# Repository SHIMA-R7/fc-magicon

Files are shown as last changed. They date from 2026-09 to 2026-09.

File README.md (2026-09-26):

# FC-MAGICON

Waveshare Core2350B(RP2350B)1枚で作るファミコン用カセット。

- PRG・CHR を RP2350B がリアルタイムにエミュレート(マジコン。NROM/CNROM/UNROM/MMC1/MMC3 などをファームで実装)
- NSF 再生(バンク切り替え・WRAM 対応。拡張音源は PWM で46番に混ぜる)
- PC→FC 画面転送(PPU の読み出しに直接応答する FC-PICO 方式)

## 現状(2026-09-26)

- **基板 rev0.2 の設計が完了(2層、DRC エラー0・未接続0)。未発注・未実装。**
- ファームウェア: 動作確認用の `bus_test`(CPU バスでテスト ROM を返して音を鳴らす)と `chr_test`(PPU に CHR を返して画面に格子模様を出す)、
  マジコン本体の `magicon`(.nes を動かす。NROM/MMC1/UxROM/CNROM/MMC3/AxROM、PRG + CHR 384KB まで)を作成、ビルド済み。未実機。[`firmware/`](firmware/README.md)
- rev0.1 からの変更: USB の予備ランド(J6)、拡張音源の音量用の半固定抵抗 VR1(KOA KVSF637AC104)を追加、
  電源・音声の配線を太くした(+5V 0.8mm、VBUS 0.6mm、GND 0.5mm、+3V3 0.4mm、音声 0.4mm)、J5 の 12〜14番を GND に。
- ガーバー: [`kicad/FC-MAGICON_gerber_r0.2.zip`](kicad/FC-MAGICON_gerber_r0.2.zip)(発注の指定は下の「基板の発注」)
- 仕様書: [`docs/hardware_spec.pdf`](docs/hardware_spec.pdf)(rev0.2)

| 正面(部品面、本体の手前) | 背面 |
|---|---|
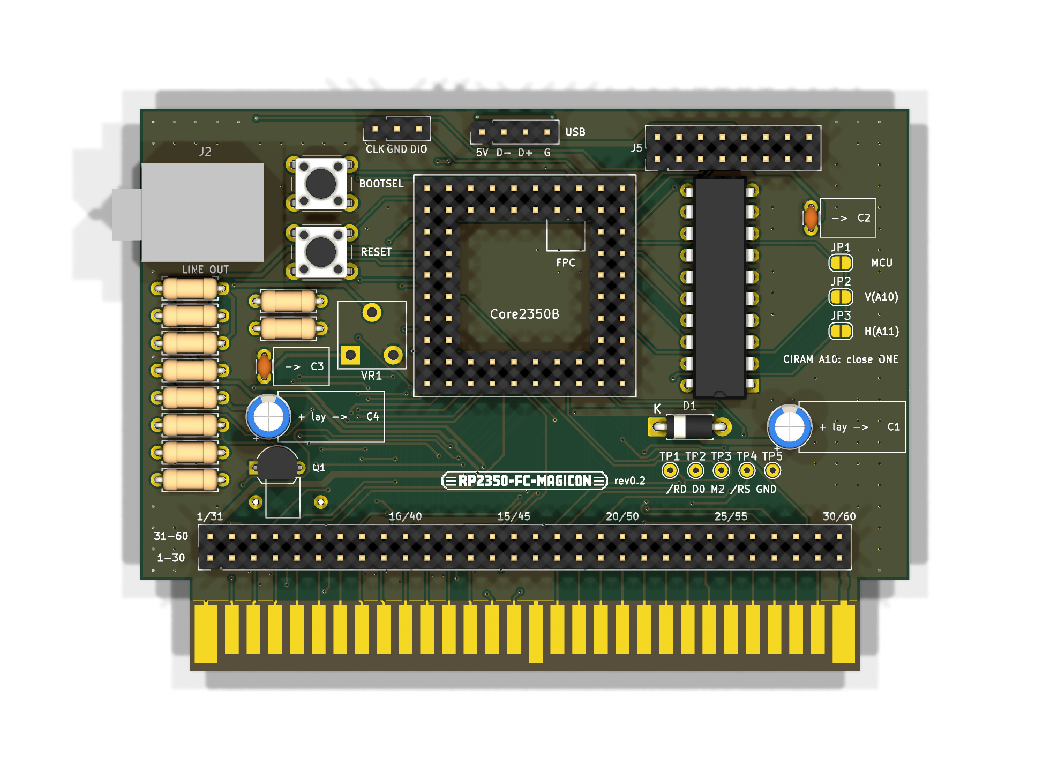
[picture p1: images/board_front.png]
front
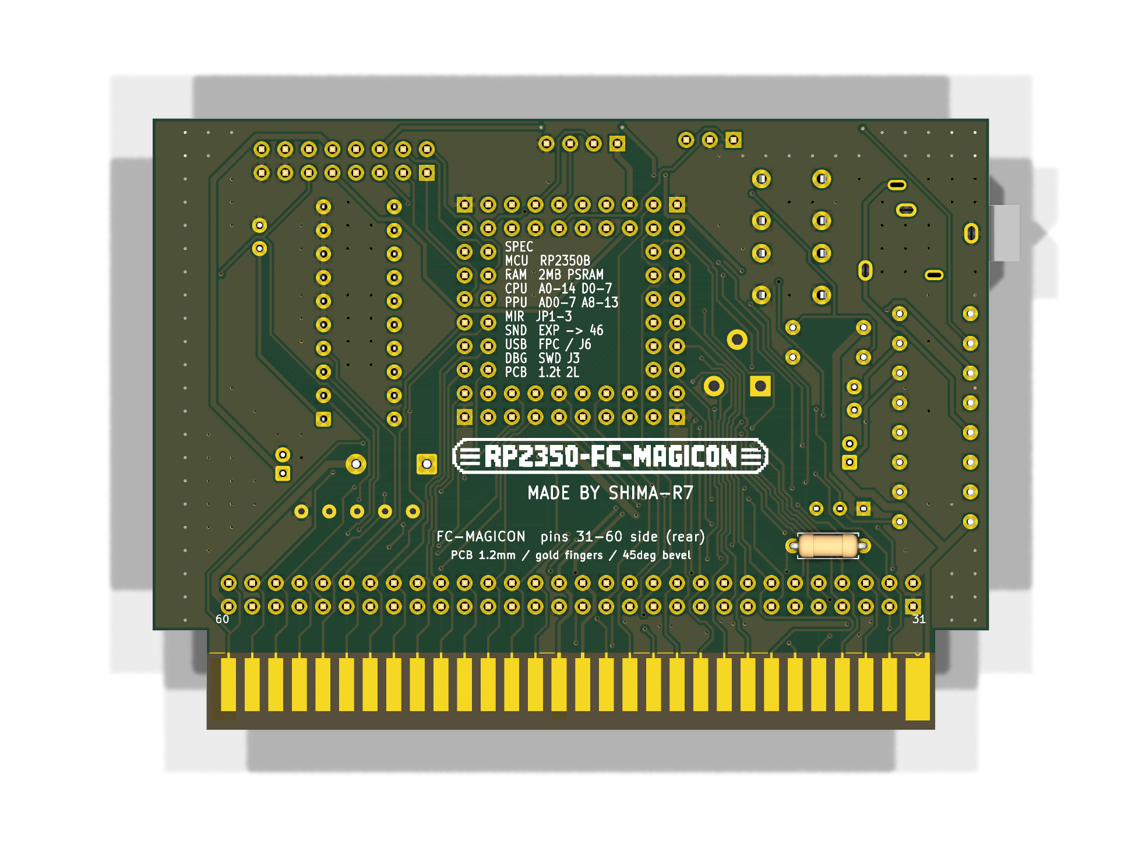
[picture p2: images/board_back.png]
back
|  |  |

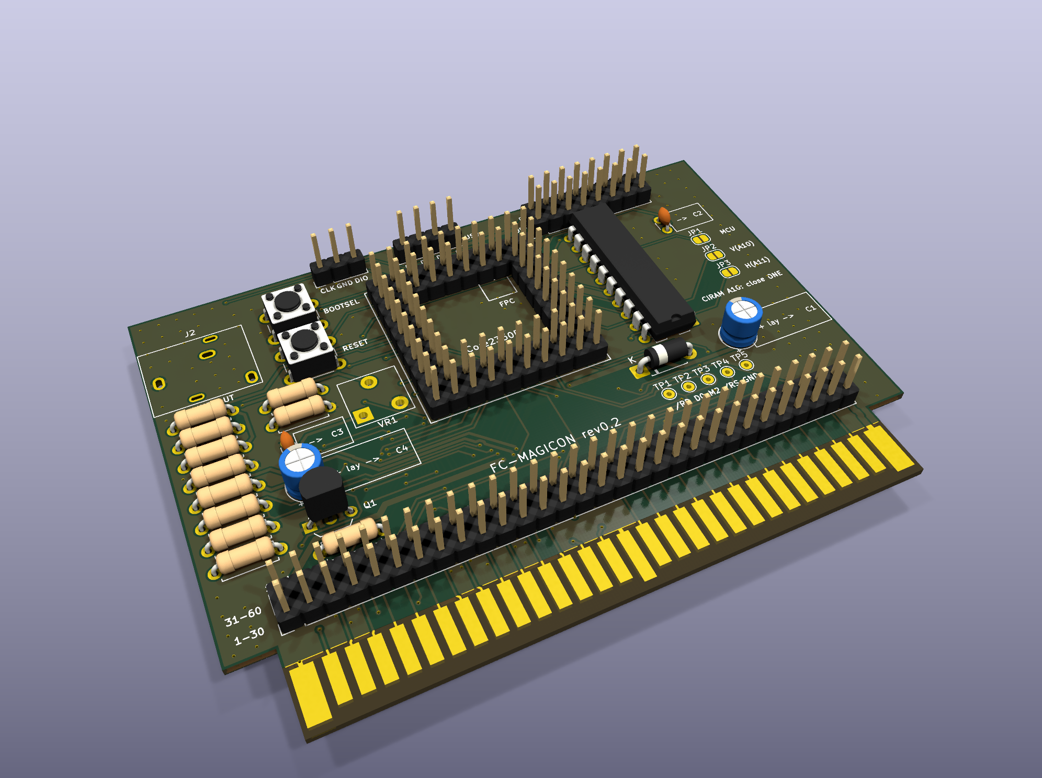
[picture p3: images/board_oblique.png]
oblique


## ファイル

| パス | 内容 |
|---|---|
| `kicad/gen_schematic.py` | 回路図の生成スクリプト(`python gen_schematic.py` → `FC-MAGICON.kicad_sch`) |
| `kicad/gen_footprints.py` | カセット端子と半固定抵抗(KOA KVSF637A)のフットプリントを生成 |
| `kicad/build_pcb.py` | 基板の部品配置(`place`)、配線の取り込みと GND ベタ(`import`)、一部の配線のやり直し(`reroute`) |
| `kicad/route.py` | Freerouting で自動配線(線幅のクラスを付ける) |
| `kicad/add_part.py` / `sync_nets.py` / `hand_route.py` | 配線済みの基板に部品を足す / パッドのネットを回路図に合わせる / 1本だけ手で引く |
| `kicad/export_gerbers.ps1` | DRC がエラー 0 のときだけガーバーを出して zip にする |
| `kicad/bom.py`, `print_bom.ps1` | 部品表(`bom.csv`)の作成と印刷 |
| `kicad/print_core2350b_pinmap.ps1`, `print_fit_check.ps1` | Core2350B のピン照合シート、実寸の現物合わせシートの印刷 |
| `kicad/check_nets.py`, `drc_summary.py` | 回路図の簡易チェック、DRC レポートの集計 |
| `3d/` | 基板の STEP(`FC-MAGICON_r0.2_parts.step` 部品あり / `_board.step` 基板だけ / `FC-MAGICON.step` 部品あり版を Autodesk で読み込んで書き出し直したもの)。`make_models.py` → `export_step.py`(KiCad の Python)で作り直す。原点は基板の左上、Y は上向き(基板は Y 0〜-65.8) |
| `kicad/print_part_guide.ps1` | 部品案内図(表・裏、原寸)の印刷 |
| `case/label/` | カセット表面のシール(`make_label.py` → `label.png`、`print_label.ps1` で A4 に印刷)。99 x 60.6mm、ケースの穴(J3/J5/J6/VR1/SW/Core2350B2)は原寸。L 判の光沢紙にきれいに刷る時は `make_label.py --px 48 --out label_print.png` → `powershell.exe -File print_label_photo.ps1`(光沢紙・写真品質) |
| `case/*.py` | ケースの元データ(下記)の寸法を調べたスクリプトと、基板の部品の占有範囲(`parts.json`) |
| `docs/` | ハードウェア仕様書(`build_spec.py` と `kicad/gen_spec_tables.py` で作る) |

KiCad 10、Freerouting 2.4.1 を使用。KiCad の Python(pcbnew)で実行するスクリプトと、ふつうの Python で実行するスクリプトがある(各ファイルの先頭に記載)。

## ライセンス

MIT(`LICENSE`)。外形の参考にしたデータ(下記「カセット外形の参考データ」)はこのリポジトリに含めていない。

## ピン割り当て

| GPIO | 信号 | カセット端子 | 備考 |
|---|---|---|---|
| 0-7 | CPU D0-D7 | 43,42,41,40,39,38,37,36 | |
| 8-22 | CPU A0-A14 | 13,12,11,10,9,8,7,6,5,4,3,2,33,34,35 | A0から連続 |
| 23 | /ROMSEL | 44 | |
| 24 | CPU R/W | 14 | |
| 25 | M2 | 32 | |
| 26-33 | PPU AD0-AD7 | 26,27,28,29,60,59,58,57 | /RD直前はアドレス下位、その後データ |
| 34-38 | PPU A8-A12 | 51,52,53,54,55 | 26-38で13ビット連続 |
| 39 | (基板上LED) | — | バスに使わない |
| 40 | PPU /RD | 17 | U2(74LVC245)経由 |
| 41 | PPU /WR | 47 | U2経由 |
| 42 | PPU A13 | 56 | U2経由 |
| 43 | CIRAM A10 出力 | 18 | JP1を閉じたとき |
| 44 | 拡張音源 PWM | 46へ混ぜる | |
| 45 | /IRQ 駆動 | 15 | Q1(NPN)でオープンコレクタ |
| 46 | 本体5V検出 | 30,31 を分圧 | Highになるまでバスに出力しない |

- PIO の32本窓: CPU 用ブロックは GPIO0-31、PPU 用ブロックは GPIO16-47。
- GPIO0-38 は 5V トレラント。GPIO40-47 は ADC 兼用で **5V 非トレラント**。
- PPU A0-A7(19-25, 50番)はつながない。
- CIRAM /CE(48)は /A13(49)に直結(R1 0Ω)。
- ミラーリング: JP1(MCU)/ JP2(A10=垂直)/ JP3(A11=水平)のどれか1つだけ閉じる。

## テスト用のランド(2.54mmピッチ、ピンヘッダー・ソケットどちらも可)

基板は規格(56.8mm)より 9mm 高い(90 × 65.8mm)。

**J4: カセット60ピン全部(2x30)** — 差し込み部のすぐ上(2026-09-26、2層に収めるため上辺から移動)
各列がカセット端子の真上にあり、端子から J4 まではほぼ真上への短い配線。上の列 = 31〜60番、下の列 = 1〜30番。
部品面(本体の手前)から見て左端が 1/31番、右端が 30/60番(シルクに列番号あり)。
RP2350 では使わない PPU A0-A7(19〜25番、50番)も出している。

**J5: 基板内部の信号(2x8)** — 上辺
部品面から見て左端が 1/2番。奇数番 = 下の列、偶数番 = 上の列。

| ピン | 信号 | ピン | 信号 |
|---|---|---|---|
| 1 | PPU /RD(3.3V、U2の後) | 2 | PPU /WR(3.3V) |
| 3 | PPU A13(3.3V) | 4 | CIRAM A10(GPIO43の出力) |
| 5 | 拡張音源 PWM(GPIO44) | 6 | PWM の RC フィルタの後 |
| 7 | /IRQ 駆動(GPIO45) | 8 | 本体5V検出(GPIO46) |
| 9 | +3.3V | 10 | VBUS(モジュールの電源) |
| 11 | CIRAM A10(18番へ行く線) | 12 | ライン出力(47kの前) |
| 13 | Q1 ベース | 14 | ライン出力(100Ωの後) |
| 15 | GND | 16 | GND |

TP1〜TP5(/RD、D0、M2、/ROMSEL、GND)はオシロのプローブ用。

## 基板発注前に確認すること

1. ~~**カセット端子の電源・音声・制御ピン。**~~ → 2026-09-26 ユーザーが麻雀カセット・本体で確認、問題なし。 信号線51本はダンパー(`../FC`)で実機確認済み。
   1,16(GND)・30,31(+5V)・15(/IRQ)・18(CIRAM A10)・45,46(音声)・47(/WR)・48(CIRAM /CE)・49(/A13)は
   nesdev の資料によるので、麻雀カセットと本体で導通を確認する。
2. ~~**45/46 の向き。**~~ → 2026-09-26 確認済み。 本体(HVC-CPU-07)で、どちらが 2A03 の音声回路につながっているか確認する。
3. ~~**本体の /IRQ プルアップの有無。**~~ → 2026-09-26 確認済み。 無ければ R6(10k)を実装する。
4. ~~Core2350B のヘッダー配置~~ → 2026-09-26 に照合シート(`kicad/print_core2350b_pinmap.ps1`)で、実物のシルクと全ピン一致を確認した。
   25.4mm角、外周2列、2.54mmピッチ。左・下・右・上がそれぞれ P1・P3・P4・P2。
5. ~~カセットの基板厚とエッジの寸法~~ → 参考データ(下記)から、厚み 1.2mm・差し込み部 78.4 × 10.7mm。
   正確に作るのはスロットに刺さる部分だけでよい。残りの外形は自由にし、ケースは3Dプリント(Bambu P1S)で作る。
6. **試作での実測。** PPU の /RD が下がってからデータを返すまでの時間。仮配線はせず、この基板(TP1〜TP5)で測る方針に変更。

## 基板の発注(JLCPCB)

`kicad/FC-MAGICON_gerber_r0.1.zip` をアップロードする(`kicad/export_gerbers.ps1` で作り直せる。DRC にエラーがあると止まる)。

| 項目 | 指定 |
|---|---|
| 層数 | 2 |
| 厚み | **1.2mm**(ファミコンのスロットに合わせる。1.6mm は入らない) |
| 金メッキ端子 | Gold Fingers: Yes |
| 面取り | 差し込み側 45°(finger chamfer) |
| 表面処理 | 金メッキ端子と組み合わせられるもの(発注画面で ENIG 指定が必要か確認する) |
| 数量 | 5枚(最小) |

- 外形は 90 × 65.8mm。差し込み部(78.4 × 10.7mm)の両脇は切り欠き。
- 端子部のレジストは、端子の上端から 0.6mm 上で止めてある(付け根側の配線はレジストで覆う)。

## カセット外形の参考データ(`ref/`)

| 出典 | ライセンス | 中身 |
|---|---|---|
| [Gumball2415/NES-Famicom-Cartridge-Dimensions](https://github.com/Gumball2415/NES-Famicom-Cartridge-Dimensions) | TAPR OHL 1.0 | HVC-TGROM-01 / HVC-CNROM-256K-01 の外形(KiCad)と FreeCAD 3Dモデル(.FCStd、STEP書き出し可) |
| [Keitark/fc-rom-vomitter](https://github.com/Keitark/fc-rom-vomitter) | ハード: CC BY-SA 4.0 | 60ピンのエッジのフットプリントと、実際に製造したファミコン用基板 |

- 標準のファミコン基板: 幅 90.0mm × 高さ 56.8mm(差し込み部 78.4 × 10.7mm を含む)、**厚み 1.2mm**、ピッチ 2.54mm。
- 市販カセットは 1〜30番がラベル面(本体の手前)。この基板は部品面(F.Cu)を手前に向けたので、F.Cu = 1〜30番、B.Cu = 31〜60番。
- ピン配置は fc-rom-vomitter の表とも一致した(30/31=+5V、1/16=GND、45=本体からの音声、46=本体へ戻す音声、48/49=/A13)。
- ファイルをそのまま流用する場合は、元のライセンスに従うこと。寸法(事実)を参照して自作するならその限りではない。

## ケース(3Dプリント)の元データ

[printables 860420「Nintendo Famicom Cartridge Shell」](https://www.printables.com/model/860420-nintendo-famicom-cartridge-shell)(CC BY 4.0)。
これは [masible/famicom-everdrive-n8-shell-with-usb](https://github.com/masible/famicom-everdrive-n8-shell-with-usb)(hadessuk、CC BY)を
標準の基板向けにしたリミックスで、さらに元は Blackchamber の [Thingiverse 117607](https://www.thingiverse.com/thing:117607/)(CC BY)。
改変版を公開するときは、この3つの作者の表記を残す。

## 注意

- USB だけで給電しているときに本体のバスへ出力すると、電源の入っていない本体に電流が逆流する。
  ファームは `FC_5V_SENSE` が High になるまで、全ピンを入力にしておく。
- RP2350 のエラッタ E9 に注意。バスのピンでは内部プルダウンを使わない。
- Q1 の 2SC1815 は、平らな面から見て E-C-B。

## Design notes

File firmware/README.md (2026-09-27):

# FC-MAGICON ファームウェア

pico-sdk 2.3.1、RP2350B(Waveshare Core2350B2)。ボード定義は `boards/fc_magicon.h`
(SDK の `waveshare_core2350b.h` から、UART・I2C・SPI の既定ピンを外したもの。GPIO0/1 などはバスに使っているため)。

## ビルド

```
pwsh -File build.ps1
```

- 道具は `C:\Users\Yugo\pico` に置いてある(2026-09-26 に GitHub の公式リリースから取得):
  xPack arm-none-eabi-gcc 15.2.1、CMake 4.4.3、Ninja 1.13.2、pico-sdk 2.3.1 + TinyUSB、picotool / pioasm 2.3.1。
- パスに日本語が入るとビルドできないので、`C:\Users\Yugo\pico\work\fc-magicon` にコピーしてからビルドする。
- できた `.uf2` は `out/` に入る。

## 書き込み

1. Core2350B を USB(FPC アダプター)で PC につなぐ。
2. 基板の **BOOTSEL** を押したまま **RESET** を押して離す → PC に「RP2350」ドライブが出る。
3. `out/bus_test.uf2` をそのドライブにコピーする。

## bus_test(基板が届いて最初に試す)

CPU バスの読み出し・書き込みが正しく動くかを確かめる。PPU 側(CHR)はまだ返さない(画面は出ない)。

| 動作 | 内容 |
|---|---|
| 起動直後 | バスのピンをすべて入力(プル無し)にする。本体の 5V(GPIO46)が来るまで、LED が速く点滅し、USB シリアルに `waiting for Famicom 5V` を出す |
| 本体の電源が入ったら | 250MHz で動かし、$8000-$FFFF にテスト ROM(16KB、`gen_test_rom.py`)を返す |
| テスト ROM | 矩形波 1ch で約 440Hz を鳴らし続け、ループのたびに $8000 へ書き込む |
| RP2350B | その書き込みを数え、65536 回ごとに LED を反転(約 0.5 秒ごと)。USB シリアルに毎秒の読み出し・書き込みの回数を出す |

### 立ち上げの手順

1. **モジュールを載せる前に**、テスターで +5V(J4 の 30/60 列など)と GND の間がショートしていないか確かめる。
2. モジュールを載せ、**本体に挿さずに** USB だけつなぐ。LED が速く点滅し、シリアルに `waiting for Famicom 5V` が出れば、
   RP2350B は動いていて、バスには何も出力していない。
3. 本体の電源を切った状態で挿し、電源を入れる。
   - **ピーという音が出て、LED が約 0.5 秒ごとに点滅**すれば、CPU バスの読み出しと書き込みが動いている。
   - シリアルの `writes/s` はおよそ 12 万(1 ループ 15 サイクル、CPU 1.79MHz)。
   - 音が出ない時は、本体のリセットボタンを押す(RP2350B の起動が本体の CPU に間に合わなかった可能性)。
4. うまくいかない時は、TP3(M2)・TP4(/ROMSEL)をオシロで見て、/ROMSEL が動いているか確かめる。

## chr_test(bus_test が動いたら次に試す)

PPU 側の応答、特に「/RD が下がる直前に AD0〜AD7 から下位アドレスを読む」方式が実機で成り立つかを確かめる。

| 動作 | 内容 |
|---|---|
| CPU 側 | テスト ROM(`gen_chr_rom.py`)がパレットとネームテーブル(0〜255 を繰り返し)を書き、背景を表示し、音を鳴らす |
| PPU 側 | パターンテーブル($0000-$1FFF)の読み出しに、RP2350B が作った CHR を返す。A13 = 1(ネームテーブル)の時は出さない |
| タイル | タイル t は下位2ビットの色で塗り、上辺と左端は色1(白)の線 |
| CIRAM A10 | GPIO43 を Low に固定(JP1 を閉じた時は1画面ミラー)。JP2/JP3 でもよい |

**判定**

- 画面に **4色の縦縞と、8ドットごとの白い格子** が並べば、下位アドレスの読み取りは正しい。
- 模様が崩れる・縞の順番が乱れる時は、読み取るタイミングがずれている。TP1(/RD)と TP2(PPU D0)をオシロで見て、
  /RD が下がってからデータが出るまでの時間と、PPU がデータを取り込むまでの余裕を測る。
- USB シリアルの `ppu chr/s` は、表示中におよそ 500 万前後になる見込み(1 ラインあたりの読み出し × 240 ライン × 60 フレーム)。

## magicon(マジコン本体。bus_test・chr_test が動いたら)

フラッシュに書いた `.nes` をファミコンで動かす。

```
pwsh -File load_rom.ps1 game.nes
```

- Core2350B を USB でつないだまま実行する。magicon が動いていれば picotool が自動で書き込みモードにし、書いた後に再起動する
  (ほかのファームウェアの時は BOOTSEL を押したまま RESET を押して離してから)。書いたらファミコンの電源を入れ直すかリセット。
- ROM はフラッシュの 8MB 目に置く(`tools/nes_pack.py` が「"FCMG" + 長さ + 合計」を前に付ける)。ファームウェアを書き直しても消えない。
- ROM が無い・壊れている・対応していない時は、chr_test と同じ試験画面を出す。USB シリアルに理由を出す。

| 項目 | 内容 |
|---|---|
| マッパー | 0 NROM、1 MMC1、2 UxROM、3 CNROM、4 MMC3、7 AxROM、87 Jaleco J87(ツインビー)、184 Sunsoft-1(アトランチスの謎) |
| 大きさ | PRG + CHR の合計 384KB まで(RP2350 の SRAM に写す)。SMB3(256K + 128K)まで入る。512KB の MMC3 はまだ |
| CHR-RAM | 8KB。CPU の `$2006`/`$2007` への書き込みを横から読んで作る(PPU の /WR ではアドレスが読めないため) |
| WRAM | `$6000-$7FFF` 8KB。**電源を切ると消える**(バッテリーのセーブはまだ) |
| ミラーリング | PIO2 が PPU A10 / A11 を CIRAM A10(GPIO43)へ写す。**JP1 を閉じた時だけ効く**(JP2 / JP3 は固定) |
| MMC3 の IRQ | PPU の読み出しで A12 の立ち上がりを数え、GPIO45 → Q1 で /IRQ を出す |
| USB シリアル | ROM の情報と、1 秒ごとの CPU サイクル(約 179 万)・PPU 読み出し・書き込みの回数 |

CPU バスは bus_test と違い **M2 で起きて全サイクルを拾う**(`magicon/cpu_m2.pio`)。M2 が上がって 80ns 後にアドレスを読み、
書き込みサイクルは M2 が下がった所でデータをもう一度読む。bus_test(/ROMSEL で起きる)が動いて magicon が動かない時は、
この 80ns と、書き込みデータを読む時点を疑う。

### ゲーム選択メニュー

```
pwsh -File load_rom.ps1 -Library D:\roms            # フォルダーの .nes / .nsf を全部(動かないものは飛ばす)
pwsh -File load_rom.ps1 -Library a.nes b.nsf -Remote # ファイルを並べても。-Remote で「REMOTE DESKTOP」も入れる
```

- 何本かをまとめてフラッシュの ROM 置き場(8MB 目から 8MB 分、127 本まで)に書き、起動時にメニューから選ぶ。
  形式は `tools/nes_pack.py --library`: `"FCLB"` + 目次(題名 48 + 位置 + 長さ + 合計、64 バイト × 数)+ 中身。
  題名はファイル名(大文字)か NSF の曲集の題名、同じフォルダーの `titles.txt`(`ファイル名=題名`)で変えられる。題名順に並ぶ。
- メニュー(`magicon/gen_menu_driver.py` → `menu_driver.h`)は NROM として動く。ファームが起動時に題名を入れて組み立てる
  (`cart_load_menu`)。フォントとロゴは NSF プレイヤーの CHR。上下 = 選ぶ(押し続けると続けて動く)、左右 = 20 項目ずつ、A / START = 始める。
- 選ぶと、本体側は本体 RAM($0300)に写した小さなプログラムに移って `$5FF0` に番号を書き、1.5 秒待ってから `JMP ($FFFC)`。
  ファームはその番号をウォッチドッグのメモ(scratch[0])に残して再起動し、その ROM で起動し直す(今までの起動の流れをそのまま使う)。
- **本体の電源を入れ直すとメニューに戻る**: 5V が 50ms 続けて消えたら再起動する(USB から電源をもらっている時も)。
  本体のリセットボタンは、今のゲームの最初に戻るだけ。
- 1 本だけの書き方(`load_rom.ps1 game.nes`、`"FCMG"`)もそのまま使える。ライブラリが 1 本だけの時はメニューを出さない。
- 2026-09-27、PC の試験台(`sim/sim.exe ライブラリ.bin --press ...`)で確かめた: 手元の 12 本 + 画面転送の 13 項目 / 37 項目で、
  表示、押し続けの連続移動、左右のページ送り、選んで 1.5 秒後にマリオのタイトル・NSF プレイヤー・画面転送の待ち画面になること。
  **実機では未検証**(本体側が $0300 のプログラムで待っている間に RP2350 が再起動して間に合うか)。

### NSF プレイヤー

`.nsf` を書くと NSF プレイヤーとして起動する(`pwsh -File load_rom.ps1 music.nsf`)。

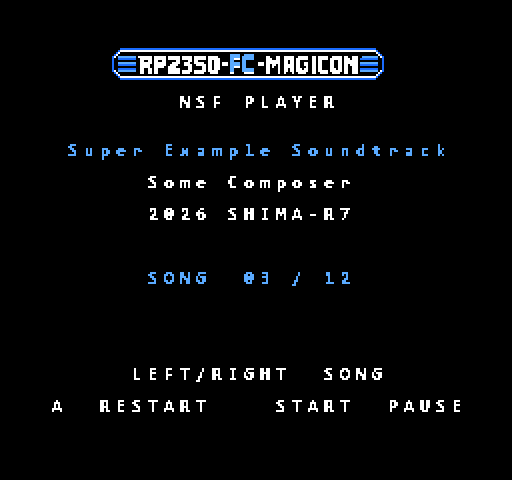
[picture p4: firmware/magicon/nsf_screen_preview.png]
NSF の画面(曲名などは例)


| 項目 | 内容 |
|---|---|
| 操作 | ←→ = 前 / 次の曲、A = 最初から、START = 一時停止 |
| 再生 | VBlank の NMI(約 60.1Hz)ごとに PLAY を呼ぶ。再生間隔が標準と違う NSF はテンポが変わる |
| バンク切り替え | `$5FF8-$5FFF`(4KB × 8)。384KB まで |
| 拡張音源 | **まだ鳴らない**(VRC6・FDS・N163 など。本体の 2A03 の音だけ出る) |
| 未対応 | load が `$8000` より下のバンク無し NSF、FDS 用の `$6000-$DFFF` を RAM にする NSF |

しくみ(ハードウェアの NSF プレイヤーでよく使われる形):

- 曲のデータは `$8000-$FFFF`、ドライバー(6502、`magicon/gen_nsf_driver.py` が作る)は `$5000-$5FFF` に置く。
  どちらも RP2350 の SRAM。`$5000-$5FFF` は本体側に何も無いので、カセットが自由に使える。
- ベクター(`$FFFA-$FFFF`)の読み出しだけ、曲のデータではなくドライバーの番地を返す。
- ドライバーは曲を始める時に APU を黙らせ、RAM と `$6000-$7FFF` を 0 にし、バンクを初期値に戻してから INIT を呼ぶ(NSF の決まり)。
  ドライバーの変数はゼロページではなく `$5F80-` に置く(NSF がゼロページを自由に使うため)。
- `magicon/test_nsf_driver.py` が、6502 エミュレーター(py65)でドライバーを動かして確かめる
  (INIT に渡る曲番号、毎フレームの PLAY、←→・A・START、RAM の初期化、バンク切り替え)。

### 画面転送(リモートデスクトップ)モード

`pwsh -File load_rom.ps1 -Remote` で、PC の画面をファミコンに映すモードで起動する。PC 側は:

```
python tools/remote_pc.py             # 灰色 4 階調(文字が読みやすい)。--color でカラー、--port COMx でポートを指定
python tools/remote_pc.py --dry-run 30   # カセット無しで、画面の取り込み + 変換の速さだけ測る
```

| ファミコン側 | PC 側 |
|---|---|
| 1コン 十字キー / A / B | マウス移動(押し続けると速くなる)/ 左クリック / 右クリック |
| 1コン SELECT / START | 画面全体を縮小 ⇔ カーソルのまわりを等倍 / 等倍の時にカーソルを追うか止めるか |
| ファミリーベーシックのキーボード | 同じ刻印のキー(JIS 配列の位置)。STOP / DEL = BackSpace、カナ = 半角/全角、CLR HOME = Home。SHIFT / GRPH(Alt)/ CTR はトグル(RETURN で SHIFT は戻る) |

キーボードのふるまいは、前に作った拡張端子 ⇔ USB 変換器([SHIMA-R7/Famicom-Expand-USB-Adapter](https://github.com/SHIMA-R7/Famicom-Expand-USB-Adapter)、実機で確かめたもの)に合わせた:
キーの並び(9 行 x 8)は nesdev と一致、列を選んでから読むまで 500us 待つ(300us は不安定だった)、1 キーずつのチャタリング対策(2 回続けて同じなら確定)、
トグル式の SHIFT / GRPH / CTR。`tools/test_keyboard_bridge.py` が、キーを実際には送らずにこのふるまいを確かめる。

- 使うのは Python に元からあるものと Pillow・numpy だけ(COM ポート・画面の取り込み・マウスとキーは Windows の API を ctypes で呼ぶ)。
- 入力が 0.5 秒届かない時(ケーブルが抜けた等)と止めた時は、押しっぱなしのキーとボタンを離す。
- PC 側の速さ(2026-09-27、この PC): 等倍 約 60fps、画面全体 灰色 約 30fps / カラー 約 23fps。
- USB の速さ(2026-09-27、Core2350B2 単体に `usb_test.uf2`): `tools/usb_bench.py` で 614KB/秒 = 最大 40.6 枚/秒(150 枚すべて届く)。
  `remote_pc.py` をそのまま流して 灰色 29.8 / カラー 20.0 枚/秒(PC 側で画面を作る速さで決まる)。
  はじめは画面を作る → 送るを順番にやっていて 15 枚/秒しか出なかったので、送受信を別スレッド(`IoThread`)にした。
- `usb_test/`: ファミコン無しで USB の速さを測るファームウェア。画面転送モードと同じ読み方で受け取って捨て、FCIN を 60 回/秒返す
  (何も押していない。予備の 2 バイトに受け取った枚数)。

- PPU が背景のパターンを読みに来るたびに、その位置の 8 ドットを RP2350 が返す(ネームテーブルは「行 % 8 * 32 + 列」の並びにし、
  読みに来たタイル番号と行の中の y から位置を割り出す。8 行ごとの組は、タイル行が 7 → 0 になる回数で数える)。
  256 x 240 ドットを 1 ドット単位で自由に描ける。色は 16 x 16 ドットごとに 4 色(うち 1 色は全体で共通)。
- 6502 のプログラム(`magicon/gen_remote_driver.py`)が VBlank ごとにパレット・属性・カーソル(スプライト)を PPU へ写し、
  1コンとファミリーベーシックのキーボード(HVC-007、9 行 x 8 キー)を読んで `$5F00-` に書く。
- USB: PC → `"FCFR"` + 絵 15360 + パレット 32 + 属性 64 + カーソル 3、カセット → PC: `"FCIN"` + 16 バイト(パッド・キーボード)。
- `tools/nesframe.py`: PC の画像を 1 枚にする(灰色 4 階調 / カラー。色の近さは CIELAB で測る)。
- `sim/test_remote.py`: PC の試験台で、届いた絵がファミコンの画面にドット単位でそのまま出るか(灰色・カラーとも違い 0)、
  カーソル、パッドとキーボードの読み取りを確かめる。

#### PC の音(画面転送モード)

PC で鳴っている音をカセットで鳴らす: GPIO44 の PWM → RC(R9)→ VR1 → R8 → カセット端子 46 番(本体の音声に混ぜる)、3.5mm ジャック(J2)にも出る。

- PC(`tools/pcaudio.py`): WASAPI のループバックで既定の再生デバイスの音を録り(ctypes、pip 不要)、32kHz モノラルにして
  `"FCAU"` + 形式 1 + サンプル数 2 + 中身 のパケットで画面の合間に送る。形式は 16 ビット(64KB/秒)/ 8 ビット(32KB/秒)/ IMA ADPCM(16KB/秒)。
  `remote_pc.py` の既定は USB 直結 16 ビット、Wi-Fi 8 ビット(画面の枚数を優先)。`--audio`、`--volume`、`--no-audio`。
- カセット(`magicon/audio.c`): 8192 サンプル(256ms)のリングを DMA(終わり無し + 読み出しリング、DMA タイマーで 32kHz)が
  PWM(10 ビット、244kHz)へ流し続ける。届いた音は 100ms 先に置き、150ms 以上溜まったら捨てる。鳴らし終えた所は無音で埋める。
- 2026-09-27、Core2350B2 単体 + C6(Wi-Fi)で、GPIO44 → 1kΩ → 10µF → イヤホンで聞いた(`tools/audio_bench.py` のドレミ)。
  ADPCM は「サー」という雑音が分かる、16 ビットがいちばん綺麗、8 ビットは少し震えるが ADPCM より良い。溜まり具合は 98〜115ms で安定。
  `pcaudio.py --test`: ADPCM の往復 SN 比 32dB、ループバックで鳴らした 1kHz を 1001Hz として録れる。
- まだ: ファミコンの音声(46 番)に混ぜての確認、VR1・R8 での音量合わせ。

#### Wi-Fi で送る(ESP32-C6 のブリッジ)

```
PC ──Wi-Fi(TCP 5000番)── ESP32-C6(wifi_bridge/)──USB── J6 ── RP2350(USB ホスト)
python tools/remote_pc.py --tcp          # fc-magicon.local(C6 が mDNS で名乗る)へつなぐ。既定 25 fps
```

- `wifi_bridge/wifi_bridge.ino`: TCP と C6 の USB(Serial/JTAG)の間でバイトを素通しする。TCP がつながるまで USB に IP を出す。
  Wi-Fi の SSID とパスワードは `wifi_secrets.h`(`wifi_secrets.example.h` を写して書く。GitHub には上げない)。
  ビルドと書き込みは `pwsh -File wifi_bridge/build_bridge.ps1`(Arduino-ESP32 3.3.12、開発環境は `C:\Users\Yugo\esp`)。
- 手持ちの C6 N4 ボードは、QIO / 80MHz だとフラッシュの読み出しが化けて起動しない。ブートローダーは DIO / 40MHz、
  アプリはコンストラクターでフラッシュ(SPI1)を 40MHz に落とす。電源が弱めで、一度ブラウンアウトを繰り返した(USB の挿し直しで直った)。
- `tools/wifi_bench.py`: PC をカセットの代わりに C6 の USB につなぎ、Wi-Fi → USB の速さと中身を確かめる。
  2026-09-27 の結果: 最大 462KB/秒 = 30.6 枚/秒。25 枚/秒で送ると 1 枚の遅れは 中央 37ms・最大 81ms、中身の食い違い 0、
  逆向き(FCIN)も全部届く。`remote_pc.py --tcp` をそのまま流して 灰色 24.5 / カラー 19.9 枚/秒(カラーは PC の変換で決まる)。
- `host_test/`: RP2350 を USB ホストにして C6 から受け取る試験(ファミコン無し)。`tools/host_bench.py` で測る。
  2026-09-27 の結果(Core2350B2 単体 + C6、ジャンパー線): **420KB/秒 = 27.8 枚/秒、500 枚すべて届く**。20 枚/秒で送るとそのまま追従。
  - TinyUSB は **0.21.0** が要る(`C:\Users\Yugo\pico\tinyusb-0.21.0`、build.ps1 が host_test だけこれでビルドする)。
    pico-sdk 付属の 0.18 は、RP2350 ホストのバルク転送が「割り込み用の窓口」で 1ms に 64 バイト = 64KB/秒止まりで、
    返事のパケットに受け取ったデータが混ざって化けた。0.21 は EPX を順番に回す作りになっている。
  - 0.21 と pico-sdk 2.3.1 の組み合わせでは、CDC の受信 FIFO の mutex が初期化されず `tuh_cdc_read` が止まったので、
    `tusb_config.h` で `CFG_TUSB_OS = OPT_OS_NONE`(と `tusb_time_millis_api`)にした。
  - `gpio_xor_mask64` / `gpio_put`(RP2350 では GPIO コプロセッサー命令)で LED を触ると NOCP の HardFault で止まったので、
    LED は SIO のレジスターを直接たたく(magicon では同じ関数で止まっていないので、原因はまだ分かっていない)。
  - 調べるのに debugprobe(Pico、`debugprobe_on_pico.uf2` v2.3.1)+ xPack OpenOCD 0.12.0-7(`C:\Users\Yugo\pico\openocd`)で SWD を使った。
    SWD からのリセット(`reset`・ウォッチドッグ)は起動がおかしくなるので、書いた後は電源を入れ直す。
- **`magicon_wifi.uf2`**: magicon の画面転送モードを USB ホストで動かす版(同じ `magicon/main.c` を `MAGICON_USB_HOST=1`、
  TinyUSB 0.21 でビルド。設定は `magicon/usb_host/tusb_config.h`)。J6 の C6 から画面を受け取り、入力(FCIN)を返す。
  - pico-sdk の USB シリアルはアプリが TinyUSB のホストを使うと丸ごと無効になるので、1 つのファームウェアに PC 直結と
    Wi-Fi の両方は入れていない。Wi-Fi で使う時は `magicon_wifi.uf2`、PC 直結・ROM の書き込みは `magicon.uf2`。
  - `magicon_wifi` の時は USB シリアルも picotool の自動書き込みモードも無い。書き換えは BOOTSEL + RESET で。
  - 2026-09-27 に Core2350B2 単体 + C6 で、Wi-Fi から送った 1 枚が裏画面(`rom` の中)にそのまま入ることを確かめた
    (GPIO46 を 3V3 につないで 5V の代わりにした。ファミコンが無いので 2 枚目以降と FCIN は未確認)。
  つなぎ方は J6 の 2(D-)→ C6 の GPIO12、3(D+)→ GPIO13、4 → GND。C6 は別の USB 電源で動かす
  (J6 の VBUS から取ると、Wi-Fi の電流が本体の 5V に乗る)。J6 と FPC の USB に同時に機器をつながない。

## PC で試す(sim)

magicon のロジック(`magicon/cart.c`)を PC でビルドし、ファミコンのエミュレーター [agnes](https://github.com/kgabis/agnes)(MIT、`sim/agnes/`)の
カセットとして動かす。CPU の全サイクルと PPU の読み出しを、実機の PIO と同じ形の値にして `cart.c` に渡すので、
**実機のファームウェアと同じコードのロジック**(マッパー、CHR-RAM の横読み、MMC3 の IRQ、NSF プレイヤー)を試せる。
試せないのは PIO のタイミング(ナノ秒単位)だけ。

```
pwsh -File sim/build_sim.ps1                       # Zig(C:\Users\Yugo\pico\zig)でビルド → sim/sim.exe
python sim/run_compare.py game1.nes game2.nes ...    # magicon と agnes 自身のマッパーで動かし、画面を毎フレーム比べる
sim/sim.exe music.nsf --frames 600 --wav --press "200:R:3" --out DIR   # 画面(BMP)と音(WAV)を書く
```

- agnes は音が無いので、`sim/apu.c` で本体の音源(パルス 2・三角・ノイズ。DMC は無し)を作って WAV にする。
- agnes はスプライトの絵を 1 ドットごとに読むので、magicon のモードでは実機と同じ 257〜320 ドット目の読み出しを別に流す
  (MMC3 の A12 の数え方を実機に近づけるため)。`sim/patch_agnes.py` が agnes にこの差し込み口を足す。
- 2026-09-27 の結果(手元で吸い出した 12 本。ROM はリポジトリに入れない):
  マッパー 0/1/2/4 の 8 本は、agnes 自身のマッパーと **1200 フレームすべて画面が一致**(SMB3 の MMC3 の IRQ、DQ2/DQ3 の CHR-RAM を含む)。
  agnes に無いマッパー 3/87/184(グラディウス、テトリス、ツインビー、アトランチスの謎)は magicon だけで動かして、画面を目で確かめた。
- 試験用の NSF(`sim/make_test_nsf.py`、3 曲でバンク切り替えあり)で、NSF の `$5FF8` のバンク切り替えが効いていない抜けが見つかった(直した)。

## 次に作るもの

- NSF の拡張音源(RP2350 で合成して GPIO44 の PWM → 46番へ。VRC6 → FDS → N163 → 5B → MMC5 → VRC7 の順)
- バッテリーバックアップ(WRAM をフラッシュへ保存)
- 512KB を超える ROM(PSRAM)
- 画面転送(FC-PICO 方式)
- USB から ROM を送る(picotool を使わない)

## ファイル

| パス | 内容 |
|---|---|
| `bus_test/` | CPU バスの応答テスト(`cpu_bus.pio`、`gen_test_rom.py` → `test_rom.h`) |
| `chr_test/` | PPU の CHR 応答テスト(`ppu_chr.pio`、`gen_chr_rom.py` → `chr_rom.h`) |
| `magicon/` | マジコン本体(`cart.c` = マッパー・NSF とバスの応答、`cpu_m2.pio`、`mirror.pio`) |
| `magicon/gen_nsf_driver.py` | NSF ドライバー(6502)・画面・フォントとロゴの CHR を作る → `nsf_driver.h` |
| `magicon/test_nsf_driver.py` | NSF ドライバーを 6502 エミュレーターで確かめる(`pip install py65`) |
| `load_rom.ps1`、`tools/nes_pack.py` | .nes をフラッシュの ROM 置き場に書く |
| `tools/asm6502.py` | テスト ROM 用の小さな 6502 アセンブラ(Python の関数で書く、分岐先を計算する) |
| `boards/fc_magicon.h` | ボード定義 |
| `out/*.uf2` | ビルド済みのファームウェア |
| `wifi_bridge/` | 画面転送の Wi-Fi ブリッジ(ESP32-C6、Arduino)。`tools/wifi_bench.py` で速さを測る |

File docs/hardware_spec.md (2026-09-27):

# FC-MAGICON ハードウェア仕様書 rev0.2

作成 2026-09-26。基板 rev0.2(ガーバー `FC-MAGICON_gerber_r0.2.zip`)の時点の仕様。未発注・未実装。

rev0.1 からの変更: USB の予備ランド J6 を追加、拡張音源の音量用に半固定抵抗 VR1(KOA KVSF637AC104)を追加、電源・音声の配線を太くした、J5 の 12〜14番を GND に変更。

## 1. 概要

ファミコン(HVC-001、本体基板 HVC-CPU-07 で確認)のカセットスロットに挿す、自作のカセット基板。
マイコンモジュール Waveshare Core2350B2(RP2350B)1個で、次の3つを行う。

- **マジコン**:PRG(CPU 側)と CHR(PPU 側)を RP2350B がリアルタイムに返す。マッパーはファームで実装する(NROM / CNROM / UNROM / MMC1 / MMC3 など)。
- **NSF 再生**:本体の 2A03 に NSF のプログラムを実行させる。バンク切り替え・WRAM 対応。拡張音源は PWM で本体の音声に混ぜる。
- **画面転送**:PPU の読み出しに直接応答する方式(FC-PICO と同じ考え方)で、PC から送った画像を出す。

PC とは Core2350B の USB(付属の FPC-USB アダプター)でつなぐ。

## 2. 構成

| 経路 | 内容 |
|---|---|
| CPU バス(26本) | カセット端子 → Core2350B の GPIO0〜25 に直結(D0〜D7、A0〜A14、/ROMSEL、R/W、M2) |
| PPU バス | AD0〜AD7・A8〜A12 → GPIO26〜38 に直結。/RD・/WR・A13 → U2(74LVC245)→ GPIO40〜42 |
| ミラーリング | GPIO43 → JP1 → CIRAM A10(18番)。JP2/JP3 で PPU A10/A11 に固定もできる |
| /IRQ | GPIO45 → R4 → Q1 → /IRQ(15番) |
| 電源 | 本体 +5V(30・31番)→ D1 → Core2350B の VBUS → モジュール内 LDO → 3.3V → U2 |
| 本体 5V 検出 | +5V → R2/R3 分圧 → GPIO46 |
| 音声 | 45番 → R7(0Ω)→ 46番。GPIO44 の PWM → R9/C3 → VR1(音量)→ R8 → 46番。46番 → C4 → R10/R11 → J2(3.5mm ライン出力) |
| PC | Core2350B の USB(付属の FPC-USB アダプター)。同じ D+/D- を J6(予備ランド)にも出している |
| テスト | J4(カセット60ピン全部、端子の真上)、J5(内部信号)、J3(SWD)、TP1〜TP5 |

## 3. 主要部品

| 記号 | 部品 | 役割 |
|---|---|---|
| U1(P1〜P4) | Waveshare Core2350B2 | RP2350B(QFN-80、GPIO 48本)、16MB フラッシュ、2MB PSRAM、LDO(ME6217C33)、12MHz 水晶。25.4mm 角、外周2列 64ピン |
| U2 | SN74LVC245AN(DIP-20) | PPU の /RD・/WR・A13 を 5V → 3.3V。5V 非トレラントの GPIO40〜42 へ渡す |
| Q1 | 2SC1815(TO-92) | /IRQ をオープンコレクタで引き下げる |
| D1 | 1N4001〜1N4007(ショットキー 1A 推奨) | 本体 5V → モジュールの VBUS。USB 給電時の本体への逆流を防ぐ |
| J1 | 基板エッジ(金メッキ端子 60本) | ファミコンのカセットスロット |
| J2 | PJ-324M | 3.5mm ライン出力(モノラルを L/R 両方へ) |
| VR1 | KOA KVSF637AC104(100kΩ、上面調整) | 拡張音源の音量。足は ①③ が 5.0mm 間隔、② がその中央の 5.0mm 上(データシートの推奨取付穴、φ1.2) |

## 4. 電源

| 項目 | 値 |
|---|---|
| 供給元 | 本体の +5V(カセット端子 30・31番)。GND は 1・16番 |
| モジュールへの経路 | +5V → D1 → VBUS_MOD(モジュール P2-15 VBUS)→ モジュール内 LDO → +3V3 |
| VBUS_MOD の電圧 | 1N400x で約 4.3V、ショットキーなら約 4.6V(LDO の入力として十分) |
| +3V3 の使い道 | モジュールの 3V3 出力(P2-16)を U2 の電源と DIR に使う。C2 100nF をパスコンに |
| 平滑 | C1 10µF(VBUS_MOD) |
| USB 給電 | Core2350B の USB からも VBUS に入る。D1 があるので本体側の +5V へは流れない |
| 消費電流(見込み) | モジュール数十 mA 〜 100mA 程度(RP2350B のクロック次第)。本体の 7805 の範囲内 |

**逆流に注意**:USB だけで給電している時(本体の電源が切れている時)に RP2350B がバスへ出力すると、
電源の入っていない本体の IC に 3.3V が流れ込む。これを避けるため、本体の 5V を分圧して GPIO46 で監視する(7章)。

## 5. バスの接続と電圧

### 5.1 CPU バス(26本、すべて RP2350B に直結)

| 信号 | GPIO | 向き |
|---|---|---|
| CPU D0〜D7 | 0〜7 | 双方向(読み出し時だけ RP2350B が出力) |
| CPU A0〜A14 | 8〜22(A0 から連続) | 入力 |
| /ROMSEL | 23 | 入力(= !(A15 & M2)) |
| R/W | 24 | 入力 |
| M2 | 25 | 入力 |

### 5.2 PPU バス

| 信号 | GPIO | 向き・経路 |
|---|---|---|
| PPU AD0〜AD7(カセット端子の PPU D0〜D7) | 26〜33 | 双方向。/RD が下がる直前はアドレス下位 8 ビット、その後データ |
| PPU A8〜A12 | 34〜38 | 入力。GPIO26〜38 で 13 ビットのアドレスが連続する |
| PPU /RD | 40 | U2 経由の入力 |
| PPU /WR | 41 | U2 経由の入力 |
| PPU A13 | 42 | U2 経由の入力(カセット端子 56番、非反転) |
| PPU /A13 | — | CIRAM /CE(48番)へ R1(0Ω)で直結。RP2350B にはつながない |
| PPU A0〜A7(ラッチ後) | — | RP2350B では使わない。J4 には出してある |

### 5.3 電圧の扱い

| GPIO | 5V を受けられるか | この基板での使い方 |
|---|---|---|
| 0〜38 | 可(IOVDD に電源が入っている時) | 5V のバス信号を直接受ける |
| 39 | 可 | モジュール上の LED(470Ω)が付いているので使わない |
| 40〜47(ADC 兼用) | **不可** | 40〜42 は U2(3.3V 電源の 74LVC245)の後。43〜46 は出力専用か分圧後の入力。47 はモジュール上の PSRAM の CS |

- RP2350B の出力は 3.3V。2A03・PPU(NMOS)の入力は H を 2.0〜2.4V 程度から認識するので受けられる。
- U2:DIR = +3V3(A→B)、/OE = GND(常に有効)。A 側(5V)に /RD・/WR・A13、B 側(3.3V)から GPIO40〜42。空き入力 A4〜A8 は GND。74LVC は電源が無い時も入力に 5V を受けられる。
- PIO は1ブロックで連続 32本しか扱えないので、CPU 用は GPIO0〜31、PPU 用は GPIO16〜47 の窓を使う。

## 6. PPU アドレスの読み取り方

ファミコンの PPU は、アドレス下位 8 ビットとデータを同じ 8本(AD0〜AD7)で時分割する。
本体側の 74LS373 がアドレスをラッチし、カセットには PPU A0〜A7 として出てくるが、この基板ではそれを使わない。

- PIO で「/RD が High の間、AD0〜AD7 を読み続ける」ループを回し、/RD が下がった時点で最後に読んだ値を下位アドレスとする。
- 上位は A8〜A12(と A13)を直接読む。
- PPU の読み出しは約 372ns ごと(PPU クロック 5.37MHz の 2 クロック)。/RD が下がってからデータを出すまでの余裕が足りるかは**未検証**(TP1・TP2 で測る)。
- 足りない場合でも、画面転送(FC-PICO 方式)・自作ゲーム・NSF には影響しない。市販の CHR-ROM ゲームの動作に影響する。

## 7. 制御・周辺回路

### 7.1 本体 5V の検出

+5V → R2 15kΩ → FC_5V_SENSE(GPIO46)→ R3 22kΩ → GND。5V のとき 2.97V、4.75V のとき 2.82V。
ファームは GPIO46 が High になるまで、全てのバスのピンを入力にしておく。

### 7.2 /IRQ

GPIO45(IRQ_DRV)→ R4 4.7kΩ → Q1 ベース(R5 100kΩ で GND に引き下げ)。Q1 コレクタ → /IRQ(15番)、エミッタ → GND。
GPIO45 = High で /IRQ が Low(割り込み要求)。ベース電流は約 0.55mA。起動中は R5 で Q1 がオフ。
R6(10kΩ、+5V へのプルアップ)は未実装。本体側にプルアップがあることを確認済み。

### 7.3 ミラーリング(CIRAM A10、18番)

JP1〜JP3 のどれか1つだけをはんだで閉じる。

| ジャンパー | 18番につながるもの | 用途 |
|---|---|---|
| JP1 | GPIO43(CIRAM_A10_MCU) | ファームで切り替える(MMC1/MMC3 などのマッパー) |
| JP2 | PPU A10(53番) | 垂直ミラー固定 |
| JP3 | PPU A11(54番) | 水平ミラー固定 |

GPIO43 は 3.3V 出力。本体の VRAM が 3.3V を H と認識するかは実機で確認する。駄目なら JP2/JP3 を使う。

### 7.4 音声

| 部分 | 回路 | 値 |
|---|---|---|
| 素通し | 45番(本体からの音声)→ R7 0Ω → 46番(本体へ戻す) | 市販カセットと同じ |
| 拡張音源 | GPIO44 PWM → R9 1kΩ → EXP_AUDIO_RC(C3 10nF で GND)→ VR1 100kΩ(①=RC、③=GND、②=中点)→ R8 47kΩ → 46番 | RC の遮断周波数 約 15.9kHz。VR1 で音量 0〜最大。どこに回しても本体の音声ラインには 47kΩ 以上が付く |
| ライン出力 | 46番 → C4 10µF(+ 側が 46番)→ LOUT(R10 47kΩ で GND)→ R11 100Ω → J2 | 低域の遮断 約 0.34Hz。J2 は L/R に同じ信号 |

### 7.5 操作

| 部品 | 動作 |
|---|---|
| SW1 BOOTSEL | 押しながらリセットすると RP2350B が USB 書き込みモードになる |
| SW2 RESET | RP2350B の RUN を GND に落とす。**本体のリセットではない**(本体はリセットボタンで) |

## 8. デバッグ・テスト用

| 記号 | 内容 |
|---|---|
| J3 | SWD(1=SWCLK、2=GND、3=SWDIO)。debugprobe の Pico をつなぐ |
| J4 | カセット60ピン全部(2x30、2.54mm)。差し込み部のすぐ上で、各列が真下の端子と同じ信号。本体に入る高さなのでランドとして使う想定 |
| J5 | 内部信号(2x8、2.54mm)。上辺。12〜14番は GND(元の LOUT・Q1_B・LINE は2層に収めるために外した。J2・R10・R11・Q1 の足で測れる) |
| J6 | USB の予備ランド(1x4、2.54mm、1=5V(VBUS)、2=D-、3=D+、4=GND)。モジュールの FPC と同じ USB 信号。**FPC 側と同時に機器をつながない**。VBUS は本体給電時 D1 の後の約 4.3V |
| TP1〜TP5 | /RD、PPU D0、M2、/ROMSEL、GND。オシロのプローブ用(穴 0.7mm) |

## 9. 機械仕様

| 項目 | 値 |
|---|---|
| 外形 | 90.0 × 65.8mm(本体 90.0 × 55.1mm + 差し込み部 78.4 × 10.7mm)。規格の基板(56.8mm)より 9mm 高い |
| 厚み | 1.2mm |
| 端子 | 60本、2.54mm ピッチ。部品面(表)= 1〜30番、裏 = 31〜60番。部品面から見て左端が 1/31番 |
| 端子の寸法 | 信号 1.6 × 5.7mm。1・30・31番は 2.6mm 幅、1・16・30・31番は差し込み側へ 1mm 長い(先に接触) |
| 向き | 部品面を本体の**手前**に向けて挿す(市販カセットのラベル面と同じ側に 1〜30番) |
| レジスト | 端子部は抜いてある(端子の上端の 0.6mm 上から先端まで) |
| 部品 | 部品面。ただし R1 だけ裏面(Q1 を下へ倒して寝かせるため、2026-09-26 に移した)。スルーホール部品のみ(表面実装はソルダージャンパーと端子だけ) |
| シルク | 表面: ロゴ(幅 19.5mm)と「rev0.2」。裏面: ロゴ(34mm)・「MADE BY SHIMA-R7」・スペック表(モジュールのソケットの内側) |
| モジュールの高さ | ピンソケットで載せるので、基板から約 13mm |
| コンデンサー | C1〜C4 は足を曲げて右へ寝かせる前提。倒した本体の範囲は部品禁止(シルクに枠と「lay →」) |
| J2 | 3.5mm ジャックの差し込み口が左辺から約 3.6mm 外へ出る |
| ケース | printables 860420 のシェル(CC BY 4.0)を改造して、Bambu Lab P1S で 3D プリントする(2026-09-27 時点でユーザーが編集中) |

## 10. 基板の製造仕様

| 項目 | 値 |
|---|---|
| 層数 | 2(F.Cu / B.Cu)。GND ベタを両面に、GND スティッチングビアあり |
| 配線幅 | 信号 0.25mm(IC の足の間で最小 0.15mm)。+5V 0.8mm(端子31番から J4 への枝だけ 0.5mm)、VBUS_MOD 0.6mm、GND 0.5mm、+3V3 0.4mm、音声 0.4mm |
| クリアランス | 0.2mm |
| ビア | 径 0.6mm / 穴 0.3mm |
| 端子部 | 端子の隙間・両脇・先端は配線・ビア・ベタ禁止。配線はパッドの上端から入る |
| DRC | エラー 0、未接続 0(2026-09-26)。フットプリントをライブラリから書き換えた旨の通知 9件のみ |
| 発注 | JLCPCB(2026-09-27 の時点で発注済み・未着)。厚み 1.2mm、黒、HASL(有鉛)、Gold Fingers、差し込み側 45° 面取り、5枚 |

## 11. ファームウェアが守ること

1. **起動時は全バスピンを入力**にし、GPIO46(本体 5V 検出)が High になってから出力を許す。
2. CPU D0〜D7 を出力するのは、読み出しサイクル(/ROMSEL = Low かつ R/W = High、または $6000〜$7FFF の WRAM 読み出し)の間だけ。
3. PPU AD0〜AD7 を出力するのは、/RD = Low かつ A13 = Low(パターンテーブル)の間だけ。A13 = High(ネームテーブル)の時は本体の VRAM が出力する。
4. RP2350 のエラッタ E9:バスのピンで内部プルダウンを使わない。
5. GPIO39(LED)・GPIO47(PSRAM CS)をバスに使わない。
6. /IRQ は GPIO45 = High で要求、Low で解除。
7. 電源投入直後は本体の CPU が RP2350B の起動を待たずに動く。間に合わなければ本体のリセットボタンを押す。

## 12. 確認状況

| 項目 | 状態 |
|---|---|
| カセット端子の信号線 51本 | 自作ダンパー(FC フォルダ)で実機確認済み |
| 電源・音声・/IRQ・CIRAM 関係のピン | 資料2つ(nesdev、fc-rom-vomitter)と一致。2026-09-26 に麻雀カセット・本体で導通確認済み |
| 45/46番の向き、/IRQ のプルアップ | 2026-09-26 実機で確認済み |
| 差し込む向き(表裏) | 厚紙の実物合わせとテスターで確認済み |
| Core2350B のピン配置 | 照合シートで実物のシルクと全ピン一致を確認 |
| /RD → データの応答時間 | **未検証**(基板で TP1・TP2 を測る) |
| CIRAM A10 を 3.3V で駆動 | **未検証**(駄目なら JP2/JP3) |
| 拡張音源の音量 | VR1 で調整 |
| VR1 の足の配置 | データシート(KOA SF6、637A の推奨取付穴)どおり。実物が届いたら穴に合うか確認 |

## 13. 部品表

| 部品 | 数 | 記号 | フットプリント | メモ |
|---|---:|---|---|---|
| 10µF 電解 | 1 | C1 | CP_Radial_D5.0mm_P2.00mm | 16V以上、φ5 ピッチ2mm |
| 100nF セラミック | 1 | C2 | C_Disc_D3.0mm_W1.6mm_P2.50mm | U2 のパスコン |
| 10nF セラミック | 1 | C3 | C_Disc_D3.0mm_W1.6mm_P2.50mm | PWM の RC フィルタ |
| 10µF 電解 | 1 | C4 | CP_Radial_D5.0mm_P2.00mm | φ5 ピッチ2mm。+側=SOUND_OUT(四角パッド)。ライン出力の直流カット。1µFフィルムでも可 |
| 1N4001〜1N4007(ショットキー 1A があればそちら) | 1 | D1 | D_DO-41_SOD81_P7.62mm_Horizontal | 本体5V→モジュール。USB給電時の逆流防止。省略不可 |
| PJ-324M | 1 | J2 | PJ-324M | 3.5mm ステレオジャック(SHVC-SOUND-ESP32 と同じ) |
| ピンヘッダー 1x3 | 1 | J3 | PinHeader_1x03_P2.54mm_Vertical | SWD(debugprobe の Pico 用) |
| ピンヘッダー or ピンソケット 2x30 | 1 | J4 | PinHeader_2x30_P2.54mm_Vertical | カセット60ピンのブレイクアウト。必要な時だけでもよい |
| ピンヘッダー 2x8 | 1 | J5 | PinHeader_2x08_P2.54mm_Vertical | デバッグ用(内部信号) |
| ピンヘッダー 1x4(任意) | 1 | J6 | PinHeader_1x04_P2.54mm_Vertical | USB の予備ランド(5V/D-/D+/GND)。FPC 側と同時に機器をつながない |
| 2SC1815 | 1 | Q1 | TO-92_Inline_Wide | TO-92 NPN。足は平らな面から E-C-B。他の小信号NPNでも可(足順に注意)。下(J4 側)へ倒して付ける |
| 0Ω(ジャンパー線でも可) | 1 | R1 | R_Axial_DIN0207_L6.3mm_D2.5mm_P7.62mm_Horizontal | CIRAM /CE ← /A13。裏面に付ける(表は Q1 を倒す場所)。表の足先は短く切る |
| 15kΩ 1/4W | 1 | R2 | R_Axial_DIN0207_L6.3mm_D2.5mm_P7.62mm_Horizontal |  |
| 22kΩ 1/4W | 1 | R3 | R_Axial_DIN0207_L6.3mm_D2.5mm_P7.62mm_Horizontal |  |
| 4.7kΩ 1/4W | 1 | R4 | R_Axial_DIN0207_L6.3mm_D2.5mm_P7.62mm_Horizontal |  |
| 100kΩ 1/4W | 1 | R5 | R_Axial_DIN0207_L6.3mm_D2.5mm_P7.62mm_Horizontal |  |
| 10kΩ(未実装) | 1 | R6 | R_Axial_DIN0207_L6.3mm_D2.5mm_P7.62mm_Horizontal | 本体に /IRQ のプルアップが無い時だけ付ける |
| 0Ω(ジャンパー線でも可) | 1 | R7 | R_Axial_DIN0207_L6.3mm_D2.5mm_P7.62mm_Horizontal | 音声 45→46番の素通し |
| 47kΩ | 1 | R8 | R_Axial_DIN0207_L6.3mm_D2.5mm_P7.62mm_Horizontal | 拡張音源を46番に混ぜる抵抗(VR1 の中点から) |
| 1kΩ 1/4W | 1 | R9 | R_Axial_DIN0207_L6.3mm_D2.5mm_P7.62mm_Horizontal |  |
| 47kΩ 1/4W | 1 | R10 | R_Axial_DIN0207_L6.3mm_D2.5mm_P7.62mm_Horizontal |  |
| 100Ω 1/4W | 1 | R11 | R_Axial_DIN0207_L6.3mm_D2.5mm_P7.62mm_Horizontal |  |
| タクトスイッチ 6mm | 1 | SW1 | SW_PUSH_6mm | BOOTSEL |
| タクトスイッチ 6mm | 1 | SW2 | SW_PUSH_6mm | RESET(RP2350のRUN) |
| 74LVC245 DIP-20 | 1 | U2 | DIP-20_W7.62mm | SN74LVC245AN。5V入力を3.3Vへ。74HC/HCT245 では代用不可(5V入力に耐えない) |
| 半固定抵抗 100kΩ KOA KVSF637AC104 | 1 | VR1 | KOA_SF6_637A | 拡張音源の音量。上面調整、足 ①③ 5.0mm・② は 5.0mm 上 |
| Waveshare Core2350B2 | 1 | U1 |  | RP2350B、2MB PSRAM。付属のFPC-USBアダプターで PC とつなぐ |
| ピンソケット 2x8(2.54mm) | 4 | P1-P4 |  | Core2350B を載せる。モジュール側には 2x8 ピンヘッダー4個 |
| ピンヘッダー 2x8(2.54mm) | 4 | (モジュール側) |  | Core2350B の裏に付ける |
| ICソケット DIP-20 | 1 | (U2) |  | 任意 |
| PCB 90x65.8mm 2層 1.2mm | 1 |  |  | 金メッキ端子(Gold fingers)、差し込み側 45°面取り |

## 付録. ピン・接続の一覧(ネットリストから自動生成)

### カセット端子 J1(60ピン)

| 番 | 面 | 信号 | つながる先 |
|---:|---|---|---|
| 1 | 表(手前) | GND | GND(全部品共通) |
| 2 | 表(手前) | CPU_A11 | P3-5(GPIO19) |
| 3 | 表(手前) | CPU_A10 | P3-6(GPIO18) |
| 4 | 表(手前) | CPU_A9 | P3-3(GPIO17) |
| 5 | 表(手前) | CPU_A8 | P3-4(GPIO16) |
| 6 | 表(手前) | CPU_A7 | P3-2(GPIO15) |
| 7 | 表(手前) | CPU_A6 | P1-15(GPIO14) |
| 8 | 表(手前) | CPU_A5 | P1-16(GPIO13) |
| 9 | 表(手前) | CPU_A4 | P1-13(GPIO12) |
| 10 | 表(手前) | CPU_A3 | P1-14(GPIO11) |
| 11 | 表(手前) | CPU_A2 | P1-11(GPIO10) |
| 12 | 表(手前) | CPU_A1 | P1-12(GPIO9) |
| 13 | 表(手前) | CPU_A0 | P1-9(GPIO8) |
| 14 | 表(手前) | CPU_R/W | P3-12(GPIO24) |
| 15 | 表(手前) | /IRQ | Q1.2, R6.2 |
| 16 | 表(手前) | GND | GND(全部品共通) |
| 17 | 表(手前) | PPU_/RD | TP1.1, U2.2 |
| 18 | 表(手前) | CIRAM_A10 | J5.11, JP1.2, JP2.2, JP3.2 |
| 19 | 表(手前) | PPU_A6 | — |
| 20 | 表(手前) | PPU_A5 | — |
| 21 | 表(手前) | PPU_A4 | — |
| 22 | 表(手前) | PPU_A3 | — |
| 23 | 表(手前) | PPU_A2 | — |
| 24 | 表(手前) | PPU_A1 | — |
| 25 | 表(手前) | PPU_A0 | — |
| 26 | 表(手前) | PPU_D0 | P3-14(GPIO26), TP2.1 |
| 27 | 表(手前) | PPU_D1 | P3-13(GPIO27) |
| 28 | 表(手前) | PPU_D2 | P3-16(GPIO28) |
| 29 | 表(手前) | PPU_D3 | P3-15(GPIO29) |
| 30 | 表(手前) | +5V | D1.2, R2.1, R6.1 |
| 31 | 裏(奥) | +5V | D1.2, R2.1, R6.1 |
| 32 | 裏(奥) | M2 | P3-11(GPIO25), TP3.1 |
| 33 | 裏(奥) | CPU_A12 | P3-8(GPIO20) |
| 34 | 裏(奥) | CPU_A13 | P3-7(GPIO21) |
| 35 | 裏(奥) | CPU_A14 | P3-10(GPIO22) |
| 36 | 裏(奥) | CPU_D7 | P1-10(GPIO7) |
| 37 | 裏(奥) | CPU_D6 | P1-7(GPIO6) |
| 38 | 裏(奥) | CPU_D5 | P1-8(GPIO5) |
| 39 | 裏(奥) | CPU_D4 | P1-5(GPIO4) |
| 40 | 裏(奥) | CPU_D3 | P1-6(GPIO3) |
| 41 | 裏(奥) | CPU_D2 | P1-3(GPIO2) |
| 42 | 裏(奥) | CPU_D1 | P1-4(GPIO1) |
| 43 | 裏(奥) | CPU_D0 | P1-2(GPIO0) |
| 44 | 裏(奥) | /ROMSEL | P3-9(GPIO23), TP4.1 |
| 45 | 裏(奥) | SOUND_IN | R7.1 |
| 46 | 裏(奥) | SOUND_OUT | C4.1, R7.2, R8.2 |
| 47 | 裏(奥) | PPU_/WR | U2.3 |
| 48 | 裏(奥) | CIRAM_/CE | R1.2 |
| 49 | 裏(奥) | PPU_/A13 | R1.1 |
| 50 | 裏(奥) | PPU_A7 | — |
| 51 | 裏(奥) | PPU_A8 | P4-5(GPIO34) |
| 52 | 裏(奥) | PPU_A9 | P4-8(GPIO35) |
| 53 | 裏(奥) | PPU_A10 | JP2.1, P4-7(GPIO36) |
| 54 | 裏(奥) | PPU_A11 | JP3.1, P4-10(GPIO37) |
| 55 | 裏(奥) | PPU_A12 | P4-9(GPIO38) |
| 56 | 裏(奥) | PPU_A13 | U2.4 |
| 57 | 裏(奥) | PPU_D7 | P4-6(GPIO33) |
| 58 | 裏(奥) | PPU_D6 | P4-3(GPIO32) |
| 59 | 裏(奥) | PPU_D5 | P4-4(GPIO31) |
| 60 | 裏(奥) | PPU_D4 | P4-2(GPIO30) |

### Core2350B のピン(ヘッダー P1〜P4)

| ヘッダー-ピン | モジュールのピン | 信号 | つながる先 |
|---|---|---|---|
| P1-2 | GPIO0 | CPU_D0 | J1.43 |
| P1-4 | GPIO1 | CPU_D1 | J1.42 |
| P1-3 | GPIO2 | CPU_D2 | J1.41 |
| P1-6 | GPIO3 | CPU_D3 | J1.40 |
| P1-5 | GPIO4 | CPU_D4 | J1.39 |
| P1-8 | GPIO5 | CPU_D5 | J1.38 |
| P1-7 | GPIO6 | CPU_D6 | J1.37 |
| P1-10 | GPIO7 | CPU_D7 | J1.36 |
| P1-9 | GPIO8 | CPU_A0 | J1.13 |
| P1-12 | GPIO9 | CPU_A1 | J1.12 |
| P1-11 | GPIO10 | CPU_A2 | J1.11 |
| P1-14 | GPIO11 | CPU_A3 | J1.10 |
| P1-13 | GPIO12 | CPU_A4 | J1.9 |
| P1-16 | GPIO13 | CPU_A5 | J1.8 |
| P1-15 | GPIO14 | CPU_A6 | J1.7 |
| P3-2 | GPIO15 | CPU_A7 | J1.6 |
| P3-4 | GPIO16 | CPU_A8 | J1.5 |
| P3-3 | GPIO17 | CPU_A9 | J1.4 |
| P3-6 | GPIO18 | CPU_A10 | J1.3 |
| P3-5 | GPIO19 | CPU_A11 | J1.2 |
| P3-8 | GPIO20 | CPU_A12 | J1.33 |
| P3-7 | GPIO21 | CPU_A13 | J1.34 |
| P3-10 | GPIO22 | CPU_A14 | J1.35 |
| P3-9 | GPIO23 | /ROMSEL | J1.44, TP4.1 |
| P3-12 | GPIO24 | CPU_R/W | J1.14 |
| P3-11 | GPIO25 | M2 | J1.32, TP3.1 |
| P3-14 | GPIO26 | PPU_D0 | J1.26, TP2.1 |
| P3-13 | GPIO27 | PPU_D1 | J1.27 |
| P3-16 | GPIO28 | PPU_D2 | J1.28 |
| P3-15 | GPIO29 | PPU_D3 | J1.29 |
| P4-2 | GPIO30 | PPU_D4 | J1.60 |
| P4-4 | GPIO31 | PPU_D5 | J1.59 |
| P4-3 | GPIO32 | PPU_D6 | J1.58 |
| P4-6 | GPIO33 | PPU_D7 | J1.57 |
| P4-5 | GPIO34 | PPU_A8 | J1.51 |
| P4-8 | GPIO35 | PPU_A9 | J1.52 |
| P4-7 | GPIO36 | PPU_A10 | J1.53, JP2.1 |
| P4-10 | GPIO37 | PPU_A11 | J1.54, JP3.1 |
| P4-9 | GPIO38 | PPU_A12 | J1.55 |
| P4-12 | GPIO39 | (未接続) | — |
| P4-11 | GPIO40 | PPU_/RD_3V3 | U2.18 |
| P4-14 | GPIO41 | PPU_/WR_3V3 | U2.17 |
| P4-13 | GPIO42 | PPU_A13_3V3 | U2.16 |
| P4-16 | GPIO43 | CIRAM_A10_MCU | JP1.1 |
| P4-15 | GPIO44 | EXP_AUDIO_PWM | R9.1 |
| P2-2 | GPIO45 | IRQ_DRV | R4.1 |
| P2-4 | GPIO46 | FC_5V_SENSE | R2.2, R3.1 |
| P2-3 | GPIO47_PSRAM_CS | (未接続) | — |
| P1-1 | GND | GND | GND(全部品共通) |
| P2-1 | GND | GND | GND(全部品共通) |
| P2-5 | BOOTSEL | BOOTSEL | SW1.1 |
| P2-6 | SWD | SWD | J3.3 |
| P2-7 | USBD_N | USBD_N | J6.2 |
| P2-8 | GND | GND | GND(全部品共通) |
| P2-9 | USBD_P | USBD_P | J6.3 |
| P2-10 | SWCLK | SWCLK | J3.1 |
| P2-11 | RUN | RUN | SW2.1 |
| P2-12 | ADC_VREF | (未接続) | — |
| P2-13 | 3V3_EN | (未接続) | — |
| P2-14 | GND | GND | GND(全部品共通) |
| P2-15 | VBUS | VBUS_MOD | C1.1, D1.1, J6.1 |
| P2-16 | 3V3 | +3V3 | C2.1, U2.1, U2.20 |
| P3-1 | GND | GND | GND(全部品共通) |
| P4-1 | GND | GND | GND(全部品共通) |

### J4 ブレイクアウト(2x30)

列 k(左から 1〜30)の下の列 = カセット k 番、上の列 = カセット k+30 番。

| 列 | 下の列(ヘッダー番号) | カセット番・信号 | 上の列(ヘッダー番号) | カセット番・信号 |
|---:|---:|---|---:|---|
| 1 | 1 | 1: GND | 2 | 31: +5V |
| 2 | 3 | 2: CPU_A11 | 4 | 32: M2 |
| 3 | 5 | 3: CPU_A10 | 6 | 33: CPU_A12 |
| 4 | 7 | 4: CPU_A9 | 8 | 34: CPU_A13 |
| 5 | 9 | 5: CPU_A8 | 10 | 35: CPU_A14 |
| 6 | 11 | 6: CPU_A7 | 12 | 36: CPU_D7 |
| 7 | 13 | 7: CPU_A6 | 14 | 37: CPU_D6 |
| 8 | 15 | 8: CPU_A5 | 16 | 38: CPU_D5 |
| 9 | 17 | 9: CPU_A4 | 18 | 39: CPU_D4 |
| 10 | 19 | 10: CPU_A3 | 20 | 40: CPU_D3 |
| 11 | 21 | 11: CPU_A2 | 22 | 41: CPU_D2 |
| 12 | 23 | 12: CPU_A1 | 24 | 42: CPU_D1 |
| 13 | 25 | 13: CPU_A0 | 26 | 43: CPU_D0 |
| 14 | 27 | 14: CPU_R/W | 28 | 44: /ROMSEL |
| 15 | 29 | 15: /IRQ | 30 | 45: SOUND_IN |
| 16 | 31 | 16: GND | 32 | 46: SOUND_OUT |
| 17 | 33 | 17: PPU_/RD | 34 | 47: PPU_/WR |
| 18 | 35 | 18: CIRAM_A10 | 36 | 48: CIRAM_/CE |
| 19 | 37 | 19: PPU_A6 | 38 | 49: PPU_/A13 |
| 20 | 39 | 20: PPU_A5 | 40 | 50: PPU_A7 |
| 21 | 41 | 21: PPU_A4 | 42 | 51: PPU_A8 |
| 22 | 43 | 22: PPU_A3 | 44 | 52: PPU_A9 |
| 23 | 45 | 23: PPU_A2 | 46 | 53: PPU_A10 |
| 24 | 47 | 24: PPU_A1 | 48 | 54: PPU_A11 |
| 25 | 49 | 25: PPU_A0 | 50 | 55: PPU_A12 |
| 26 | 51 | 26: PPU_D0 | 52 | 56: PPU_A13 |
| 27 | 53 | 27: PPU_D1 | 54 | 57: PPU_D7 |
| 28 | 55 | 28: PPU_D2 | 56 | 58: PPU_D6 |
| 29 | 57 | 29: PPU_D3 | 58 | 59: PPU_D5 |
| 30 | 59 | 30: +5V | 60 | 60: PPU_D4 |

### J5 デバッグ(2x8)

| ピン | 信号 | つながる先 |
|---:|---|---|
| 1 | PPU_/RD_3V3 | P4-11(GPIO40), U2.18 |
| 2 | PPU_/WR_3V3 | P4-14(GPIO41), U2.17 |
| 3 | PPU_A13_3V3 | P4-13(GPIO42), U2.16 |
| 4 | CIRAM_A10_MCU | JP1.1, P4-16(GPIO43) |
| 5 | EXP_AUDIO_PWM | P4-15(GPIO44), R9.1 |
| 6 | EXP_AUDIO_RC | C3.1, R9.2, VR1.1 |
| 7 | IRQ_DRV | P2-2(GPIO45), R4.1 |
| 8 | FC_5V_SENSE | P2-4(GPIO46), R2.2, R3.1 |
| 9 | +3V3 | C2.1, P2-16(3V3), U2.1, U2.20 |
| 10 | VBUS_MOD | C1.1, D1.1, J6.1, P2-15(VBUS) |
| 11 | CIRAM_A10 | J1.18, JP1.2, JP2.2, JP3.2 |
| 12 | GND | GND(全部品共通) |
| 13 | GND | GND(全部品共通) |
| 14 | GND | GND(全部品共通) |
| 15 | GND | GND(全部品共通) |
| 16 | GND | GND(全部品共通) |

### 周辺部品の接続

| 部品-ピン | 信号 |
|---|---|
| U2-1 (DIR) | +3V3 |
| U2-2 (A1) | PPU_/RD |
| U2-3 (A2) | PPU_/WR |
| U2-4 (A3) | PPU_A13 |
| U2-5 (A4) | GND |
| U2-6 (A5) | GND |
| U2-7 (A6) | GND |
| U2-8 (A7) | GND |
| U2-9 (A8) | GND |
| U2-10 (GND) | GND |
| U2-11 (B8) | (未接続) |
| U2-12 (B7) | (未接続) |
| U2-13 (B6) | (未接続) |
| U2-14 (B5) | (未接続) |
| U2-15 (B4) | (未接続) |
| U2-16 (B3) | PPU_A13_3V3 |
| U2-17 (B2) | PPU_/WR_3V3 |
| U2-18 (B1) | PPU_/RD_3V3 |
| U2-19 (/OE) | GND |
| U2-20 (VCC) | +3V3 |
| Q1-1 (E) | GND |
| Q1-2 (C) | /IRQ |
| Q1-3 (B) | Q1_B |
| D1-1 | VBUS_MOD |
| D1-2 | +5V |
| C1-1 | VBUS_MOD |
| C1-2 | GND |
| C2-1 | +3V3 |
| C2-2 | GND |
| C3-1 | EXP_AUDIO_RC |
| C3-2 | GND |
| C4-1 | SOUND_OUT |
| C4-2 | LOUT |
| R1-1 | PPU_/A13 |
| R1-2 | CIRAM_/CE |
| R2-1 | +5V |
| R2-2 | FC_5V_SENSE |
| R3-1 | FC_5V_SENSE |
| R3-2 | GND |
| R4-1 | IRQ_DRV |
| R4-2 | Q1_B |
| R5-1 | Q1_B |
| R5-2 | GND |
| R6-1 | +5V |
| R6-2 | /IRQ |
| R7-1 | SOUND_IN |
| R7-2 | SOUND_OUT |
| R8-1 | EXP_AUDIO_VR |
| R8-2 | SOUND_OUT |
| R9-1 | EXP_AUDIO_PWM |
| R9-2 | EXP_AUDIO_RC |
| R10-1 | LOUT |
| R10-2 | GND |
| R11-1 | LINE |
| R11-2 | LOUT |
| JP1-1 | CIRAM_A10_MCU |
| JP1-2 | CIRAM_A10 |
| JP2-1 | PPU_A10 |
| JP2-2 | CIRAM_A10 |
| JP3-1 | PPU_A11 |
| JP3-2 | CIRAM_A10 |
| SW1-1 | BOOTSEL |
| SW1-2 | GND |
| SW2-1 | RUN |
| SW2-2 | GND |
| J2-1 (SLEEVE) | GND |
| J2-2 (RING) | LINE |
| J2-3 (RING_SW) | (未接続) |
| J2-4 (TIP) | LINE |
| J2-5 (TIP_SW) | (未接続) |
| J3-1 | SWCLK |
| J3-2 | GND |
| J3-3 | SWD |
| TP1-1 (TP) | PPU_/RD |
| TP2-1 (TP) | PPU_D0 |
| TP3-1 (TP) | M2 |
| TP4-1 (TP) | /ROMSEL |
| TP5-1 (TP) | GND |

## ファイル

| ファイル | 内容 |
|---|---|
| kicad/gen_schematic.py | 回路図を生成(FC-MAGICON.kicad_sch) |
| kicad/gen_footprints.py | カセット端子のフットプリントを生成 |
| kicad/build_pcb.py | 部品配置(place)、配線の取り込みとベタ(import)、一部の配線やり直し(reroute) |
| kicad/route.py | Freerouting で自動配線 |
| kicad/add_part.py / sync_nets.py / hand_route.py | 配線済みの基板に部品を足す / パッドのネットを回路図に合わせる / 1本だけ手で引く |
| kicad/export_gerbers.ps1 | DRC を確認してガーバーと zip(FC-MAGICON_gerber_r0.2.zip)を出力 |
| images/board_front.png ほか | 基板の3D画像(正面・背面・斜め、kicad-cli pcb render) |
| kicad/bom.py / print_bom.ps1 | 部品表の作成と印刷 |
| kicad/print_fit_check.ps1 | 実寸の現物合わせシートを印刷 |
| kicad/gen_spec_tables.py / docs/build_spec.py | この仕様書を作る |

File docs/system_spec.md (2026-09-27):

# FC-MAGICON 仕様書(ハードウェア・ソフトウェア総合)

FC-MAGICON のハードウェア・ファームウェア・PC のソフトウェア・通信とデータの形式・試験の記録を 1 冊にまとめたもの。2026-09-27 時点。**基板 rev0.2 は発注済み・未着で、ファミコンの実機では未検証**。ファームウェアと PC のソフトは、PC の試験台(sim)と Core2350B2 単体(ピンヘッダーを付けたモジュール)で確かめた範囲まで。

[[TOC]]

## 1. 概要

ファミコン(HVC-001、本体基板 HVC-CPU-07)のカセットスロットに挿す自作カセット。Waveshare Core2350B2(RP2350B)1 個が、CPU のバスと PPU のバスの両方に直接応答する。FPGA は使わない。

| 機能 | 内容 |
|---|---|
| マジコン | フラッシュに書いた .nes を SRAM に写し、PRG(CPU 側)と CHR(PPU 側)を返す。マッパー 8 種類(4.6) |
| ゲーム選択メニュー | 何本もまとめて書き、起動時にファミコンの画面で選ぶ(4.10) |
| NSF プレイヤー | .nsf を本体の 2A03 で鳴らす。曲の切り替え・一時停止(4.7) |
| 画面転送(リモートデスクトップ) | PC の画面を 256 x 240 ドットでファミコンに映す。1コン = マウス、ファミリーベーシックのキーボード = PC のキーボード(4.8) |
| PC の音 | 画面転送中、PC で鳴っている音をファミコンの音声に混ぜて鳴らす(4.9) |
| Wi-Fi | ESP32-C6 を J6 につなぎ、画面転送を Wi-Fi で行う(5 章) |

### 1.1 全体の構成

| 所 | 部品・ソフト | 役目 |
|---|---|---|
| PC(Windows 11) | `remote_pc.py`・`pcaudio.py`・`nesframe.py`・`load_rom.ps1` など(6 章) | 画面の取り込みと変換、音の横取り、入力をマウス・キーへ、ROM の書き込み |
| 通り道 1 | USB(Core2350B2 の FPC-USB アダプター) | PC 直結。614KB/秒 |
| 通り道 2 | Wi-Fi → ESP32-C6(TCP ⇔ USB の素通し)→ J6 → RP2350(USB ホスト) | 無線。420KB/秒 |
| カセット | RP2350B(コア 0 = USB・画面転送・音、コア 1 = バスの応答)、PIO 3 つ | バスに応答、ROM・画面・音を出す |
| ファミコン | 2A03(CPU・音源)、2C02(PPU)、本体 RAM・VRAM | 6502 のプログラム(ゲーム、または FC-MAGICON が用意するドライバー)を動かす |

### 1.2 版と状態(2026-09-27)

| もの | 版 | 状態 |
|---|---|---|
| 基板 | rev0.2(`kicad/FC-MAGICON_gerber_r0.2.zip`) | JLCPCB に発注済み・未着。2 層、黒、1.2mm |
| マイコン | Waveshare Core2350B2(RP2350B A4、QFN-80) | 手元にあり。ピンヘッダーを付けて単体で試験中 |
| ファームウェア | pico-sdk 2.3.1 | ビルド済み。PC の試験台と単体で確認した範囲まで(12 章) |
| Wi-Fi ブリッジ | ESP32-C6 N4、Arduino-ESP32 3.3.12 | 動作確認済み(PC 相手・RP2350 相手) |
| ケース | printables 860420 のシェル(CC BY 4.0)を改造 | ユーザーが編集中。3D プリンターは Bambu Lab P1S |
| シール | `case/label/`(99 x 60.6mm) | L 判の光沢紙に印刷済み |

## 2. 動作モード

起動した時にフラッシュの ROM 置き場の中身で決まる。

| モード | 入り方 | カセットがすること | 本体の 6502 が動かすもの | USB(magicon) |
|---|---|---|---|---|
| ゲーム | `load_rom.ps1 game.nes`、またはメニューで選ぶ | PRG・CHR・WRAM を返し、マッパーを真似る | ゲーム | 1 秒ごとの様子を USB シリアルに |
| NSF プレイヤー | `load_rom.ps1 music.nsf`、またはメニューで選ぶ | 曲のデータとドライバーを返し、ベクターを横取り | NSF ドライバー($5000-)と曲 | 同上 |
| 画面転送 | `load_rom.ps1 -Remote`、またはメニューの REMOTE DESKTOP | PPU の読み出しに PC の絵を返す。音を鳴らす | 画面転送ドライバー($C000-) | 画面・音を受け、入力を返す |
| ゲーム選択メニュー | `load_rom.ps1 -Library フォルダー` | メニュー(NROM)をその場で組み立てて返す | メニュー($C000-) | 同上 |
| 試験画面 | ROM が無い・壊れている・対応していない時 | chr_test と同じ 4 色の縦縞 + 格子と音 | 試験 ROM | 理由を USB シリアルに |

別のファームウェア(`bus_test`・`chr_test`)は、基板が届いて最初に確かめる時だけ使う(4.1)。

## 3. ハードウェア

基板の詳しい所は `docs/hardware_spec_body.md` をそのまま取り込んでいる(3.1〜3.10)。3.11 は、モジュール単体の試験で使ったピン。

### 3.1 構成

| 経路 | 内容 |
|---|---|
| CPU バス(26本) | カセット端子 → Core2350B の GPIO0〜25 に直結(D0〜D7、A0〜A14、/ROMSEL、R/W、M2) |
| PPU バス | AD0〜AD7・A8〜A12 → GPIO26〜38 に直結。/RD・/WR・A13 → U2(74LVC245)→ GPIO40〜42 |
| ミラーリング | GPIO43 → JP1 → CIRAM A10(18番)。JP2/JP3 で PPU A10/A11 に固定もできる |
| /IRQ | GPIO45 → R4 → Q1 → /IRQ(15番) |
| 電源 | 本体 +5V(30・31番)→ D1 → Core2350B の VBUS → モジュール内 LDO → 3.3V → U2 |
| 本体 5V 検出 | +5V → R2/R3 分圧 → GPIO46 |
| 音声 | 45番 → R7(0Ω)→ 46番。GPIO44 の PWM → R9/C3 → VR1(音量)→ R8 → 46番。46番 → C4 → R10/R11 → J2(3.5mm ライン出力) |
| PC | Core2350B の USB(付属の FPC-USB アダプター)。同じ D+/D- を J6(予備ランド)にも出している |
| テスト | J4(カセット60ピン全部、端子の真上)、J5(内部信号)、J3(SWD)、TP1〜TP5 |

### 3.2 主要部品

| 記号 | 部品 | 役割 |
|---|---|---|
| U1(P1〜P4) | Waveshare Core2350B2 | RP2350B(QFN-80、GPIO 48本)、16MB フラッシュ、2MB PSRAM、LDO(ME6217C33)、12MHz 水晶。25.4mm 角、外周2列 64ピン |
| U2 | SN74LVC245AN(DIP-20) | PPU の /RD・/WR・A13 を 5V → 3.3V。5V 非トレラントの GPIO40〜42 へ渡す |
| Q1 | 2SC1815(TO-92) | /IRQ をオープンコレクタで引き下げる |
| D1 | 1N4001〜1N4007(ショットキー 1A 推奨) | 本体 5V → モジュールの VBUS。USB 給電時の本体への逆流を防ぐ |
| J1 | 基板エッジ(金メッキ端子 60本) | ファミコンのカセットスロット |
| J2 | PJ-324M | 3.5mm ライン出力(モノラルを L/R 両方へ) |
| VR1 | KOA KVSF637AC104(100kΩ、上面調整) | 拡張音源の音量。足は ①③ が 5.0mm 間隔、② がその中央の 5.0mm 上(データシートの推奨取付穴、φ1.2) |

### 3.3 電源

| 項目 | 値 |
|---|---|
| 供給元 | 本体の +5V(カセット端子 30・31番)。GND は 1・16番 |
| モジュールへの経路 | +5V → D1 → VBUS_MOD(モジュール P2-15 VBUS)→ モジュール内 LDO → +3V3 |
| VBUS_MOD の電圧 | 1N400x で約 4.3V、ショットキーなら約 4.6V(LDO の入力として十分) |
| +3V3 の使い道 | モジュールの 3V3 出力(P2-16)を U2 の電源と DIR に使う。C2 100nF をパスコンに |
| 平滑 | C1 10µF(VBUS_MOD) |
| USB 給電 | Core2350B の USB からも VBUS に入る。D1 があるので本体側の +5V へは流れない |
| 消費電流(見込み) | モジュール数十 mA 〜 100mA 程度(RP2350B のクロック次第)。本体の 7805 の範囲内 |

**逆流に注意**:USB だけで給電している時(本体の電源が切れている時)に RP2350B がバスへ出力すると、
電源の入っていない本体の IC に 3.3V が流れ込む。これを避けるため、本体の 5V を分圧して GPIO46 で監視する(3.6)。

### 3.4 バスの接続と電圧

**CPU バス(26本、すべて RP2350B に直結)**

| 信号 | GPIO | 向き |
|---|---|---|
| CPU D0〜D7 | 0〜7 | 双方向(読み出し時だけ RP2350B が出力) |
| CPU A0〜A14 | 8〜22(A0 から連続) | 入力 |
| /ROMSEL | 23 | 入力(= !(A15 & M2)) |
| R/W | 24 | 入力 |
| M2 | 25 | 入力 |

**PPU バス**

| 信号 | GPIO | 向き・経路 |
|---|---|---|
| PPU AD0〜AD7(カセット端子の PPU D0〜D7) | 26〜33 | 双方向。/RD が下がる直前はアドレス下位 8 ビット、その後データ |
| PPU A8〜A12 | 34〜38 | 入力。GPIO26〜38 で 13 ビットのアドレスが連続する |
| PPU /RD | 40 | U2 経由の入力 |
| PPU /WR | 41 | U2 経由の入力 |
| PPU A13 | 42 | U2 経由の入力(カセット端子 56番、非反転) |
| PPU /A13 | — | CIRAM /CE(48番)へ R1(0Ω)で直結。RP2350B にはつながない |
| PPU A0〜A7(ラッチ後) | — | RP2350B では使わない。J4 には出してある |

**電圧の扱い**

| GPIO | 5V を受けられるか | この基板での使い方 |
|---|---|---|
| 0〜38 | 可(IOVDD に電源が入っている時) | 5V のバス信号を直接受ける |
| 39 | 可 | モジュール上の LED(470Ω)が付いているので使わない |
| 40〜47(ADC 兼用) | **不可** | 40〜42 は U2(3.3V 電源の 74LVC245)の後。43〜46 は出力専用か分圧後の入力。47 はモジュール上の PSRAM の CS |

- RP2350B の出力は 3.3V。2A03・PPU(NMOS)の入力は H を 2.0〜2.4V 程度から認識するので受けられる。
- U2:DIR = +3V3(A→B)、/OE = GND(常に有効)。A 側(5V)に /RD・/WR・A13、B 側(3.3V)から GPIO40〜42。空き入力 A4〜A8 は GND。74LVC は電源が無い時も入力に 5V を受けられる。
- PIO は1ブロックで連続 32本しか扱えないので、CPU 用は GPIO0〜31、PPU 用は GPIO16〜47 の窓を使う。

### 3.5 PPU アドレスの読み取り方

ファミコンの PPU は、アドレス下位 8 ビットとデータを同じ 8本(AD0〜AD7)で時分割する。
本体側の 74LS373 がアドレスをラッチし、カセットには PPU A0〜A7 として出てくるが、この基板ではそれを使わない。

- PIO で「/RD が High の間、AD0〜AD7 を読み続ける」ループを回し、/RD が下がった時点で最後に読んだ値を下位アドレスとする。
- 上位は A8〜A12(と A13)を直接読む。
- PPU の読み出しは約 372ns ごと(PPU クロック 5.37MHz の 2 クロック)。/RD が下がってからデータを出すまでの余裕が足りるかは**未検証**(TP1・TP2 で測る)。
- 足りない場合でも、画面転送(FC-PICO 方式)・自作ゲーム・NSF には影響しない。市販の CHR-ROM ゲームの動作に影響する。

### 3.6 制御・周辺回路

**本体 5V の検出**

+5V → R2 15kΩ → FC_5V_SENSE(GPIO46)→ R3 22kΩ → GND。5V のとき 2.97V、4.75V のとき 2.82V。
ファームは GPIO46 が High になるまで、全てのバスのピンを入力にしておく。

**/IRQ**

GPIO45(IRQ_DRV)→ R4 4.7kΩ → Q1 ベース(R5 100kΩ で GND に引き下げ)。Q1 コレクタ → /IRQ(15番)、エミッタ → GND。
GPIO45 = High で /IRQ が Low(割り込み要求)。ベース電流は約 0.55mA。起動中は R5 で Q1 がオフ。
R6(10kΩ、+5V へのプルアップ)は未実装。本体側にプルアップがあることを確認済み。

**ミラーリング(CIRAM A10、18番)**

JP1〜JP3 のどれか1つだけをはんだで閉じる。

| ジャンパー | 18番につながるもの | 用途 |
|---|---|---|
| JP1 | GPIO43(CIRAM_A10_MCU) | ファームで切り替える(MMC1/MMC3 などのマッパー) |
| JP2 | PPU A10(53番) | 垂直ミラー固定 |
| JP3 | PPU A11(54番) | 水平ミラー固定 |

GPIO43 は 3.3V 出力。本体の VRAM が 3.3V を H と認識するかは実機で確認する。駄目なら JP2/JP3 を使う。

**音声**

| 部分 | 回路 | 値 |
|---|---|---|
| 素通し | 45番(本体からの音声)→ R7 0Ω → 46番(本体へ戻す) | 市販カセットと同じ |
| 拡張音源 | GPIO44 PWM → R9 1kΩ → EXP_AUDIO_RC(C3 10nF で GND)→ VR1 100kΩ(①=RC、③=GND、②=中点)→ R8 47kΩ → 46番 | RC の遮断周波数 約 15.9kHz。VR1 で音量 0〜最大。どこに回しても本体の音声ラインには 47kΩ 以上が付く |
| ライン出力 | 46番 → C4 10µF(+ 側が 46番)→ LOUT(R10 47kΩ で GND)→ R11 100Ω → J2 | 低域の遮断 約 0.34Hz。J2 は L/R に同じ信号 |

**操作**

| 部品 | 動作 |
|---|---|
| SW1 BOOTSEL | 押しながらリセットすると RP2350B が USB 書き込みモードになる |
| SW2 RESET | RP2350B の RUN を GND に落とす。**本体のリセットではない**(本体はリセットボタンで) |

### 3.7 デバッグ・テスト用

| 記号 | 内容 |
|---|---|
| J3 | SWD(1=SWCLK、2=GND、3=SWDIO)。debugprobe の Pico をつなぐ |
| J4 | カセット60ピン全部(2x30、2.54mm)。差し込み部のすぐ上で、各列が真下の端子と同じ信号。本体に入る高さなのでランドとして使う想定 |
| J5 | 内部信号(2x8、2.54mm)。上辺。12〜14番は GND(元の LOUT・Q1_B・LINE は2層に収めるために外した。J2・R10・R11・Q1 の足で測れる) |
| J6 | USB の予備ランド(1x4、2.54mm、1=5V(VBUS)、2=D-、3=D+、4=GND)。モジュールの FPC と同じ USB 信号。**FPC 側と同時に機器をつながない**。VBUS は本体給電時 D1 の後の約 4.3V |
| TP1〜TP5 | /RD、PPU D0、M2、/ROMSEL、GND。オシロのプローブ用(穴 0.7mm) |

### 3.8 機械仕様

| 項目 | 値 |
|---|---|
| 外形 | 90.0 × 65.8mm(本体 90.0 × 55.1mm + 差し込み部 78.4 × 10.7mm)。規格の基板(56.8mm)より 9mm 高い |
| 厚み | 1.2mm |
| 端子 | 60本、2.54mm ピッチ。部品面(表)= 1〜30番、裏 = 31〜60番。部品面から見て左端が 1/31番 |
| 端子の寸法 | 信号 1.6 × 5.7mm。1・30・31番は 2.6mm 幅、1・16・30・31番は差し込み側へ 1mm 長い(先に接触) |
| 向き | 部品面を本体の**手前**に向けて挿す(市販カセットのラベル面と同じ側に 1〜30番) |
| レジスト | 端子部は抜いてある(端子の上端の 0.6mm 上から先端まで) |
| 部品 | 部品面。ただし R1 だけ裏面(Q1 を下へ倒して寝かせるため、2026-09-26 に移した)。スルーホール部品のみ(表面実装はソルダージャンパーと端子だけ) |
| シルク | 表面: ロゴ(幅 19.5mm)と「rev0.2」。裏面: ロゴ(34mm)・「MADE BY SHIMA-R7」・スペック表(モジュールのソケットの内側) |
| モジュールの高さ | ピンソケットで載せるので、基板から約 13mm |
| コンデンサー | C1〜C4 は足を曲げて右へ寝かせる前提。倒した本体の範囲は部品禁止(シルクに枠と「lay →」) |
| J2 | 3.5mm ジャックの差し込み口が左辺から約 3.6mm 外へ出る |
| ケース | printables 860420 のシェル(CC BY 4.0)を改造して、Bambu Lab P1S で 3D プリントする(2026-09-27 時点でユーザーが編集中) |

### 3.9 基板の製造仕様

| 項目 | 値 |
|---|---|
| 層数 | 2(F.Cu / B.Cu)。GND ベタを両面に、GND スティッチングビアあり |
| 配線幅 | 信号 0.25mm(IC の足の間で最小 0.15mm)。+5V 0.8mm(端子31番から J4 への枝だけ 0.5mm)、VBUS_MOD 0.6mm、GND 0.5mm、+3V3 0.4mm、音声 0.4mm |
| クリアランス | 0.2mm |
| ビア | 径 0.6mm / 穴 0.3mm |
| 端子部 | 端子の隙間・両脇・先端は配線・ビア・ベタ禁止。配線はパッドの上端から入る |
| DRC | エラー 0、未接続 0(2026-09-26)。フットプリントをライブラリから書き換えた旨の通知 9件のみ |
| 発注 | JLCPCB(2026-09-27 の時点で発注済み・未着)。厚み 1.2mm、黒、HASL(有鉛)、Gold Fingers、差し込み側 45° 面取り、5枚 |

### 3.10 ファームウェアが守ること

1. **起動時は全バスピンを入力**にし、GPIO46(本体 5V 検出)が High になってから出力を許す。
2. CPU D0〜D7 を出力するのは、読み出しサイクル(/ROMSEL = Low かつ R/W = High、または $6000〜$7FFF の WRAM 読み出し)の間だけ。
3. PPU AD0〜AD7 を出力するのは、/RD = Low かつ A13 = Low(パターンテーブル)の間だけ。A13 = High(ネームテーブル)の時は本体の VRAM が出力する。
4. RP2350 のエラッタ E9:バスのピンで内部プルダウンを使わない。
5. GPIO39(LED)・GPIO47(PSRAM CS)をバスに使わない。
6. /IRQ は GPIO45 = High で要求、Low で解除。
7. 電源投入直後は本体の CPU が RP2350B の起動を待たずに動く。間に合わなければ本体のリセットボタンを押す。

### 3.11 モジュール単体の試験で使ったピン(2026-09-27)

基板が届く前に、Core2350B2 にピンヘッダーを付けて試した時のつなぎ方。ピンの番号は `kicad/gen_schematic.py` の並び(P1〜P4 は 1 番が GND)。

| モジュールのピン | 信号 | つないだ先 | 目的 |
|---|---|---|---|
| P2-7 / P2-9 | USB D- / D+ | ESP32-C6 の GPIO12 / GPIO13 | RP2350 を USB ホストにして C6 と直結 |
| P2-15 / P2-14 | VBUS / GND | C6 ボードの 5V / GND | 2 枚とも C6 の UART の USB-C から給電 |
| P2-8 | GND | C6 の GND | データ線の横の GND |
| P2-10 / P2-6 | SWCLK / SWDIO | debugprobe(Pico)の GP2 / GP3 | SWD で書き込み・停止・メモリーの読み出し |
| P1-2 | GPIO0(UART0 TX) | debugprobe の GP5 | host_test のログ(**届かず、未解決**) |
| P2-4 → P2-16 | GPIO46(本体 5V 検出)→ 3V3 | 線でつなぐ | ファミコンが無くても「5V あり」にして画面転送のループを動かす |
| P4-15 | GPIO44(音の PWM) | 1kΩ → 10µF → イヤホン(根元は P4-1 GND) | PC の音を耳で確かめる |

## 4. ファームウェア(RP2350)

### 4.1 ファームウェアの一覧

`pwsh -File firmware/build.ps1` で全部作る(`firmware/out/`)。大きさは今のビルド。

| ファイル | 大きさ | 用途 | 中身 |
|---|---:|---|---|
| `bus_test.uf2` | 93KB | 最初の動作確認 1 | CPU バスの読み書き。テスト ROM が 440Hz を鳴らし、$8000 への書き込みを数えて LED を点滅 |
| `chr_test.uf2` | 94KB | 最初の動作確認 2 | PPU の読み出しに CHR を返す。4 色の縦縞と 8 ドットの格子が出れば下位アドレスの読み取りが正しい |
| `host_test.uf2` | 72KB | 試験 | USB ホストで ESP32-C6 から受ける速さを測る(ファミコン無し)。UART0(GPIO0)にログ |
| `magicon.uf2` | 201KB | ふだん使う | ゲーム・NSF・画面転送・メニュー。USB はデバイス(PC 直結、USB シリアル、picotool の自動書き込み) |
| `magicon_wifi.uf2` | 211KB | Wi-Fi の画面転送 | magicon と同じ。USB をホストにして J6 の ESP32-C6 とやりとりする。USB シリアル無し |
| `usb_test.uf2` | 44KB | 試験 | USB 直結の速さを測る(ファミコン無し)。受けた画面を捨て、FCIN を 60 回/秒返す |

### 4.2 作りの全体

| 項目 | 内容 |
|---|---|
| クロック | 250MHz(コア電圧 1.20V に上げてから) |
| コア 1 | バスの応答だけ。割り込み無しの 1 本のループを SRAM で動かす(`__not_in_flash_func`)。モードごとに `bus_loop` / `nsf_bus_loop` / `remote_bus_loop` |
| コア 0 | 起動、ROM の読み込み、USB(シリアル・画面転送・音)、本体の電源の見張り、メニューで選ばれた番号の見張り |
| PIO0 SM0 | `cpu_m2.pio`(GPIO 0〜31 の窓)。CPU の全サイクル |
| PIO1 SM0 | `ppu_chr.pio`(GPIO 16〜47 の窓)。PPU の /RD |
| PIO2 SM0 | `mirror.pio`(GPIO43)。PPU A10 / A11 を CIRAM A10 へ写す |
| DMA | 音(PWM へ 32kHz で流す)に 1 チャンネルと DMA タイマー 1 つ |
| SRAM の主な使い道 | ROM 384KB(PRG の後ろに CHR)、CHR-RAM 8KB、WRAM 8KB、NSF ドライバー 4KB、音のリング 16KB |
| 読み出しの作り | 8KB(PRG)/ 1KB(CHR)ごとのポインターの表を引くだけ。マッパーの計算は書き込みの時だけする |

### 4.3 起動の流れ

1. バスのピン(GPIO 0〜46、LED の 39 を除く)を全部入力・プル無しにする(RP2350 のエラッタ E9 のため、バスにプルダウンを使わない)。
2. コア電圧を 1.20V にして 250MHz にする。USB を始める(magicon はデバイス + USB シリアル、magicon_wifi はホスト)。
3. フラッシュの ROM 置き場を読む(`FCMG` = 1 本、`FCLB` = ライブラリ)。ライブラリなら、ウォッチドッグのメモ(scratch[0])にメニューで選んだ番号が残っていればその ROM、無ければメニューを組み立てる。1 本だけのライブラリはそのまま読む。
4. ROM を SRAM に写す(本体がリセットを解く前にバスへ出られるよう、5V を待つ前に済ませる)。駄目なら試験画面にする。
5. 本体の 5V(GPIO46)が来るまで待つ(LED を点滅、USB シリアルに `waiting for Famicom 5V`)。
6. PIO を設定し、コア 1 でバスの応答を始める(`cart_start`)。
7. コア 0 はモードごとのループへ。画面転送なら音を始めてから画面転送のループ。

### 4.4 CPU バスの応答

| 項目 | 内容 |
|---|---|
| 起こし方 | M2 で起きて全サイクルを拾う(`cpu_m2.pio`)。M2 が上がって 80ns 後にアドレス・R/W・/ROMSEL を読む |
| 読み出し | $8000-$FFFF(/ROMSEL = Low)は PRG、$6000-$7FFF は WRAM(マッパー 87 / 184 以外)。それ以外は出さない |
| 書き込み | PIO は M2 が下がる所でデータをもう一度読んで 2 回目を送る。コア 1 がマッパー・WRAM・PPU レジスターの横読みへ振り分ける |
| 出す時 | D0〜D7 を出すのは読み出しサイクルの間だけ(3.10 の決まり) |
| 数えるもの | CPU サイクル(約 179 万/秒)・PPU 読み出し・書き込みの回数(USB シリアルに 1 秒ごと) |

### 4.5 PPU バスの応答

| 項目 | 内容 |
|---|---|
| アドレス | /RD が High の間 AD0〜AD7 を読み続け、/RD が下がった時に最後に読んだ値を下位 8 ビットとする。上位は A8〜A12 |
| 出す時 | /RD = Low かつ A13 = Low(パターンテーブル)の時だけ。ネームテーブルは本体の VRAM が出す |
| CHR-RAM | PPU の書き込みではアドレスが読めないので、CPU の $2006 / $2007 への書き込みを横から読んで同じ所へ書く。$2000 の +1 / +32、$2002 の読み出し・$2005 で切り替わる「2 回目か」も真似る |
| MMC3 の IRQ | PPU A12 の立ち上がりを数え(A12 が Low の読み出しが 8 回続いた後)、GPIO45 → Q1 で /IRQ を出す |
| ミラーリング | PIO2 が PPU A10 / A11 を CIRAM A10(GPIO43)へ写す。水平・垂直・1 画面。JP1 を閉じた時だけ効く |
| **未検証** | /RD が下がってからデータを出すまでに間に合うか(chr_test と TP1・TP2 で測る)。駄目でも画面転送・NSF・CHR-RAM のゲームには響かない |

### 4.6 マッパー

PRG + CHR の合計 384KB まで(SMB3 の 256K + 128K が入る)。`tools/nes_pack.py` の表から作った。

| 番号 | マッパー | 特徴 |
|---|---|---|
| 0 | NROM | バンク切り替え無し |
| 1 | MMC1 | CHR-RAM も可。ミラーリング切り替え(JP1) |
| 2 | UxROM | CHR-RAM |
| 3 | CNROM | CHR 8KB 切り替え |
| 4 | MMC3 | スキャンライン割り込み(/IRQ)。ミラーリング切り替え(JP1) |
| 7 | AxROM | 1 画面ミラー(JP1) |
| 87 | Jaleco J87 | $6000-$7FFF の書き込みで CHR 切り替え |
| 184 | Sunsoft-1 | $6000-$7FFF の書き込みで CHR 4KB × 2 |

- WRAM($6000-$7FFF)8KB は電源を切ると消える(バッテリーのセーブはまだ)。
- 対応していない ROM は `nes_pack.py` がその場で止める(ライブラリなら飛ばす)。

### 4.7 NSF プレイヤー

| 項目 | 内容 |
|---|---|
| 置き場 | 曲のデータ = $8000-$FFFF(4KB × 8、$5FF8-$5FFF でバンク切り替え、384KB まで)。ドライバー = $5000-$5FFF(SRAM、本体側に何も無い所) |
| ベクター | $FFFA-$FFFF の読み出しだけ、ドライバーの番地を返す |
| 曲を始める時 | APU を黙らせ、本体 RAM と $6000-$7FFF を 0 にし、バンクを初期値に戻して INIT を呼ぶ(NSF の決まり) |
| 再生 | VBlank の NMI(約 60.1Hz)ごとに PLAY。再生間隔が標準と違う NSF はテンポが変わる |
| 操作 | ←→ = 前 / 次の曲、A = 最初から、START = 一時停止 |
| 画面 | ロゴ・曲名・作者・著作・曲番号。フォントは Consolas Bold 9pt から作った(`gen_nsf_driver.py`) |
| 変数 | $5F80-(NSF がゼロページを自由に使うため) |
| 未対応 | 拡張音源(VRC6・FDS・N163 など)、load が $8000 より下のバンク無し NSF、FDS 用の $6000-$DFFF を RAM にする NSF |

ドライバーの番地(`nsf_driver.h` から):

| 名前 | 値 | 意味 |
|---|---|---|
| `NSFD_BASE` | 0x5000 | ドライバーの先頭($5000-$5FFF はカセットの SRAM) |
| `NSFD_NT` | 0x0800 | 画面の土台(ドライバーの先頭から) |
| `NSFD_PARAM` | 0x0F00 | ファームが書く値: 曲数・最初の曲・バンクの初期値(先頭から) |
| `NSFD_RESET` | 0x5000 | リセットベクターが指す番地 |
| `NSFD_NMI` | 0x519A | NMI(PLAY を呼び、パッドを読む) |
| `NSFD_IRQ` | 0x5288 | IRQ(何もしない) |
| `NSFD_INIT_OPERAND` | 0x028A | INIT への JMP の番地の置き場(ファームが書く) |
| `NSFD_PLAY_OPERAND` | 0x028D | PLAY への JMP の番地の置き場 |

### 4.8 画面転送(リモートデスクトップ)モード

| 項目 | 内容 |
|---|---|
| 絵 | 256 x 240 ドット、2 ビット(4 色)。16 x 16 ドットごとに 4 組のパレットから選ぶ(背景の 1 色は共通) |
| しくみ | ネームテーブルに「(行 % 8) * 32 + 列」のタイルを並べておき、PPU が読みに来たタイル番号と行の中の y から画面の位置を割り出して、その 8 ドットを返す。8 行ごとの組は、タイル行が 7 → 0 になる回数で数える |
| 2 枚持ち | 絵と付随(パレット 32・属性 64・OAM 256)を表と裏で 2 組。1 枚届いたら、画面の最後(行 29 → 0)で入れ替える。表示待ちがある間は次を読まない(PC 側がそこで待つ) |
| 置き場 | 絵は ROM の SRAM(`rom[]`)の先頭を使う |
| カーソル | スプライト 4 タイル(16 x 16、パターンテーブル $1000)。PC が位置と表示の有無を送る |
| 6502 の仕事 | VBlank ごとに OAM DMA、パレット 32 と属性 64 を PPU へ、v を $2000 に戻す。1コンとキーボード(9 行 x 2 列、1 列ごとに 500µs 待つ)を読んで $5F00- に書く |
| レジスター | $2000 = $88(NMI 有効、背景 $0000、スプライト $1000)、$2001 = $1E |

6502 側の番地(`remote_driver.h` から):

| 名前 | 値 | 意味 |
|---|---|---|
| `RD_PAL` | 0x5D00 | パレット 32 バイト(VBlank ごとに 6502 が PPU へ写す) |
| `RD_ATTR` | 0x5D20 | 属性テーブル 64 バイト |
| `RD_OAM` | 0x5E00 | スプライト(カーソル)256 バイト。OAM DMA の元 |
| `RD_IO` | 0x5F00 | 6502 が書く入力: +0 パッド、+1〜+9 キーボード、+15 フレームの数 |

### 4.9 PC の音

| 項目 | 内容 |
|---|---|
| 出口 | GPIO44 の PWM → R9 1kΩ・C3(RC 約 15.9kHz)→ VR1 → R8 47kΩ → カセット端子 46 番(本体の音声に混ぜる)。J2(3.5mm)にも出る |
| PWM | 10 ビット(0〜1023、無音 = 512)、250MHz / 1024 = 約 244kHz |
| 流し方 | 8192 サンプル(256ms)のリング(16KB 境界)を、DMA が「終わり無し」+ 読み出しリングで比較値へ流し続ける。間隔は DMA タイマー(250MHz × 4 / 31250 = 32kHz) |
| 溜め方 | 届いた音は、鳴らしている所の 100ms 先に置く。150ms 以上溜まったら捨てる。鳴らし終えた所は無音で埋める(途切れても古い音を繰り返さない) |
| 形式 | 32kHz モノラル。16 ビット PCM / 8 ビット PCM / IMA ADPCM(4 ビット、パケットごとに最初の値と段を載せる)(7.4) |
| 使う時 | 画面転送モードの時だけ |

### 4.10 ゲーム選択メニュー

| 項目 | 内容 |
|---|---|
| 形 | NROM(PRG 32KB + CHR 8KB)。ファームが起動時にその場で組み立てる(`cart_load_menu`)。プログラムは `gen_menu_driver.py`、フォントとロゴは NSF プレイヤーの CHR |
| 画面 | ロゴ、「SELECT A GAME」、20 行の一覧(題名 28 文字)、操作の説明 |
| 操作 | ↑↓ = 選ぶ(24 フレーム押し続けると 4 フレームごとに動く)、←→ = 20 項目ずつ、A / START = 始める。1コンと拡張端子のコントローラーの両方を読む |
| 始め方 | 1) 本体 RAM $0300 に写した 57 バイトのプログラムへ移る 2) NMI・表示・音を止め、選んだ番号を $5FF0 に書く 3) VBlank を 90 回(1.5 秒)待つ 4) 本体 RAM を 0 にして JMP ($FFFC) |
| カセット側 | $5FF0 への書き込みをコア 1 が見て、コア 0 が「0xFC01 + 番号」を scratch[0] に書いてウォッチドッグで再起動。次の起動でその ROM を読む(4.3) |
| 戻り方 | 本体の電源を入れ直すと、メニューから(4.11)。本体のリセットボタンは今のゲームの最初に戻るだけ |

メニューの番地(`menu_driver.h` から):

| 名前 | 値 | 意味 |
|---|---|---|
| `MENUD_COUNT` | 0x0000 | 項目の数(PRG の先頭から) |
| `MENUD_PTR_LO` | 0x0100 | 題名の番地の下位の表 |
| `MENUD_PTR_HI` | 0x0180 | 同じく上位 |
| `MENUD_TITLES` | 0x0200 | 題名(28 文字ずつ) |
| `MENUD_NT` | 0x1800 | 画面の土台 1024 バイト |
| `MENUD_CODE` | 0x4000 | メニューのプログラム($C000) |
| `MENUD_SELECT` | 0x5FF0 | 選んだ番号を 6502 が書く番地(ファームが見て再起動) |
| `MENUD_MAX_ITEMS` | 0x007F | 項目の上限 |

### 4.11 本体の電源の見張り

- ゲーム・NSF・メニュー・画面転送のどのループでも、コア 0 が GPIO46(本体 5V)を見ている。
- 50ms 続けて Low なら scratch[0] を 0 にしてウォッチドッグで再起動する。USB から電源をもらっている時も、本体の電源を入れ直せばメニューに戻る。
- 再起動した後は 4.3 のとおり、5V が来るまでバスに出さない。

### 4.12 USB

| 項目 | magicon(デバイス) | magicon_wifi(ホスト) |
|---|---|---|
| TinyUSB | pico-sdk 付属 0.18 | 0.21.0(`C:\Users\Yugo\pico\tinyusb-0.21.0`) |
| 相手 | PC(USB シリアル = CDC) | J6 の ESP32-C6(USB Serial/JTAG = CDC ACM) |
| USB シリアル(printf) | あり | 無し |
| picotool の自動書き込み | あり(`load_rom.ps1` がそのまま使える) | 無し(BOOTSEL + RESET) |
| 画面転送の読み書き | `stdio_get_until` / `stdio_put_string` | `tuh_cdc_read` / `tuh_cdc_write`(入り切らない入力は捨てて次のフレームで送る) |

magicon_wifi の注意:

- pico-sdk の USB シリアル(`stdio_usb`)は、アプリが TinyUSB のホストを使うと丸ごと無効になる。そのため 1 つのファームウェアにまとめていない。
- TinyUSB 0.18 の RP2350 ホストは、バルク転送が「割り込み用の窓口」で 1ms に 64 バイト = 64KB/秒止まりで、返事に受け取ったデータが混ざって化けた。0.21 は EPX を順番に回す。
- 0.21 と pico-sdk 2.3.1 の組み合わせでは CDC の受信 FIFO の mutex が初期化されず止まったので、`CFG_TUSB_OS = OPT_OS_NONE`(と `tusb_time_millis_api`)にした。
- C6 を開く時は DTR だけ立てる(C6 の USB Serial/JTAG は RTS でリセットがかかる)。受信バッファ 4096 バイト。

### 4.13 LED と表示

| 場面 | LED(GPIO39) | USB シリアル(magicon) |
|---|---|---|
| 5V を待つ間 | 100ms ごとに反転 | `waiting for Famicom 5V (GPIO46)... ROM: ok` など |
| 動いている間 | 点灯 | 1 秒ごとにモード・マッパー・大きさと、CPU サイクル・PPU 読み出し・書き込みの回数 |
| 画面転送 | 1 枚受け取るごとに反転 | — |

LED は SIO のレジスターを直接書く(host_test で `gpio_xor_mask64` が NOCP の HardFault を起こしたため。magicon では起きていないが同じ書き方にそろえた。**原因は未解明**)。

## 5. Wi-Fi ブリッジ(ESP32-C6)

| 項目 | 内容 |
|---|---|
| ボード | ESP32-C6 N4(フラッシュ 4MB)。USB-C が 2 つ: チップの USB(GPIO12 = D-、GPIO13 = D+)と UART(CH343 経由) |
| ファームウェア | `firmware/wifi_bridge/wifi_bridge.ino`(Arduino-ESP32 3.3.12)。`build_bridge.ps1` でビルドと書き込み |
| 動き | TCP 5000 番と USB(Serial/JTAG)の間でバイトを素通しする。中身は見ない。USB へ書けない間は TCP から読まない(PC 側が待つ) |
| つながる前 | USB に 2 秒ごとに `fc-magicon wifi_bridge ip=...` を出す(カセットは `FCFR` を探して読むので邪魔にならない)。USB から来た物は捨てる |
| 名前 | mDNS で `fc-magicon.local`(サービス `_fcbridge._tcp`)。`remote_pc.py --tcp` は既定でこの名前につなぐ |
| Wi-Fi | 2.4GHz。SSID とパスワードは `wifi_secrets.h`(`wifi_secrets.example.h` を写して書く。GitHub には上げない)。省電力は切る |
| 様子 | UART0(UART の USB-C)に 1 秒ごと: Wi-Fi の状態・IP・TCP の有無・USB の有無・行き来したバイト数 |
| フラッシュの癖 | QIO / 80MHz だと読み出しが化けて起動しない。ブートローダーは DIO / 40MHz(FQBN の `FlashMode=dio,FlashFreq=40`)、アプリはコンストラクターで SPI1 を 40MHz に落とす |
| 電源の癖 | 弱めで、一度ブラウンアウトでリセットを繰り返した(USB の挿し直しで直った) |
| カセットとのつなぎ方 | J6 の 2 番(D-)→ GPIO12、3 番(D+)→ GPIO13、4 番 → GND。C6 の電源は別に取る(J6 の VBUS から取ると Wi-Fi の電流が本体の 5V に乗る)。J6 と FPC の USB に同時に機器をつながない |

## 6. PC のソフトウェア

使うのは Python 3(Pillow・numpy)と Windows の API(ctypes)。pip で足すものは無い(`test_nsf_driver.py` の py65 と、書類の pypdf だけ別)。

### 6.1 道具の一覧

| 道具 | 役目 |
|---|---|
| `firmware/tools/remote_pc.py` | 画面転送の PC 側。画面を取り込んで送り、入力をマウス・キーへ、音も送る(6.2) |
| `firmware/tools/nesframe.py` | PC の画像を画面転送の 1 枚にする(6.3) |
| `firmware/tools/pcaudio.py` | PC の音の横取りと、送る形式への変換(6.4) |
| `firmware/load_rom.ps1` | ROM・NSF・画面転送モード・ライブラリをフラッシュに書く(picotool) |
| `firmware/tools/nes_pack.py` | ROM を調べて書く形にする。ライブラリを作る |
| `firmware/tools/asm6502.py` | 6502 の小さなアセンブラ(Python の関数で書く)。試験 ROM・ドライバー・メニューに使う |
| `firmware/tools/usb_bench.py` / `wifi_bench.py` / `host_bench.py` / `audio_bench.py` | 速さ・音の試験(8 章) |
| `firmware/tools/test_keyboard_bridge.py` | キーボードの割り当て・トグル・チャタリング対策の試験 |
| `firmware/sim/` | PC の試験台(8 章) |
| `firmware/build.ps1`、`wifi_bridge/build_bridge.ps1` | ファームウェアのビルド |
| `docs/build_*.py` | 仕様書・手順書を作る |
| `kicad/*.py` | 回路図・基板・ガーバー・部品表・印刷物を作る |
| `3d/export_step.py`、`case/label/make_label.py` | STEP の書き出し、シールの画像と印刷 |

### 6.2 remote_pc.py

| 項目 | 内容 |
|---|---|
| 取り込み | GDI の StretchBlt で 256 x 240 に縮めて取り込む。表示は「画面全体を縮小」(縦横比を保ち上下は黒)と「カーソルのまわりを等倍」 |
| 変換 | `nesframe.encode`(灰色 4 階調 / カラー)。カラーは前の画面の組から探す(チラつき防止) |
| 送信 | 送受信は別スレッド(`IoThread`)。画面を作る間に前の 1 枚を送る(順番にやると 15 枚/秒しか出なかった)。音のパケットは画面より先に送る |
| つなぎ先 | USB シリアル(COM、Win32 の CreateFile)か TCP(`--tcp`) |
| マウス | 十字キーで動かす(押し続けると 1 + 0.25 ずつ速く、12 まで。等倍表示では PC の 1 ドット単位)。A = 左クリック、B = 右クリック |
| 表示の切り替え | SELECT = 縮小 ⇔ 等倍、START = 等倍の時にカーソルを追うか止めるか |
| キーボード | SendInput でスキャンコード(JIS 配列)を送る。6.6 |
| 安全 | 入力が 0.5 秒届かない時と止めた時は、押しっぱなしのキーとボタンを離す |

オプション(`remote_pc.py` の `build_parser()` から):

| オプション | 内容 |
|---|---|
| `--port COMx` | COM ポートを指定する(既定: USB シリアルを探す) |
| `--color` | カラー(既定は灰色 4 階調。文字が読みやすい) |
| `--tcp HOST` | Wi-Fi ブリッジ(ESP32-C6)経由でつなぐ。HOST を省くと fc-magicon.local |
| `--fps` | 送る速さの上限(既定: USB 30、Wi-Fi 25。Wi-Fi は 25 までなら遅れ 40ms 前後) |
| `--dry-run N` | カセット無しで N 枚取り込んで変換し、速さを表示する |
| `--no-audio` | PC の音を送らない |
| `--audio {pcm16 / pcm8 / adpcm}` | 音の形式(既定: USB 直結 pcm16 = 64KB/秒、Wi-Fi pcm8 = 32KB/秒。adpcm = 16KB/秒は雑音が多い) |
| `--volume` | 送る音の大きさ(1.0 = そのまま) |

### 6.3 画面の変換(nesframe.py)

| 項目 | 内容 |
|---|---|
| 灰色 | 全体で黒・濃い灰・薄い灰・白の 4 階調。文字がいちばん読みやすい |
| カラー | 背景の 1 色(いちばん多い色、上下の黒い帯は数えない)+ 3 色 x 4 組のパレット。16 x 16 ドットごとに 4 組のどれかを選ぶ |
| 組の決め方 | 組の区画でよく使われる色を候補に、3 つの枠を 1 つずつ入れ替えて誤差が減る時だけ採る |
| まだら対策 | 上下左右の区画と違う組には罰点(SMOOTH = 40)を足す。境目の段差 1.45 → 1.26(2026-09-27) |
| ディザ | Bayer 4 x 4 で 4 色の中間を点の混ぜ方で出す |
| 色の近さ | CIELAB の距離(RGB だと暗い緑が茶色に寄る)。表を前もって作って速くする |
| ファミコンの色 | agnes の表(PC の試験台の画面とドット単位で比べられるように) |

### 6.4 PC の音(pcaudio.py)

| 項目 | 内容 |
|---|---|
| 録り方 | WASAPI のループバックで既定の再生デバイスの音を録る(ctypes で COM を呼ぶ)。共有モード、溜め 200ms、20ms ごとに読む |
| 変換 | 各チャンネルを平均してモノラル、3 点の移動平均で高い音を少し落としてから、直線補間で 32kHz に |
| 形式 | `pcm16`(64KB/秒)/ `pcm8`(32KB/秒)/ `adpcm`(IMA、16KB/秒)。既定は USB 直結 `pcm16`、Wi-Fi `pcm8` |
| 聞き比べ(2026-09-27) | ADPCM は「サー」という雑音、16 ビットがいちばん綺麗、8 ビットは少し震えるが ADPCM より良い。「音より画面重視」で Wi-Fi は 8 ビット |
| 試験 | `python pcaudio.py --test`: ADPCM の往復 SN 比 32dB。1kHz を鳴らしてループバックで 1001Hz として録れる |

### 6.5 ROM の書き込み

| 書き方 | 中身 |
|---|---|
| `load_rom.ps1 game.nes` / `music.nsf` | 1 本(`FCMG`)。マッパー・大きさを表示して、動くものだけ書く |
| `load_rom.ps1 -Remote` | 画面転送モードの印(`FCRD`)を 1 本として書く |
| `load_rom.ps1 -Library フォルダーやファイル [-Remote]` | ライブラリ(`FCLB`)。題名順。題名はファイル名(大文字)、NSF は曲集の題名、`titles.txt`(`ファイル名=題名`)で変えられる |
| 書き込み | picotool で `-o 0x10800000`。magicon が動いていれば自動で書き込みモードにして、書いた後に戻す(`-f`) |

### 6.6 キーボードの割り当て

前に作った拡張端子 ⇔ USB 変換器(Famicom-Expand-USB-Adapter、実機で確認済み)と同じ。SHIFT・GRPH(Alt)・CTR はトグル(RETURN で SHIFT は戻る)、1 キーずつのチャタリング対策(2 回続けて同じなら確定)。記号は JIS 配列の位置で送る。

英字・数字(A〜Z、0〜9)は刻印どおり。それ以外:

| ファミコンのキー | PC で押されるキー | ファミコンのキー | PC で押されるキー |
|---|---|---|---|
| F1 | F1 | ↓ | ↓ |
| F2 | F2 | ESC | Esc |
| F3 | F3 | GRPH | Alt(トグル) |
| F4 | F4 | INS | Insert |
| F5 | F5 | カナ | 半角/全角 |
| F6 | F6 | ← | ← |
| F7 | F7 | SHIFT(左) | Shift(トグル) |
| F8 | F8 | RETURN | Enter |
| , | , | → | → |
| - | - | SHIFT(右) | Shift(トグル) |
| . | . | SPACE | Space |
| / | / | STOP | BackSpace |
| : | : | ↑ | ↑ |
| ; | ; | ¥ | ¥ |
| @ | @ | [ | [ |
| CLR HOME | Home | ] | ] |
| CTR | Ctrl(トグル) | ^ | ^ |
| DEL | BackSpace | _ | ろ(バックスラッシュ) |

## 7. データと通信の形式

数はリトルエンディアン。

### 7.1 フラッシュの使い方

| 番地(フラッシュの先頭から) | 大きさ | 中身 |
|---|---:|---|
| 0x000000 | 8MB | ファームウェア(uf2 で書く。magicon は約 200KB) |
| 0x800000 | 8MB | ROM 置き場: 1 本(`FCMG`)かライブラリ(`FCLB`、127 本まで) |

- XIP の番地では 0x10800000。`load_rom.ps1` は picotool で `-o 0x10800000` に書く。
- 1 本の大きさは PRG + CHR で 384KB まで(RP2350 の SRAM に写して返すため)。ライブラリ全体は 8MB まで。
- ライブラリの項目は 64 バイト(題名 48 + 位置 4 + 長さ 4 + 合計 4 + 予備 4)、題名はメニューで 28 文字まで。

### 7.2 ROM 置き場: 1 本(FCMG)

| 位置 | 大きさ | 中身 |
|---|---:|---|
| 0 | 4 | `"FCMG"` |
| 4 | 4 | 中身の長さ |
| 8 | 4 | 中身のバイトの合計(32 ビット) |
| 12 | 4 | 予備 |
| 16 | 長さ | .nes / .nsf をそのまま、または `"FCRD"`(画面転送モード) |

### 7.3 ROM 置き場: ライブラリ(FCLB)

| 位置 | 大きさ | 中身 |
|---|---:|---|
| 0 | 4 | `"FCLB"` |
| 4 | 4 | 項目の数(1〜127) |
| 8 | 4 | 全体の長さ |
| 12 | 4 | 予備 |
| 16 + 64 × i | 48 | 題名(ASCII、0 で終わる) |
| +48 | 4 | 中身の位置(置き場の先頭から) |
| +52 | 4 | 中身の長さ |
| +56 | 4 | 中身のバイトの合計 |
| +60 | 4 | 予備 |
| 目次の後(16 バイト境界) | — | 中身を並べる(1 本の時と同じ .nes / .nsf / `"FCRD"`、16 バイト境界) |

### 7.4 画面転送の通信

USB でも TCP でも同じ並び。カセットは `FCFR` / `FCAU` を 1 バイトずつ探すので、途中から読み始めても合う。

| パケット | 向き | 並び | 大きさ |
|---|---|---|---:|
| 画面 | PC → カセット | `"FCFR"` + 絵 15360 + パレット 32 + 属性 64 + カーソルの x・y・表示(3) | 15463 |
| 音 | PC → カセット | `"FCAU"` + 形式 1 + サンプル数 2(1〜1024)+ 中身 | 7 + 中身 |
| 入力 | カセット → PC | `"FCIN"` + 16(下の表)。6502 のフレームの数が変わるたび(約 60 回/秒) | 20 |

| 音の形式 | 値 | 中身 |
|---|---:|---|
| 16 ビット PCM | 0 | サンプル × 2 バイト(符号付き) |
| IMA ADPCM | 1 | 最初の値 2 + 段 1 + 4 ビット × サンプル数(下位の 4 ビットが先) |
| 8 ビット PCM | 2 | サンプル × 1 バイト(符号付き) |

| FCIN の位置 | 中身 |
|---|---|
| 0 | パッド(bit7 = A、6 = B、5 = SELECT、4 = START、3 = ↑、2 = ↓、1 = ←、0 = →) |
| 1〜9 | キーボード 9 行(下位 4 ビット = 列 0、上位 4 ビット = 列 1、押すと 0) |
| 10〜14 | 予備(試験用ファームでは受け取った枚数などを入れる) |
| 15 | 6502 のフレームの数 |

### 7.5 画面のデータの並び

| もの | 並び |
|---|---|
| 絵 | タイル行 r(0〜29)、行の中の y(0〜7)、列 c(0〜31)、面 p(0/1)の 1 バイト = `fb[((r × 8 + y) × 32 + c) × 2 + p]`。1 バイト = 横 8 ドットの 1 面 |
| パレット | 背景 16 + スプライト 16(ファミコンの色番号) |
| 属性 | ファミコンの属性テーブル 64 バイトそのまま(16 x 16 ドットごとの組) |
| カーソル | x(0〜255)、y(0〜239)、表示(0/1) |

## 8. 試験と検証の道具

| 道具 | 何を確かめるか |
|---|---|
| `sim/sim.exe`(PC の試験台) | `magicon/cart.c` を PC でビルドし、エミュレーター agnes(MIT)のカセットとして動かす。CPU の全サイクルと PPU の読み出しを PIO と同じ形の値にして渡すので、実機と同じロジックを試せる(試せないのは PIO のナノ秒単位のタイミングだけ)。画面は BMP、音は WAV(`sim/apu.c` で 2A03 の音を作る)。ライブラリを渡すとメニューから始める |
| `sim/run_compare.py` | magicon と agnes 自身のマッパーで動かし、画面を毎フレーム比べる |
| `sim/test_remote.py` | 画面転送: 届いた絵が画面にドット単位でそのまま出るか、カーソル、パッドとキーボードの読み取り |
| `sim/make_test_nsf.py` | バンク切り替えのある試験用 NSF(3 曲) |
| `magicon/test_nsf_driver.py` | NSF ドライバーを 6502 エミュレーター(py65)で動かす |
| `tools/test_keyboard_bridge.py` | キーボードの割り当て・トグル・チャタリング対策(キーは実際には送らない) |
| `usb_test.uf2` + `tools/usb_bench.py` | USB 直結の速さ(ファミコン無し) |
| `wifi_bridge` + `tools/wifi_bench.py` | Wi-Fi → C6 → PC の速さ・遅れ・中身 |
| `host_test.uf2` + `tools/host_bench.py` | Wi-Fi → C6 → RP2350(USB ホスト)の速さと欠け |
| `tools/audio_bench.py` | カセットの音(ドレミを実際の速さで送る。形式を選べる) |
| `tools/pcaudio.py --test` | ADPCM の往復とループバックの録音 |
| debugprobe + OpenOCD | SWD で停止・メモリー・レジスターの読み出し、書き込み(`set USE_CORE 0`)。SWD からのリセットは起動がおかしくなるので、書いた後は電源を入れ直す |

## 9. 性能(測った値)

すべて 2026-09-27、この PC。ファミコンの実機ではまだ測っていない。

| 項目 | 条件 | 結果 |
|---|---|---|
| USB 直結の速さ | Core2350B2 単体 + usb_test、決まったデータを目いっぱい | 614KB/秒 = 最大 40.6 枚/秒、150 枚すべて届く |
| 画面転送(USB 直結) | remote_pc.py、usb_test 相手 | 灰色 29.8 枚/秒、カラー 20.0 枚/秒(PC 側で画面を作る速さで決まる) |
| PC 側で画面を作る速さ | `remote_pc.py --dry-run` | 等倍 約 60 枚/秒、縮小 灰色 約 30 / カラー 約 23 枚/秒 |
| Wi-Fi → C6 → PC | wifi_bench、目いっぱい | 462KB/秒 = 30.6 枚/秒、食い違い 0 |
| 同上の遅れ | 20〜25 枚/秒で送る | 中央 37ms、最大 73〜81ms |
| 画面転送(Wi-Fi、C6 まで) | remote_pc.py --tcp、PC 上の偽のカセット | 灰色 24.5 枚/秒、カラー 19.9 枚/秒 |
| Wi-Fi → C6 → RP2350(USB ホスト) | host_test、TinyUSB 0.21 | 420KB/秒 = 27.8 枚/秒、500 枚すべて届く |
| 同上(TinyUSB 0.18) | host_test | 64KB/秒止まり、返事のデータが化ける |
| 音の溜まり具合 | magicon_wifi + audio_bench、Wi-Fi | 98〜115ms で安定 |
| マッパーの正しさ | sim、手元の 12 本(マッパー 0/1/2/4 の 8 本を agnes と比べる) | 1200 フレームすべて画面が一致 |

## 10. 開発環境

| 用途 | 道具 | 置き場・版 |
|---|---|---|
| RP2350 のビルド | pico-sdk 2.3.1、xPack arm-none-eabi-gcc 15.2.1、CMake 4.4.3、Ninja 1.13.2、picotool / pioasm 2.3.1 | `C:\Users\Yugo\pico`(日本語の無いパスへコピーしてビルド) |
| USB ホスト | TinyUSB 0.21.0 | `C:\Users\Yugo\pico\tinyusb-0.21.0`(host_test・magicon_wifi だけ) |
| SWD | xPack OpenOCD 0.12.0-7、debugprobe v2.3.1(Raspberry Pi Pico) | `C:\Users\Yugo\pico\openocd` |
| PC の試験台 | Zig 0.16.0(C コンパイラー)、agnes(MIT) | `C:\Users\Yugo\pico\zig`、`firmware/sim/agnes` |
| ESP32-C6 | arduino-cli 1.5.1、Arduino-ESP32 3.3.12(C6 の分だけ) | `C:\Users\Yugo\esp` |
| 基板 | KiCad 10(pcbnew を Python から)、Freerouting 2.4.1 | `E:\KiCad` |
| PC のソフト | Python 3.13、Pillow、numpy(書類に pypdf、NSF の試験に py65) | — |
| 書類 | Edge のヘッドレス、`md2pdf.py`(目次・ページ番号) | `Claude\md2pdf.py` |
| 印刷 | Brother DCP-J1270N | — |
| ケース | Bambu Lab P1S | — |

## 11. 制限と未実装

| 項目 | 今 | 逃げ道・予定 |
|---|---|---|
| バッテリーバックアップ | WRAM は電源を切ると消える | WRAM をフラッシュへ保存する |
| 大きい ROM | PRG + CHR 384KB まで | PSRAM(2MB)を使う |
| マッパー | 8 種類 | 必要なものから足す |
| NSF の拡張音源 | 鳴らない | RP2350 で合成して GPIO44 の PWM へ(VRC6 → FDS → N163 → 5B → MMC5 → VRC7)。音の DMA の仕組みを使い回せる |
| PC 直結と Wi-Fi | ファームウェアが別(magicon / magicon_wifi) | USB シリアルとリセット用の窓口を自前で作れば 1 つにできる |
| magicon_wifi の書き換え | BOOTSEL + RESET が要る | Wi-Fi で ROM を送る |
| メニューの題名 | ASCII、28 文字まで | かなのフォントを足す |
| Wi-Fi の音 | 8 ビット(少し震える) | ディザーでならす、または 16 ビットにして画面を少し落とす |
| host_test の UART ログ | debugprobe に届かない | 配線を確かめる |
| GPIO コプロセッサー | host_test で NOCP の HardFault(原因は未解明) | SIO を直接書いて避けている |
| SWD からのリセット | 起動がおかしくなる | 書いた後は電源を入れ直す |

## 12. 確認状況

| 項目 | 状況 |
|---|---|
| カセット端子の信号・電源・音声・/IRQ・向き | 実機・資料で確認済み(2026-09-26) |
| Core2350B2 のピン配置 | 照合シートで実物と全ピン一致 |
| PIO の応答タイミング(CPU・PPU) | **未検証**(基板が届いてから bus_test / chr_test で。TP1〜TP4) |
| CIRAM A10 を 3.3V で動かす(JP1) | **未検証**。駄目なら JP2 / JP3 |
| マッパー(0/1/2/3/4/7/87/184) | PC の試験台で確認済み(12 本。0/1/2/4 は agnes と全フレーム一致) |
| NSF プレイヤー | PC の試験台と py65 で確認済み |
| 画面転送(絵・カーソル・パッド・キーボード) | PC の試験台で確認済み(ドット単位で一致) |
| キーボードの割り当て | `test_keyboard_bridge.py` で確認済み。割り当ては変換器で実機確認済み |
| ゲーム選択メニュー | PC の試験台で確認済み(37 項目、ページ送り、ゲーム・NSF・画面転送が始まる)。**実機では未検証**(1.5 秒の間に再起動が間に合うか) |
| ROM の書き込み(load_rom.ps1) | Core2350B2 単体で確認済み(mario3 384KB、-Remote)。`-Library` は引数の受け取りまで |
| USB 直結の速さ | Core2350B2 単体で確認済み(614KB/秒) |
| Wi-Fi(C6)→ USB | PC 相手・RP2350(USB ホスト)相手で確認済み |
| magicon_wifi | Core2350B2 単体で 1 枚目が裏画面に入るまで確認。**ファミコンでは未検証** |
| PC の音 | Core2350B2 単体 + Wi-Fi でイヤホンで確認。**ファミコンの音声(46 番)に混ぜては未検証**(VR1・R8 で合わせる) |
| 本体の電源の見張り(5V が消えたら再起動) | **未検証** |

## 13. 部品表

`kicad/bom.csv` から作った。

| 部品 | 数 | 記号 | フットプリント | メモ |
|---|---:|---|---|---|
| 10µF 電解 | 1 | C1 | CP_Radial_D5.0mm_P2.00mm | 16V以上、φ5 ピッチ2mm |
| 100nF セラミック | 1 | C2 | C_Disc_D3.0mm_W1.6mm_P2.50mm | U2 のパスコン |
| 10nF セラミック | 1 | C3 | C_Disc_D3.0mm_W1.6mm_P2.50mm | PWM の RC フィルタ |
| 10µF 電解 | 1 | C4 | CP_Radial_D5.0mm_P2.00mm | φ5 ピッチ2mm。+側=SOUND_OUT(四角パッド)。ライン出力の直流カット。1µFフィルムでも可 |
| 1N4001〜1N4007(ショットキー 1A があればそちら) | 1 | D1 | D_DO-41_SOD81_P7.62mm_Horizontal | 本体5V→モジュール。USB給電時の逆流防止。省略不可 |
| PJ-324M | 1 | J2 | PJ-324M | 3.5mm ステレオジャック(SHVC-SOUND-ESP32 と同じ) |
| ピンヘッダー 1x3 | 1 | J3 | PinHeader_1x03_P2.54mm_Vertical | SWD(debugprobe の Pico 用) |
| ピンヘッダー or ピンソケット 2x30 | 1 | J4 | PinHeader_2x30_P2.54mm_Vertical | カセット60ピンのブレイクアウト。必要な時だけでもよい |
| ピンヘッダー 2x8 | 1 | J5 | PinHeader_2x08_P2.54mm_Vertical | デバッグ用(内部信号) |
| ピンヘッダー 1x4(任意) | 1 | J6 | PinHeader_1x04_P2.54mm_Vertical | USB の予備ランド(5V/D-/D+/GND)。FPC 側と同時に機器をつながない |
| 2SC1815 | 1 | Q1 | TO-92_Inline_Wide | TO-92 NPN。足は平らな面から E-C-B。他の小信号NPNでも可(足順に注意)。下(J4 側)へ倒して付ける |
| 0Ω(ジャンパー線でも可) | 1 | R1 | R_Axial_DIN0207_L6.3mm_D2.5mm_P7.62mm_Horizontal | CIRAM /CE ← /A13。裏面に付ける(表は Q1 を倒す場所)。表の足先は短く切る |
| 15kΩ 1/4W | 1 | R2 | R_Axial_DIN0207_L6.3mm_D2.5mm_P7.62mm_Horizontal |  |
| 22kΩ 1/4W | 1 | R3 | R_Axial_DIN0207_L6.3mm_D2.5mm_P7.62mm_Horizontal |  |
| 4.7kΩ 1/4W | 1 | R4 | R_Axial_DIN0207_L6.3mm_D2.5mm_P7.62mm_Horizontal |  |
| 100kΩ 1/4W | 1 | R5 | R_Axial_DIN0207_L6.3mm_D2.5mm_P7.62mm_Horizontal |  |
| 10kΩ(未実装) | 1 | R6 | R_Axial_DIN0207_L6.3mm_D2.5mm_P7.62mm_Horizontal | 本体に /IRQ のプルアップが無い時だけ付ける |
| 0Ω(ジャンパー線でも可) | 1 | R7 | R_Axial_DIN0207_L6.3mm_D2.5mm_P7.62mm_Horizontal | 音声 45→46番の素通し |
| 47kΩ | 1 | R8 | R_Axial_DIN0207_L6.3mm_D2.5mm_P7.62mm_Horizontal | 拡張音源を46番に混ぜる抵抗(VR1 の中点から) |
| 1kΩ 1/4W | 1 | R9 | R_Axial_DIN0207_L6.3mm_D2.5mm_P7.62mm_Horizontal |  |
| 47kΩ 1/4W | 1 | R10 | R_Axial_DIN0207_L6.3mm_D2.5mm_P7.62mm_Horizontal |  |
| 100Ω 1/4W | 1 | R11 | R_Axial_DIN0207_L6.3mm_D2.5mm_P7.62mm_Horizontal |  |
| タクトスイッチ 6mm | 1 | SW1 | SW_PUSH_6mm | BOOTSEL |
| タクトスイッチ 6mm | 1 | SW2 | SW_PUSH_6mm | RESET(RP2350のRUN) |
| 74LVC245 DIP-20 | 1 | U2 | DIP-20_W7.62mm | SN74LVC245AN。5V入力を3.3Vへ。74HC/HCT245 では代用不可(5V入力に耐えない) |
| 半固定抵抗 100kΩ KOA KVSF637AC104 | 1 | VR1 | KOA_SF6_637A | 拡張音源の音量。上面調整、足 ①③ 5.0mm・② は 5.0mm 上 |
| Waveshare Core2350B2 | 1 | U1 |  | RP2350B、2MB PSRAM。付属のFPC-USBアダプターで PC とつなぐ |
| ピンソケット 2x8(2.54mm) | 4 | P1-P4 |  | Core2350B を載せる。モジュール側には 2x8 ピンヘッダー4個 |
| ピンヘッダー 2x8(2.54mm) | 4 | (モジュール側) |  | Core2350B の裏に付ける |
| ICソケット DIP-20 | 1 | (U2) |  | 任意 |
| PCB 90x65.8mm 2層 1.2mm | 1 |  |  | 金メッキ端子(Gold fingers)、差し込み側 45°面取り |

## 付録 A. ピン・接続の一覧

ネットリスト(`kicad/FC-MAGICON.net`)から `kicad/gen_spec_tables.py` が作った表。

### カセット端子 J1(60ピン)

| 番 | 面 | 信号 | つながる先 |
|---:|---|---|---|
| 1 | 表(手前) | GND | GND(全部品共通) |
| 2 | 表(手前) | CPU_A11 | P3-5(GPIO19) |
| 3 | 表(手前) | CPU_A10 | P3-6(GPIO18) |
| 4 | 表(手前) | CPU_A9 | P3-3(GPIO17) |
| 5 | 表(手前) | CPU_A8 | P3-4(GPIO16) |
| 6 | 表(手前) | CPU_A7 | P3-2(GPIO15) |
| 7 | 表(手前) | CPU_A6 | P1-15(GPIO14) |
| 8 | 表(手前) | CPU_A5 | P1-16(GPIO13) |
| 9 | 表(手前) | CPU_A4 | P1-13(GPIO12) |
| 10 | 表(手前) | CPU_A3 | P1-14(GPIO11) |
| 11 | 表(手前) | CPU_A2 | P1-11(GPIO10) |
| 12 | 表(手前) | CPU_A1 | P1-12(GPIO9) |
| 13 | 表(手前) | CPU_A0 | P1-9(GPIO8) |
| 14 | 表(手前) | CPU_R/W | P3-12(GPIO24) |
| 15 | 表(手前) | /IRQ | Q1.2, R6.2 |
| 16 | 表(手前) | GND | GND(全部品共通) |
| 17 | 表(手前) | PPU_/RD | TP1.1, U2.2 |
| 18 | 表(手前) | CIRAM_A10 | J5.11, JP1.2, JP2.2, JP3.2 |
| 19 | 表(手前) | PPU_A6 | — |
| 20 | 表(手前) | PPU_A5 | — |
| 21 | 表(手前) | PPU_A4 | — |
| 22 | 表(手前) | PPU_A3 | — |
| 23 | 表(手前) | PPU_A2 | — |
| 24 | 表(手前) | PPU_A1 | — |
| 25 | 表(手前) | PPU_A0 | — |
| 26 | 表(手前) | PPU_D0 | P3-14(GPIO26), TP2.1 |
| 27 | 表(手前) | PPU_D1 | P3-13(GPIO27) |
| 28 | 表(手前) | PPU_D2 | P3-16(GPIO28) |
| 29 | 表(手前) | PPU_D3 | P3-15(GPIO29) |
| 30 | 表(手前) | +5V | D1.2, R2.1, R6.1 |
| 31 | 裏(奥) | +5V | D1.2, R2.1, R6.1 |
| 32 | 裏(奥) | M2 | P3-11(GPIO25), TP3.1 |
| 33 | 裏(奥) | CPU_A12 | P3-8(GPIO20) |
| 34 | 裏(奥) | CPU_A13 | P3-7(GPIO21) |
| 35 | 裏(奥) | CPU_A14 | P3-10(GPIO22) |
| 36 | 裏(奥) | CPU_D7 | P1-10(GPIO7) |
| 37 | 裏(奥) | CPU_D6 | P1-7(GPIO6) |
| 38 | 裏(奥) | CPU_D5 | P1-8(GPIO5) |
| 39 | 裏(奥) | CPU_D4 | P1-5(GPIO4) |
| 40 | 裏(奥) | CPU_D3 | P1-6(GPIO3) |
| 41 | 裏(奥) | CPU_D2 | P1-3(GPIO2) |
| 42 | 裏(奥) | CPU_D1 | P1-4(GPIO1) |
| 43 | 裏(奥) | CPU_D0 | P1-2(GPIO0) |
| 44 | 裏(奥) | /ROMSEL | P3-9(GPIO23), TP4.1 |
| 45 | 裏(奥) | SOUND_IN | R7.1 |
| 46 | 裏(奥) | SOUND_OUT | C4.1, R7.2, R8.2 |
| 47 | 裏(奥) | PPU_/WR | U2.3 |
| 48 | 裏(奥) | CIRAM_/CE | R1.2 |
| 49 | 裏(奥) | PPU_/A13 | R1.1 |
| 50 | 裏(奥) | PPU_A7 | — |
| 51 | 裏(奥) | PPU_A8 | P4-5(GPIO34) |
| 52 | 裏(奥) | PPU_A9 | P4-8(GPIO35) |
| 53 | 裏(奥) | PPU_A10 | JP2.1, P4-7(GPIO36) |
| 54 | 裏(奥) | PPU_A11 | JP3.1, P4-10(GPIO37) |
| 55 | 裏(奥) | PPU_A12 | P4-9(GPIO38) |
| 56 | 裏(奥) | PPU_A13 | U2.4 |
| 57 | 裏(奥) | PPU_D7 | P4-6(GPIO33) |
| 58 | 裏(奥) | PPU_D6 | P4-3(GPIO32) |
| 59 | 裏(奥) | PPU_D5 | P4-4(GPIO31) |
| 60 | 裏(奥) | PPU_D4 | P4-2(GPIO30) |

### Core2350B のピン(ヘッダー P1〜P4)

| ヘッダー-ピン | モジュールのピン | 信号 | つながる先 |
|---|---|---|---|
| P1-2 | GPIO0 | CPU_D0 | J1.43 |
| P1-4 | GPIO1 | CPU_D1 | J1.42 |
| P1-3 | GPIO2 | CPU_D2 | J1.41 |
| P1-6 | GPIO3 | CPU_D3 | J1.40 |
| P1-5 | GPIO4 | CPU_D4 | J1.39 |
| P1-8 | GPIO5 | CPU_D5 | J1.38 |
| P1-7 | GPIO6 | CPU_D6 | J1.37 |
| P1-10 | GPIO7 | CPU_D7 | J1.36 |
| P1-9 | GPIO8 | CPU_A0 | J1.13 |
| P1-12 | GPIO9 | CPU_A1 | J1.12 |
| P1-11 | GPIO10 | CPU_A2 | J1.11 |
| P1-14 | GPIO11 | CPU_A3 | J1.10 |
| P1-13 | GPIO12 | CPU_A4 | J1.9 |
| P1-16 | GPIO13 | CPU_A5 | J1.8 |
| P1-15 | GPIO14 | CPU_A6 | J1.7 |
| P3-2 | GPIO15 | CPU_A7 | J1.6 |
| P3-4 | GPIO16 | CPU_A8 | J1.5 |
| P3-3 | GPIO17 | CPU_A9 | J1.4 |
| P3-6 | GPIO18 | CPU_A10 | J1.3 |
| P3-5 | GPIO19 | CPU_A11 | J1.2 |
| P3-8 | GPIO20 | CPU_A12 | J1.33 |
| P3-7 | GPIO21 | CPU_A13 | J1.34 |
| P3-10 | GPIO22 | CPU_A14 | J1.35 |
| P3-9 | GPIO23 | /ROMSEL | J1.44, TP4.1 |
| P3-12 | GPIO24 | CPU_R/W | J1.14 |
| P3-11 | GPIO25 | M2 | J1.32, TP3.1 |
| P3-14 | GPIO26 | PPU_D0 | J1.26, TP2.1 |
| P3-13 | GPIO27 | PPU_D1 | J1.27 |
| P3-16 | GPIO28 | PPU_D2 | J1.28 |
| P3-15 | GPIO29 | PPU_D3 | J1.29 |
| P4-2 | GPIO30 | PPU_D4 | J1.60 |
| P4-4 | GPIO31 | PPU_D5 | J1.59 |
| P4-3 | GPIO32 | PPU_D6 | J1.58 |
| P4-6 | GPIO33 | PPU_D7 | J1.57 |
| P4-5 | GPIO34 | PPU_A8 | J1.51 |
| P4-8 | GPIO35 | PPU_A9 | J1.52 |
| P4-7 | GPIO36 | PPU_A10 | J1.53, JP2.1 |
| P4-10 | GPIO37 | PPU_A11 | J1.54, JP3.1 |
| P4-9 | GPIO38 | PPU_A12 | J1.55 |
| P4-12 | GPIO39 | (未接続) | — |
| P4-11 | GPIO40 | PPU_/RD_3V3 | U2.18 |
| P4-14 | GPIO41 | PPU_/WR_3V3 | U2.17 |
| P4-13 | GPIO42 | PPU_A13_3V3 | U2.16 |
| P4-16 | GPIO43 | CIRAM_A10_MCU | JP1.1 |
| P4-15 | GPIO44 | EXP_AUDIO_PWM | R9.1 |
| P2-2 | GPIO45 | IRQ_DRV | R4.1 |
| P2-4 | GPIO46 | FC_5V_SENSE | R2.2, R3.1 |
| P2-3 | GPIO47_PSRAM_CS | (未接続) | — |
| P1-1 | GND | GND | GND(全部品共通) |
| P2-1 | GND | GND | GND(全部品共通) |
| P2-5 | BOOTSEL | BOOTSEL | SW1.1 |
| P2-6 | SWD | SWD | J3.3 |
| P2-7 | USBD_N | USBD_N | J6.2 |
| P2-8 | GND | GND | GND(全部品共通) |
| P2-9 | USBD_P | USBD_P | J6.3 |
| P2-10 | SWCLK | SWCLK | J3.1 |
| P2-11 | RUN | RUN | SW2.1 |
| P2-12 | ADC_VREF | (未接続) | — |
| P2-13 | 3V3_EN | (未接続) | — |
| P2-14 | GND | GND | GND(全部品共通) |
| P2-15 | VBUS | VBUS_MOD | C1.1, D1.1, J6.1 |
| P2-16 | 3V3 | +3V3 | C2.1, U2.1, U2.20 |
| P3-1 | GND | GND | GND(全部品共通) |
| P4-1 | GND | GND | GND(全部品共通) |

### J4 ブレイクアウト(2x30)

列 k(左から 1〜30)の下の列 = カセット k 番、上の列 = カセット k+30 番。

| 列 | 下の列(ヘッダー番号) | カセット番・信号 | 上の列(ヘッダー番号) | カセット番・信号 |
|---:|---:|---|---:|---|
| 1 | 1 | 1: GND | 2 | 31: +5V |
| 2 | 3 | 2: CPU_A11 | 4 | 32: M2 |
| 3 | 5 | 3: CPU_A10 | 6 | 33: CPU_A12 |
| 4 | 7 | 4: CPU_A9 | 8 | 34: CPU_A13 |
| 5 | 9 | 5: CPU_A8 | 10 | 35: CPU_A14 |
| 6 | 11 | 6: CPU_A7 | 12 | 36: CPU_D7 |
| 7 | 13 | 7: CPU_A6 | 14 | 37: CPU_D6 |
| 8 | 15 | 8: CPU_A5 | 16 | 38: CPU_D5 |
| 9 | 17 | 9: CPU_A4 | 18 | 39: CPU_D4 |
| 10 | 19 | 10: CPU_A3 | 20 | 40: CPU_D3 |
| 11 | 21 | 11: CPU_A2 | 22 | 41: CPU_D2 |
| 12 | 23 | 12: CPU_A1 | 24 | 42: CPU_D1 |
| 13 | 25 | 13: CPU_A0 | 26 | 43: CPU_D0 |
| 14 | 27 | 14: CPU_R/W | 28 | 44: /ROMSEL |
| 15 | 29 | 15: /IRQ | 30 | 45: SOUND_IN |
| 16 | 31 | 16: GND | 32 | 46: SOUND_OUT |
| 17 | 33 | 17: PPU_/RD | 34 | 47: PPU_/WR |
| 18 | 35 | 18: CIRAM_A10 | 36 | 48: CIRAM_/CE |
| 19 | 37 | 19: PPU_A6 | 38 | 49: PPU_/A13 |
| 20 | 39 | 20: PPU_A5 | 40 | 50: PPU_A7 |
| 21 | 41 | 21: PPU_A4 | 42 | 51: PPU_A8 |
| 22 | 43 | 22: PPU_A3 | 44 | 52: PPU_A9 |
| 23 | 45 | 23: PPU_A2 | 46 | 53: PPU_A10 |
| 24 | 47 | 24: PPU_A1 | 48 | 54: PPU_A11 |
| 25 | 49 | 25: PPU_A0 | 50 | 55: PPU_A12 |
| 26 | 51 | 26: PPU_D0 | 52 | 56: PPU_A13 |
| 27 | 53 | 27: PPU_D1 | 54 | 57: PPU_D7 |
| 28 | 55 | 28: PPU_D2 | 56 | 58: PPU_D6 |
| 29 | 57 | 29: PPU_D3 | 58 | 59: PPU_D5 |
| 30 | 59 | 30: +5V | 60 | 60: PPU_D4 |

### J5 デバッグ(2x8)

| ピン | 信号 | つながる先 |
|---:|---|---|
| 1 | PPU_/RD_3V3 | P4-11(GPIO40), U2.18 |
| 2 | PPU_/WR_3V3 | P4-14(GPIO41), U2.17 |
| 3 | PPU_A13_3V3 | P4-13(GPIO42), U2.16 |
| 4 | CIRAM_A10_MCU | JP1.1, P4-16(GPIO43) |
| 5 | EXP_AUDIO_PWM | P4-15(GPIO44), R9.1 |
| 6 | EXP_AUDIO_RC | C3.1, R9.2, VR1.1 |
| 7 | IRQ_DRV | P2-2(GPIO45), R4.1 |
| 8 | FC_5V_SENSE | P2-4(GPIO46), R2.2, R3.1 |
| 9 | +3V3 | C2.1, P2-16(3V3), U2.1, U2.20 |
| 10 | VBUS_MOD | C1.1, D1.1, J6.1, P2-15(VBUS) |
| 11 | CIRAM_A10 | J1.18, JP1.2, JP2.2, JP3.2 |
| 12 | GND | GND(全部品共通) |
| 13 | GND | GND(全部品共通) |
| 14 | GND | GND(全部品共通) |
| 15 | GND | GND(全部品共通) |
| 16 | GND | GND(全部品共通) |

### 周辺部品の接続

| 部品-ピン | 信号 |
|---|---|
| U2-1 (DIR) | +3V3 |
| U2-2 (A1) | PPU_/RD |
| U2-3 (A2) | PPU_/WR |
| U2-4 (A3) | PPU_A13 |
| U2-5 (A4) | GND |
| U2-6 (A5) | GND |
| U2-7 (A6) | GND |
| U2-8 (A7) | GND |
| U2-9 (A8) | GND |
| U2-10 (GND) | GND |
| U2-11 (B8) | (未接続) |
| U2-12 (B7) | (未接続) |
| U2-13 (B6) | (未接続) |
| U2-14 (B5) | (未接続) |
| U2-15 (B4) | (未接続) |
| U2-16 (B3) | PPU_A13_3V3 |
| U2-17 (B2) | PPU_/WR_3V3 |
| U2-18 (B1) | PPU_/RD_3V3 |
| U2-19 (/OE) | GND |
| U2-20 (VCC) | +3V3 |
| Q1-1 (E) | GND |
| Q1-2 (C) | /IRQ |
| Q1-3 (B) | Q1_B |
| D1-1 | VBUS_MOD |
| D1-2 | +5V |
| C1-1 | VBUS_MOD |
| C1-2 | GND |
| C2-1 | +3V3 |
| C2-2 | GND |
| C3-1 | EXP_AUDIO_RC |
| C3-2 | GND |
| C4-1 | SOUND_OUT |
| C4-2 | LOUT |
| R1-1 | PPU_/A13 |
| R1-2 | CIRAM_/CE |
| R2-1 | +5V |
| R2-2 | FC_5V_SENSE |
| R3-1 | FC_5V_SENSE |
| R3-2 | GND |
| R4-1 | IRQ_DRV |
| R4-2 | Q1_B |
| R5-1 | Q1_B |
| R5-2 | GND |
| R6-1 | +5V |
| R6-2 | /IRQ |
| R7-1 | SOUND_IN |
| R7-2 | SOUND_OUT |
| R8-1 | EXP_AUDIO_VR |
| R8-2 | SOUND_OUT |
| R9-1 | EXP_AUDIO_PWM |
| R9-2 | EXP_AUDIO_RC |
| R10-1 | LOUT |
| R10-2 | GND |
| R11-1 | LINE |
| R11-2 | LOUT |
| JP1-1 | CIRAM_A10_MCU |
| JP1-2 | CIRAM_A10 |
| JP2-1 | PPU_A10 |
| JP2-2 | CIRAM_A10 |
| JP3-1 | PPU_A11 |
| JP3-2 | CIRAM_A10 |
| SW1-1 | BOOTSEL |
| SW1-2 | GND |
| SW2-1 | RUN |
| SW2-2 | GND |
| J2-1 (SLEEVE) | GND |
| J2-2 (RING) | LINE |
| J2-3 (RING_SW) | (未接続) |
| J2-4 (TIP) | LINE |
| J2-5 (TIP_SW) | (未接続) |
| J3-1 | SWCLK |
| J3-2 | GND |
| J3-3 | SWD |
| TP1-1 (TP) | PPU_/RD |
| TP2-1 (TP) | PPU_D0 |
| TP3-1 (TP) | M2 |
| TP4-1 (TP) | /ROMSEL |
| TP5-1 (TP) | GND |

## 付録 B. ソフトウェアの規模

| まとまり | ファイル | 行 |
|---|---:|---:|
| カセット(RP2350、C) | 11 | 1,769 |
| 6502 プログラムを作る Python | 6 | 824 |
| Wi-Fi ブリッジ(ESP32-C6) | 1 | 137 |
| PC のアプリ・道具(Python / PowerShell) | 11 | 1,785 |
| PC の試験台(C、agnes を除く) | 6 | 927 |
| 基板(KiCad を動かす Python) | 22 | 2,456 |
| 書類を作るスクリプト | 3 | 368 |

(生成したヘッダー(`*_driver.h` など)、agnes、ビルド済みのファイルは数えていない)

## 関係するファイル

| ファイル | 内容 |
|---|---|
| `README.md` | リポジトリの説明とピン割り当て |
| `docs/system_spec.pdf`(この書類)、`docs/build_system_spec.py`、`docs/system_spec_body.md` | 総合仕様書とその作り方 |
| `docs/hardware_spec.pdf`、`docs/hardware_spec_body.md` | ハードウェア仕様書(3 章の元) |
| `docs/user_manual.pdf` | 使い方の手順書 |
| `kicad/` | 回路図・基板・ガーバー(`FC-MAGICON_gerber_r0.2.zip`)・部品表・作るスクリプト |
| `firmware/magicon/` | カセットのファームウェア(`main.c`・`cart.c`・`audio.c`・PIO・ドライバーを作る Python) |
| `firmware/bus_test/`、`chr_test/`、`usb_test/`、`host_test/` | 試験用のファームウェア |
| `firmware/wifi_bridge/` | ESP32-C6 の Wi-Fi ブリッジ |
| `firmware/tools/` | PC のアプリと道具 |
| `firmware/sim/` | PC の試験台 |
| `firmware/out/` | ビルド済みのファームウェア |
| `3d/` | STEP(部品あり / なし) |
| `case/` | ケースの調査とシール(`case/label/`) |
| `images/` | 基板の 3D 画像とロゴ |

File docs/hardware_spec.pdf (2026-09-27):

# FC-MAGICON ハードウェア仕様書 rev0.2

## 1. 概要

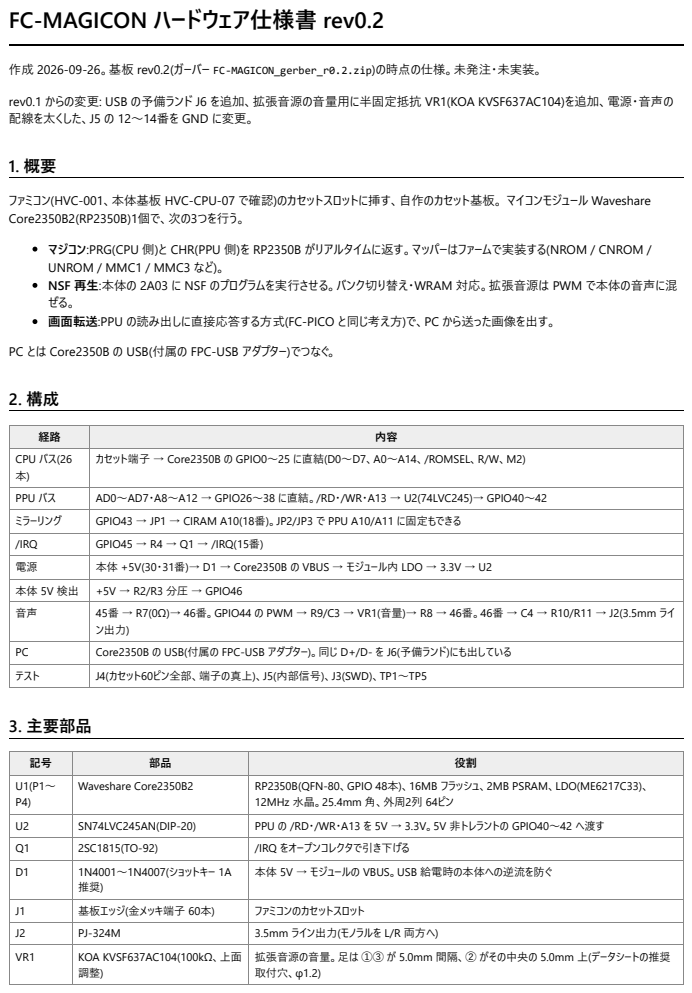
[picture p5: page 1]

作成 2026-09-26。基板 rev0.2(ガーバー FC-MAGICON_gerber_r0.2.zip)の時点の仕様。未発注・未実装。

rev0.1 からの変更: USB の予備ランド J6 を追加、拡張音源の音量用に半固定抵抗 VR1(KOA KVSF637AC104)を追加、電源・音声の
配線を太くした、J5 の 12〜14番を GND に変更。

ファミコン(HVC-001、本体基板 HVC-CPU-07 で確認)のカセットスロットに挿す、自作のカセット基板。 マイコンモジュール Waveshare
Core2350B2(RP2350B)1個で、次の3つを行う。
マジコン:PRG(CPU 側)と CHR(PPU 側)を RP2350B がリアルタイムに返す。マッパーはファームで実装する(NROM / CNROM /
UNROM / MMC1 / MMC3 など)。
NSF 再生:本体の 2A03 に NSF のプログラムを実行させる。バンク切り替え・WRAM 対応。拡張音源は PWM で本体の音声に混
画面転送:PPU の読み出しに直接応答する方式(FC-PICO と同じ考え方)で、PC から送った画像を出す。
PC とは Core2350B の USB(付属の FPC-USB アダプター)でつなぐ。

経路 | 内容
CPU バス(26 本) | カセット端子 → Core2350B の GPIO0〜25 に直結(D0〜D7、A0〜A14、/ROMSEL、R/W、M2)

PPU バス | AD0〜AD7・A8〜A12 → GPIO26〜38 に直結。/RD・/WR・A13 → U2(74LVC245)→ GPIO40〜42
ミラーリング | GPIO43 → JP1 → CIRAM A10(18番)。JP2/JP3 で PPU A10/A11 に固定もできる
/IRQ | GPIO45 → R4 → Q1 → /IRQ(15番)
電源 | 本体 +5V(30・31番)→ D1 → Core2350B の VBUS → モジュール内 LDO → 3.3V → U2
本体 5V 検出 | +5V → R2/R3 分圧 → GPIO46
音声 | 45番 → R7(0Ω)→ 46番。GPIO44 の PWM → R9/C3 → VR1(音量)→ R8 → 46番。46番 → C4 → R10/R11 → J2(3.5mm ライ ン出力)

PC | Core2350B の USB(付属の FPC-USB アダプター)。同じ D+/D- を J6(予備ランド)にも出している
テスト | J4(カセット60ピン全部、端子の真上)、J5(内部信号)、J3(SWD)、TP1〜TP5

記号 | 部品 | 役割
U1(P1〜 P4) | Waveshare Core2350B2 | RP2350B(QFN-80、GPIO 48本)、16MB フラッシュ、2MB PSRAM、LDO(ME6217C33)、 12MHz 水晶。25.4mm 角、外周2列 64ピン

U2 | SN74LVC245AN(DIP-20) | PPU の /RD・/WR・A13 を 5V → 3.3V。5V 非トレラントの GPIO40〜42 へ渡す
Q1 | 2SC1815(TO-92) | /IRQ をオープンコレクタで引き下げる
D1 | 1N4001〜1N4007(ショットキー 1A 推奨) | 本体 5V → モジュールの VBUS。USB 給電時の本体への逆流を防ぐ

J1 | 基板エッジ(金メッキ端子 60本) | ファミコンのカセットスロット
J2 | PJ-324M | 3.5mm ライン出力(モノラルを L/R 両方へ)
VR1 | KOA KVSF637AC104(100kΩ、上面 調整) | 拡張音源の音量。足は ①③ が 5.0mm 間隔、② がその中央の 5.0mm 上(データシートの推奨 取付穴、φ1.2)

## 4. 電源

項目 | 値
供給元 | 本体の +5V(カセット端子 30・31番)。GND は 1・16番
モジュールへの経路 | +5V → D1 → VBUS_MOD(モジュール P2-15 VBUS)→ モジュール内 LDO → +3V3
VBUS_MOD の電圧 | 1N400x で約 4.3V、ショットキーなら約 4.6V(LDO の入力として十分)
+3V3 の使い道 | モジュールの 3V3 出力(P2-16)を U2 の電源と DIR に使う。C2 100nF をパスコンに
平滑 | C1 10µF(VBUS_MOD)
USB 給電 | Core2350B の USB からも VBUS に入る。D1 があるので本体側の +5V へは流れない
消費電流(見込み) | モジュール数十 mA 〜 100mA 程度(RP2350B のクロック次第)。本体の 7805 の範囲内

逆流に注意:USB だけで給電している時(本体の電源が切れている時)に RP2350B がバスへ出力すると、 電源の入っていない本体の IC に 3.3V が流れ込む。これを避けるため、本体の 5V を分圧して GPIO46 で監視する(7章)。

## 5. バスの接続と電圧

### 5.1 CPU バス(26本、すべて RP2350B に直結)

信号 | GPIO | 向き
CPU D0〜D7 | 0〜7 | 双方向(読み出し時だけ RP2350B が出力)
CPU A0〜A14 | 8〜22(A0 から連続) | 入力
/ROMSEL | 23 | 入力(= !(A15 & M2))
R/W | 24 | 入力
M2 | 25 | 入力

### 5.2 PPU バス

信号 | GPIO | 向き・経路
PPU AD0〜AD7(カセット端子の PPU D0〜D7) | 26〜33 | 双方向。/RD が下がる直前はアドレス下位 8 ビット、その後データ
PPU A8〜A12 | 34〜38 | 入力。GPIO26〜38 で 13 ビットのアドレスが連続する
PPU /RD | 40 | U2 経由の入力
PPU /WR | 41 | U2 経由の入力
PPU A13 | 42 | U2 経由の入力(カセット端子 56番、非反転)
PPU /A13 | — | CIRAM /CE(48番)へ R1(0Ω)で直結。RP2350B にはつながない
PPU A0〜A7(ラッチ後) | — | RP2350B では使わない。J4 には出してある

### 5.3 電圧の扱い

GPIO | 5V を受けられるか | この基板での使い方
0〜38 | 可(IOVDD に電源が入って いる時) | 5V のバス信号を直接受ける
39 | 可 | モジュール上の LED(470Ω)が付いているので使わない
40〜47(ADC 兼 用) | 不可 | 40〜42 は U2(3.3V 電源の 74LVC245)の後。43〜46 は出力専用か分圧後の入力。47 はモジュ ール上の PSRAM の CS

RP2350B の出力は 3.3V。2A03・PPU(NMOS)の入力は H を 2.0〜2.4V 程度から認識するので受けられる。
U2:DIR = +3V3(A→B)、/OE = GND(常に有効)。A 側(5V)に /RD・/WR・A13、B 側(3.3V)から GPIO40〜42。空き入力 A4〜 A8 は GND。74LVC は電源が無い時も入力に 5V を受けられる。

## 6. PPU アドレスの読み取り方

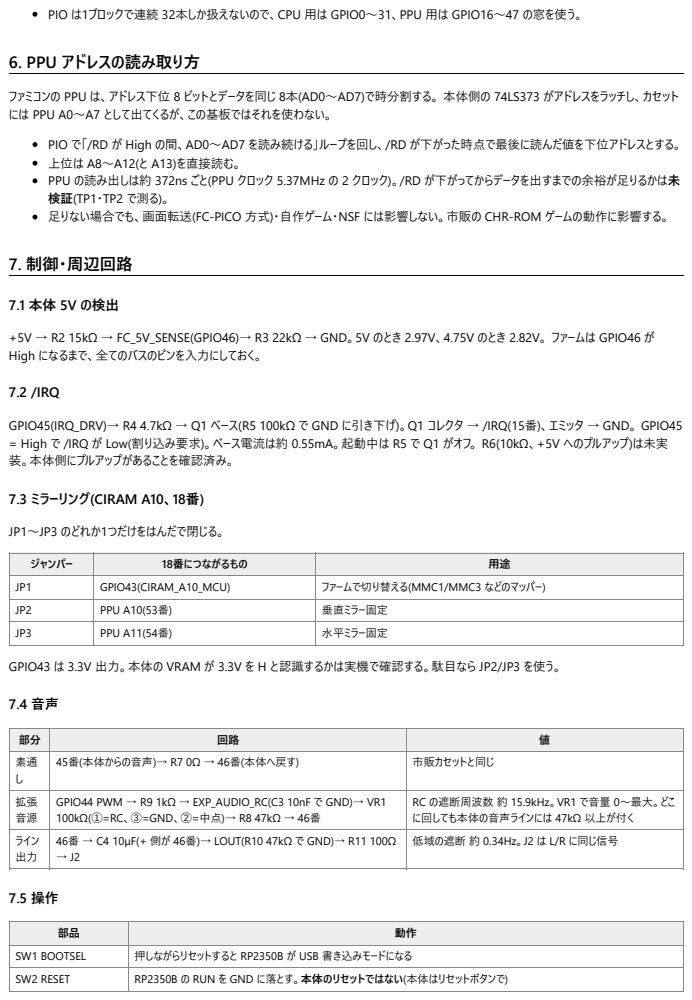
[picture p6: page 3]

PIO は1ブロックで連続 32本しか扱えないので、CPU 用は GPIO0〜31、PPU 用は GPIO16〜47 の窓を使う。

ファミコンの PPU は、アドレス下位 8 ビットとデータを同じ 8本(AD0〜AD7)で時分割する。 本体側の 74LS373 がアドレスをラッチし、カセット
には PPU A0〜A7 として出てくるが、この基板ではそれを使わない。
PIO で「/RD が High の間、AD0〜AD7 を読み続ける」ループを回し、/RD が下がった時点で最後に読んだ値を下位アドレスとする。
上位は A8〜A12(と A13)を直接読む。
PPU の読み出しは約 372ns ごと(PPU クロック 5.37MHz の 2 クロック)。/RD が下がってからデータを出すまでの余裕が足りるかは未
検証(TP1・TP2 で測る)。
足りない場合でも、画面転送(FC-PICO 方式)・自作ゲーム・NSF には影響しない。市販の CHR-ROM ゲームの動作に影響する。

+5V → R2 15kΩ → FC_5V_SENSE(GPIO46)→ R3 22kΩ → GND。5V のとき 2.97V、4.75V のとき 2.82V。 ファームは GPIO46 が
High になるまで、全てのバスのピンを入力にしておく。

GPIO45(IRQ_DRV)→ R4 4.7kΩ → Q1 ベース(R5 100kΩ で GND に引き下げ)。Q1 コレクタ → /IRQ(15番)、エミッタ → GND。 GPIO45
= High で /IRQ が Low(割り込み要求)。ベース電流は約 0.55mA。起動中は R5 で Q1 がオフ。 R6(10kΩ、+5V へのプルアップ)は未実
装。本体側にプルアップがあることを確認済み。

ジャンパー | 18番につながるもの | 用途
JP1 | GPIO43(CIRAM_A10_MCU) | ファームで切り替える(MMC1/MMC3 などのマッパー)
JP2 | PPU A10(53番) | 垂直ミラー固定
JP3 | PPU A11(54番) | 水平ミラー固定

GPIO43 は 3.3V 出力。本体の VRAM が 3.3V を H と認識するかは実機で確認する。駄目なら JP2/JP3 を使う。

部分 | 回路 | 値
素通 し | 45番(本体からの音声)→ R7 0Ω → 46番(本体へ戻す) | 市販カセットと同じ

拡張 音源 | GPIO44 PWM → R9 1kΩ → EXP_AUDIO_RC(C3 10nF で GND)→ VR1 100kΩ(①=RC、③=GND、②=中点)→ R8 47kΩ → 46番 | RC の遮断周波数 約 15.9kHz。VR1 で音量 0〜最大。どこ に回しても本体の音声ラインには 47kΩ 以上が付く

ライン 出力 | 46番 → C4 10µF(+ 側が 46番)→ LOUT(R10 47kΩ で GND)→ R11 100Ω → J2 | 低域の遮断 約 0.34Hz。J2 は L/R に同じ信号

部品 | 動作
SW1 BOOTSEL | 押しながらリセットすると RP2350B が USB 書き込みモードになる
SW2 RESET | RP2350B の RUN を GND に落とす。本体のリセットではない(本体はリセットボタンで)

## 8. デバッグ・テスト用

記号 | 内容
J3 | SWD(1=SWCLK、2=GND、3=SWDIO)。debugprobe の Pico をつなぐ
J4 | カセット60ピン全部(2x30、2.54mm)。差し込み部のすぐ上で、各列が真下の端子と同じ信号。本体に入る高さなのでランドとして使う想定
J5 | 内部信号(2x8、2.54mm)。上辺。12〜14番は GND(元の LOUT・Q1_B・LINE は2層に収めるために外した。J2・R10・R11・Q1 の足で測れ る)
J6 | USB の予備ランド(1x4、2.54mm、1=5V(VBUS)、2=D-、3=D+、4=GND)。モジュールの FPC と同じ USB 信号。FPC 側と同時に機器をつ ながない。VBUS は本体給電時 D1 の後の約 4.3V
TP1〜 TP5 | /RD、PPU D0、M2、/ROMSEL、GND。オシロのプローブ用(穴 0.7mm)

## 9. 機械仕様

項目 | 値
外形 | 90.0 × 65.8mm(本体 90.0 × 55.1mm + 差し込み部 78.4 × 10.7mm)。規格の基板(56.8mm)より 9mm 高い
厚み | 1.2mm
端子 | 60本、2.54mm ピッチ。部品面(表)= 1〜30番、裏 = 31〜60番。部品面から見て左端が 1/31番
端子の寸法 | 信号 1.6 × 5.7mm。1・30・31番は 2.6mm 幅、1・16・30・31番は差し込み側へ 1mm 長い(先に接触)
向き | 部品面を本体の手前に向けて挿す(市販カセットのラベル面と同じ側に 1〜30番)
レジスト | 端子部は抜いてある(端子の上端の 0.6mm 上から先端まで)
部品 | 部品面。ただし R1 だけ裏面(Q1 を下へ倒して寝かせるため、2026-09-26 に移した)。スルーホール部品のみ(表面実装はソルダージャンパ ーと端子だけ)
シルク | 表面: ロゴ(幅 19.5mm)と「rev0.2」。裏面: ロゴ(34mm)・「MADE BY SHIMA-R7」・スペック表(モジュールのソケットの内側)
モジュールの高 さ | ピンソケットで載せるので、基板から約 13mm
コンデンサー | C1〜C4 は足を曲げて右へ寝かせる前提。倒した本体の範囲は部品禁止(シルクに枠と「lay →」)
J2 | 3.5mm ジャックの差し込み口が左辺から約 3.6mm 外へ出る
ケース | printables 860420 のシェル(CC BY 4.0)を改造して、Bambu Lab P1S で 3D プリントする(2026-09-27 時点でユーザーが編集中)

## 10. 基板の製造仕様

項目 | 値
層数 | 2(F.Cu / B.Cu)。GND ベタを両面に、GND スティッチングビアあり
配線幅 | 信号 0.25mm(IC の足の間で最小 0.15mm)。+5V 0.8mm(端子31番から J4 への枝だけ 0.5mm)、VBUS_MOD 0.6mm、GND 0.5mm、+3V3 0.4mm、音声 0.4mm
クリアラン ス | 0.2mm
ビア | 径 0.6mm / 穴 0.3mm
端子部 | 端子の隙間・両脇・先端は配線・ビア・ベタ禁止。配線はパッドの上端から入る
DRC | エラー 0、未接続 0(2026-09-26)。フットプリントをライブラリから書き換えた旨の通知 9件のみ
発注 | JLCPCB(2026-09-27 の時点で発注済み・未着)。厚み 1.2mm、黒、HASL(有鉛)、Gold Fingers、差し込み側 45° 面取り、5枚

## 11. ファームウェアが守ること

1. 起動時は全バスピンを入力にし、GPIO46(本体 5V 検出)が High になってから出力を許す。

2. CPU D0〜D7 を出力するのは、読み出しサイクル(/ROMSEL = Low かつ R/W = High、または $6000〜$7FFF の WRAM 読み 出し)の間だけ。
3. PPU AD0〜AD7 を出力するのは、/RD = Low かつ A13 = Low(パターンテーブル)の間だけ。A13 = High(ネームテーブル)の時は本 体の VRAM が出力する。
4. RP2350 のエラッタ E9:バスのピンで内部プルダウンを使わない。
5. GPIO39(LED)・GPIO47(PSRAM CS)をバスに使わない。
6. /IRQ は GPIO45 = High で要求、Low で解除。
7. 電源投入直後は本体の CPU が RP2350B の起動を待たずに動く。間に合わなければ本体のリセットボタンを押す。

## 12. 確認状況

項目 | 状態
カセット端子の信号線 51本 | 自作ダンパー(FC フォルダ)で実機確認済み
電源・音声・/IRQ・CIRAM 関係のピン | 資料2つ(nesdev、fc-rom-vomitter)と一致。2026-09-26 に麻雀カセット・本体で導通確認済み
45/46番の向き、/IRQ のプルアップ | 2026-09-26 実機で確認済み
差し込む向き(表裏) | 厚紙の実物合わせとテスターで確認済み
Core2350B のピン配置 | 照合シートで実物のシルクと全ピン一致を確認
/RD → データの応答時間 | 未検証(基板で TP1・TP2 を測る)
CIRAM A10 を 3.3V で駆動 | 未検証(駄目なら JP2/JP3)
拡張音源の音量 | VR1 で調整
VR1 の足の配置 | データシート(KOA SF6、637A の推奨取付穴)どおり。実物が届いたら穴に合うか確認

## 13. 部品表

部品 | 数 | 記号 | フットプリント | メモ
10µF 電解 | 1 | C1 | CP_Radial_D5.0mm_P2.00mm | 16V以上、φ5 ピッチ2mm
100nF セラミック | 1 | C2 | C_Disc_D3.0mm_W1.6mm_P2.50mm | U2 のパスコン
10nF セラミック | 1 | C3 | C_Disc_D3.0mm_W1.6mm_P2.50mm | PWM の RC フィルタ
10µF 電解 | 1 | C4 | CP_Radial_D5.0mm_P2.00mm | φ5 ピッチ2mm。+側=SOUND_OUT(四 角パッド)。ライン出力の直流カット。1µFフ ィルムでも可
1N4001〜1N4007(ショ ットキー 1A があればそち ら) | 1 | D1 | D_DO-41_SOD81_P7.62mm_Horizontal | 本体5V→モジュール。USB給電時の逆流 防止。省略不可
PJ-324M | 1 | J2 | PJ-324M | 3.5mm ステレオジャック(SHVC-SOUND-ESP32 と同じ)
ピンヘッダー 1x3 | 1 | J3 | PinHeader_1x03_P2.54mm_Vertical | SWD(debugprobe の Pico 用)
ピンヘッダー or ピンソケッ ト 2x30 | 1 | J4 | PinHeader_2x30_P2.54mm_Vertical | カセット60ピンのブレイクアウト。必要な時 だけでもよい
ピンヘッダー 2x8 | 1 | J5 | PinHeader_2x08_P2.54mm_Vertical | デバッグ用(内部信号)
ピンヘッダー 1x4(任意) | 1 | J6 | PinHeader_1x04_P2.54mm_Vertical | USB の予備ランド(5V/D-/D+/GND)。 FPC 側と同時に機器をつながない
2SC1815 | 1 | Q1 | TO-92_Inline_Wide | TO-92 NPN。足は平らな面から E-C-B。 他の小信号NPNでも可(足順に注意)。 下(J4 側)へ倒して付ける
0Ω(ジャンパー線でも可) | 1 | R1 | R_Axial_DIN0207_L6.3mm_D2.5mm_P7.62mm_Horizontal | CIRAM /CE ← /A13。裏面に付ける(表 は Q1 を倒す場所)。表の足先は短く切る
15kΩ 1/4W | 1 | R2 | R_Axial_DIN0207_L6.3mm_D2.5mm_P7.62mm_Horizontal

部品 | 数 | 記号 | フットプリント | メモ
22kΩ 1/4W | 1 | R3 | R_Axial_DIN0207_L6.3mm_D2.5mm_P7.62mm_Horizontal
4.7kΩ 1/4W | 1 | R4 | R_Axial_DIN0207_L6.3mm_D2.5mm_P7.62mm_Horizontal
100kΩ 1/4W | 1 | R5 | R_Axial_DIN0207_L6.3mm_D2.5mm_P7.62mm_Horizontal
10kΩ(未実装) | 1 | R6 | R_Axial_DIN0207_L6.3mm_D2.5mm_P7.62mm_Horizontal | 本体に /IRQ のプルアップが無い時だけ付 ける
0Ω(ジャンパー線でも可) | 1 | R7 | R_Axial_DIN0207_L6.3mm_D2.5mm_P7.62mm_Horizontal | 音声 45→46番の素通し
47kΩ | 1 | R8 | R_Axial_DIN0207_L6.3mm_D2.5mm_P7.62mm_Horizontal | 拡張音源を46番に混ぜる抵抗(VR1 の中 点から)
1kΩ 1/4W | 1 | R9 | R_Axial_DIN0207_L6.3mm_D2.5mm_P7.62mm_Horizontal
47kΩ 1/4W | 1 | R10 | R_Axial_DIN0207_L6.3mm_D2.5mm_P7.62mm_Horizontal
100Ω 1/4W | 1 | R11 | R_Axial_DIN0207_L6.3mm_D2.5mm_P7.62mm_Horizontal
タクトスイッチ 6mm | 1 | SW1 | SW_PUSH_6mm | BOOTSEL
タクトスイッチ 6mm | 1 | SW2 | SW_PUSH_6mm | RESET(RP2350のRUN)
74LVC245 DIP-20 | 1 | U2 | DIP-20_W7.62mm | SN74LVC245AN。5V入力を3.3Vへ。 74HC/HCT245 では代用不可(5V入力 に耐えない)
半固定抵抗 100kΩ KOA KVSF637AC104 | 1 | VR1 | KOA_SF6_637A | 拡張音源の音量。上面調整、足 ①③ 5.0mm・② は 5.0mm 上
Waveshare Core2350B2 | 1 | U1 | | RP2350B、2MB PSRAM。付属のFPC-USBアダプターで PC とつなぐ
ピンソケット 2x8(2.54mm) | 4 | P1-P4 | | Core2350B を載せる。モジュール側には 2x8 ピンヘッダー4個
ピンヘッダー 2x8(2.54mm) | 4 | (モジュ ール側) | | Core2350B の裏に付ける
ICソケット DIP-20 | 1 | (U2) | | 任意
PCB 90x65.8mm 2層 1.2mm | 1 | | | 金メッキ端子(Gold fingers)、差し込み側 45°面取り

## 付録. ピン・接続の一覧(ネットリストから自動生成)

### カセット端子 J1(60ピン)

番 | 面 | 信号 | つながる先
1 | 表(手前) | GND | GND(全部品共通)
2 | 表(手前) | CPU_A11 | P3-5(GPIO19)
3 | 表(手前) | CPU_A10 | P3-6(GPIO18)
4 | 表(手前) | CPU_A9 | P3-3(GPIO17)
5 | 表(手前) | CPU_A8 | P3-4(GPIO16)
6 | 表(手前) | CPU_A7 | P3-2(GPIO15)
7 | 表(手前) | CPU_A6 | P1-15(GPIO14)
8 | 表(手前) | CPU_A5 | P1-16(GPIO13)
9 | 表(手前) | CPU_A4 | P1-13(GPIO12)
10 | 表(手前) | CPU_A3 | P1-14(GPIO11)
11 | 表(手前) | CPU_A2 | P1-11(GPIO10)
12 | 表(手前) | CPU_A1 | P1-12(GPIO9)

番 | 面 | 信号 | つながる先
13 | 表(手前) | CPU_A0 | P1-9(GPIO8)
14 | 表(手前) | CPU_R/W | P3-12(GPIO24)
15 | 表(手前) | /IRQ | Q1.2, R6.2
16 | 表(手前) | GND | GND(全部品共通)
17 | 表(手前) | PPU_/RD | TP1.1, U2.2
18 | 表(手前) | CIRAM_A10 | J5.11, JP1.2, JP2.2, JP3.2
19 | 表(手前) | PPU_A6 | —
20 | 表(手前) | PPU_A5 | —
21 | 表(手前) | PPU_A4 | —
22 | 表(手前) | PPU_A3 | —
23 | 表(手前) | PPU_A2 | —
24 | 表(手前) | PPU_A1 | —
25 | 表(手前) | PPU_A0 | —
26 | 表(手前) | PPU_D0 | P3-14(GPIO26), TP2.1
27 | 表(手前) | PPU_D1 | P3-13(GPIO27)
28 | 表(手前) | PPU_D2 | P3-16(GPIO28)
29 | 表(手前) | PPU_D3 | P3-15(GPIO29)
30 | 表(手前) | +5V | D1.2, R2.1, R6.1
31 | 裏(奥) | +5V | D1.2, R2.1, R6.1
32 | 裏(奥) | M2 | P3-11(GPIO25), TP3.1
33 | 裏(奥) | CPU_A12 | P3-8(GPIO20)
34 | 裏(奥) | CPU_A13 | P3-7(GPIO21)
35 | 裏(奥) | CPU_A14 | P3-10(GPIO22)
36 | 裏(奥) | CPU_D7 | P1-10(GPIO7)
37 | 裏(奥) | CPU_D6 | P1-7(GPIO6)
38 | 裏(奥) | CPU_D5 | P1-8(GPIO5)
39 | 裏(奥) | CPU_D4 | P1-5(GPIO4)
40 | 裏(奥) | CPU_D3 | P1-6(GPIO3)
41 | 裏(奥) | CPU_D2 | P1-3(GPIO2)
42 | 裏(奥) | CPU_D1 | P1-4(GPIO1)
43 | 裏(奥) | CPU_D0 | P1-2(GPIO0)
44 | 裏(奥) | /ROMSEL | P3-9(GPIO23), TP4.1
45 | 裏(奥) | SOUND_IN | R7.1
46 | 裏(奥) | SOUND_OUT | C4.1, R7.2, R8.2
47 | 裏(奥) | PPU_/WR | U2.3
48 | 裏(奥) | CIRAM_/CE | R1.2
49 | 裏(奥) | PPU_/A13 | R1.1
50 | 裏(奥) | PPU_A7 | —
51 | 裏(奥) | PPU_A8 | P4-5(GPIO34)
52 | 裏(奥) | PPU_A9 | P4-8(GPIO35)
53 | 裏(奥) | PPU_A10 | JP2.1, P4-7(GPIO36)
54 | 裏(奥) | PPU_A11 | JP3.1, P4-10(GPIO37)

番 | 面 | 信号 | つながる先
55 | 裏(奥) | PPU_A12 | P4-9(GPIO38)
56 | 裏(奥) | PPU_A13 | U2.4
57 | 裏(奥) | PPU_D7 | P4-6(GPIO33)
58 | 裏(奥) | PPU_D6 | P4-3(GPIO32)
59 | 裏(奥) | PPU_D5 | P4-4(GPIO31)
60 | 裏(奥) | PPU_D4 | P4-2(GPIO30)

### Core2350B のピン(ヘッダー P1〜P4)

ヘッダー-ピン | モジュールのピン | 信号 | つながる先
P1-2 | GPIO0 | CPU_D0 | J1.43
P1-4 | GPIO1 | CPU_D1 | J1.42
P1-3 | GPIO2 | CPU_D2 | J1.41
P1-6 | GPIO3 | CPU_D3 | J1.40
P1-5 | GPIO4 | CPU_D4 | J1.39
P1-8 | GPIO5 | CPU_D5 | J1.38
P1-7 | GPIO6 | CPU_D6 | J1.37
P1-10 | GPIO7 | CPU_D7 | J1.36
P1-9 | GPIO8 | CPU_A0 | J1.13
P1-12 | GPIO9 | CPU_A1 | J1.12
P1-11 | GPIO10 | CPU_A2 | J1.11
P1-14 | GPIO11 | CPU_A3 | J1.10
P1-13 | GPIO12 | CPU_A4 | J1.9
P1-16 | GPIO13 | CPU_A5 | J1.8
P1-15 | GPIO14 | CPU_A6 | J1.7
P3-2 | GPIO15 | CPU_A7 | J1.6
P3-4 | GPIO16 | CPU_A8 | J1.5
P3-3 | GPIO17 | CPU_A9 | J1.4
P3-6 | GPIO18 | CPU_A10 | J1.3
P3-5 | GPIO19 | CPU_A11 | J1.2
P3-8 | GPIO20 | CPU_A12 | J1.33
P3-7 | GPIO21 | CPU_A13 | J1.34
P3-10 | GPIO22 | CPU_A14 | J1.35
P3-9 | GPIO23 | /ROMSEL | J1.44, TP4.1
P3-12 | GPIO24 | CPU_R/W | J1.14
P3-11 | GPIO25 | M2 | J1.32, TP3.1
P3-14 | GPIO26 | PPU_D0 | J1.26, TP2.1
P3-13 | GPIO27 | PPU_D1 | J1.27
P3-16 | GPIO28 | PPU_D2 | J1.28
P3-15 | GPIO29 | PPU_D3 | J1.29
P4-2 | GPIO30 | PPU_D4 | J1.60
P4-4 | GPIO31 | PPU_D5 | J1.59
P4-3 | GPIO32 | PPU_D6 | J1.58

ヘッダー-ピン | モジュールのピン | 信号 | つながる先
P4-6 | GPIO33 | PPU_D7 | J1.57
P4-5 | GPIO34 | PPU_A8 | J1.51
P4-8 | GPIO35 | PPU_A9 | J1.52
P4-7 | GPIO36 | PPU_A10 | J1.53, JP2.1
P4-10 | GPIO37 | PPU_A11 | J1.54, JP3.1
P4-9 | GPIO38 | PPU_A12 | J1.55
P4-12 | GPIO39 | (未接続) | —
P4-11 | GPIO40 | PPU_/RD_3V3 | U2.18
P4-14 | GPIO41 | PPU_/WR_3V3 | U2.17
P4-13 | GPIO42 | PPU_A13_3V3 | U2.16
P4-16 | GPIO43 | CIRAM_A10_MCU | JP1.1
P4-15 | GPIO44 | EXP_AUDIO_PWM | R9.1
P2-2 | GPIO45 | IRQ_DRV | R4.1
P2-4 | GPIO46 | FC_5V_SENSE | R2.2, R3.1
P2-3 | GPIO47_PSRAM_CS | (未接続) | —
P1-1 | GND | GND | GND(全部品共通)
P2-1 | GND | GND | GND(全部品共通)
P2-5 | BOOTSEL | BOOTSEL | SW1.1
P2-6 | SWD | SWD | J3.3
P2-7 | USBD_N | USBD_N | J6.2
P2-8 | GND | GND | GND(全部品共通)
P2-9 | USBD_P | USBD_P | J6.3
P2-10 | SWCLK | SWCLK | J3.1
P2-11 | RUN | RUN | SW2.1
P2-12 | ADC_VREF | (未接続) | —
P2-13 | 3V3_EN | (未接続) | —
P2-14 | GND | GND | GND(全部品共通)
P2-15 | VBUS | VBUS_MOD | C1.1, D1.1, J6.1
P2-16 | 3V3 | +3V3 | C2.1, U2.1, U2.20
P3-1 | GND | GND | GND(全部品共通)
P4-1 | GND | GND | GND(全部品共通)

### J4 ブレイクアウト(2x30)

列 k(左から 1〜30)の下の列 = カセット k 番、上の列 = カセット k+30 番。

列 | 下の列(ヘッダー番号) | カセット番・信号 | 上の列(ヘッダー番号) | カセット番・信号
1 | 1 | 1: GND | 2 | 31: +5V
2 | 3 | 2: CPU_A11 | 4 | 32: M2
3 | 5 | 3: CPU_A10 | 6 | 33: CPU_A12
4 | 7 | 4: CPU_A9 | 8 | 34: CPU_A13
5 | 9 | 5: CPU_A8 | 10 | 35: CPU_A14
6 | 11 | 6: CPU_A7 | 12 | 36: CPU_D7

列 | 下の列(ヘッダー番号) | カセット番・信号 | 上の列(ヘッダー番号) | カセット番・信号
7 | 13 | 7: CPU_A6 | 14 | 37: CPU_D6
8 | 15 | 8: CPU_A5 | 16 | 38: CPU_D5
9 | 17 | 9: CPU_A4 | 18 | 39: CPU_D4
10 | 19 | 10: CPU_A3 | 20 | 40: CPU_D3
11 | 21 | 11: CPU_A2 | 22 | 41: CPU_D2
12 | 23 | 12: CPU_A1 | 24 | 42: CPU_D1
13 | 25 | 13: CPU_A0 | 26 | 43: CPU_D0
14 | 27 | 14: CPU_R/W | 28 | 44: /ROMSEL
15 | 29 | 15: /IRQ | 30 | 45: SOUND_IN
16 | 31 | 16: GND | 32 | 46: SOUND_OUT
17 | 33 | 17: PPU_/RD | 34 | 47: PPU_/WR
18 | 35 | 18: CIRAM_A10 | 36 | 48: CIRAM_/CE
19 | 37 | 19: PPU_A6 | 38 | 49: PPU_/A13
20 | 39 | 20: PPU_A5 | 40 | 50: PPU_A7
21 | 41 | 21: PPU_A4 | 42 | 51: PPU_A8
22 | 43 | 22: PPU_A3 | 44 | 52: PPU_A9
23 | 45 | 23: PPU_A2 | 46 | 53: PPU_A10
24 | 47 | 24: PPU_A1 | 48 | 54: PPU_A11
25 | 49 | 25: PPU_A0 | 50 | 55: PPU_A12
26 | 51 | 26: PPU_D0 | 52 | 56: PPU_A13
27 | 53 | 27: PPU_D1 | 54 | 57: PPU_D7
28 | 55 | 28: PPU_D2 | 56 | 58: PPU_D6
29 | 57 | 29: PPU_D3 | 58 | 59: PPU_D5
30 | 59 | 30: +5V | 60 | 60: PPU_D4

### J5 デバッグ(2x8)

ピン | 信号 | つながる先
1 | PPU_/RD_3V3 | P4-11(GPIO40), U2.18
2 | PPU_/WR_3V3 | P4-14(GPIO41), U2.17
3 | PPU_A13_3V3 | P4-13(GPIO42), U2.16
4 | CIRAM_A10_MCU | JP1.1, P4-16(GPIO43)
5 | EXP_AUDIO_PWM | P4-15(GPIO44), R9.1
6 | EXP_AUDIO_RC | C3.1, R9.2, VR1.1
7 | IRQ_DRV | P2-2(GPIO45), R4.1
8 | FC_5V_SENSE | P2-4(GPIO46), R2.2, R3.1
9 | +3V3 | C2.1, P2-16(3V3), U2.1, U2.20
10 | VBUS_MOD | C1.1, D1.1, J6.1, P2-15(VBUS)
11 | CIRAM_A10 | J1.18, JP1.2, JP2.2, JP3.2
12 | GND | GND(全部品共通)
13 | GND | GND(全部品共通)
14 | GND | GND(全部品共通)
15 | GND | GND(全部品共通)

ピン | 信号 | つながる先
16 | GND | GND(全部品共通)

### 周辺部品の接続

部品-ピン | 信号
U2-1 (DIR) | +3V3
U2-2 (A1) | PPU_/RD
U2-3 (A2) | PPU_/WR
U2-4 (A3) | PPU_A13
U2-5 (A4) | GND
U2-6 (A5) | GND
U2-7 (A6) | GND
U2-8 (A7) | GND
U2-9 (A8) | GND
U2-10 (GND) | GND
U2-11 (B8) | (未接続)
U2-12 (B7) | (未接続)
U2-13 (B6) | (未接続)
U2-14 (B5) | (未接続)
U2-15 (B4) | (未接続)
U2-16 (B3) | PPU_A13_3V3
U2-17 (B2) | PPU_/WR_3V3
U2-18 (B1) | PPU_/RD_3V3
U2-19 (/OE) | GND
U2-20 (VCC) | +3V3
Q1-1 (E) | GND
Q1-2 (C) | /IRQ
Q1-3 (B) | Q1_B
D1-1 | VBUS_MOD
D1-2 | +5V
C1-1 | VBUS_MOD
C1-2 | GND
C2-1 | +3V3
C2-2 | GND
C3-1 | EXP_AUDIO_RC
C3-2 | GND
C4-1 | SOUND_OUT
C4-2 | LOUT
R1-1 | PPU_/A13
R1-2 | CIRAM_/CE
R2-1 | +5V
R2-2 | FC_5V_SENSE
R3-1 | FC_5V_SENSE

部品-ピン | 信号
R3-2 | GND
R4-1 | IRQ_DRV
R4-2 | Q1_B
R5-1 | Q1_B
R5-2 | GND
R6-1 | +5V
R6-2 | /IRQ
R7-1 | SOUND_IN
R7-2 | SOUND_OUT
R8-1 | EXP_AUDIO_VR
R8-2 | SOUND_OUT
R9-1 | EXP_AUDIO_PWM
R9-2 | EXP_AUDIO_RC
R10-1 | LOUT
R10-2 | GND
R11-1 | LINE
R11-2 | LOUT
JP1-1 | CIRAM_A10_MCU
JP1-2 | CIRAM_A10
JP2-1 | PPU_A10
JP2-2 | CIRAM_A10
JP3-1 | PPU_A11
JP3-2 | CIRAM_A10
SW1-1 | BOOTSEL
SW1-2 | GND
SW2-1 | RUN
SW2-2 | GND
J2-1 (SLEEVE) | GND
J2-2 (RING) | LINE
J2-3 (RING_SW) | (未接続)
J2-4 (TIP) | LINE
J2-5 (TIP_SW) | (未接続)
J3-1 | SWCLK
J3-2 | GND
J3-3 | SWD
TP1-1 (TP) | PPU_/RD
TP2-1 (TP) | PPU_D0
TP3-1 (TP) | M2
TP4-1 (TP) | /ROMSEL
TP5-1 (TP) | GND

## ファイル

ファイル | 内容
kicad/gen_schematic.py | 回路図を生成(FC-MAGICON.kicad_sch)
kicad/gen_footprints.py | カセット端子のフットプリントを生成
kicad/build_pcb.py | 部品配置(place)、配線の取り込みとベタ(import)、一部の配線やり直し(reroute)
kicad/route.py | Freerouting で自動配線
kicad/add_part.py / sync_nets.py / hand_route.py | 配線済みの基板に部品を足す / パッドのネットを回路図に合わせる / 1本だけ手で引く
kicad/export_gerbers.ps1 | DRC を確認してガーバーと zip(FC-MAGICON_gerber_r0.2.zip)を出力
images/board_front.png ほか | 基板の3D画像(正面・背面・斜め、kicad-cli pcb render)
kicad/bom.py / print_bom.ps1 | 部品表の作成と印刷
kicad/print_fit_check.ps1 | 実寸の現物合わせシートを印刷
kicad/gen_spec_tables.py / docs/build_spec.py | この仕様書を作る

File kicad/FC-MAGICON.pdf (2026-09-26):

1 | 2 | 3 | 4 | 5 | 6 | 7 | 8 | 9 | 10 | 11
1 | 2 | 3 | 4 | 5 | 6 | 7 | 8 | 9 | 10 | 11

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
FGH Date:

Size: A2 | Rev: 0.1
KiCad E.D.A. 10.0.6 | Id: 1/1

## Title: FC-MAGICON (Core2350B)

File: FC-MAGICON.kicad_sch

Sheet: /

C2

100n GND 1 | GPIO45 | 2 GPIO47_PSRAM_CS 3 | GPIO46 | 4 BOOTSEL 5
SWD | 6 USBD_N 7 | GND | 8 USBD_P 9
SWCLK | 10 RUN 11 | ADC_VREF | 12
3V3_EN 13 | GND | 14
VBUS 15 | 3V3 | 16 P2 Core2350B P2
E | 1 C

2 B

3 Q1

2SC1815

R2

15k | R3 22k

TP 1

TP4 /ROMSEL

DIR 1

A1 2
A2 3
A3 4
A4 5
A5 6
A6 7
A7 8
A8 9 | GND 10 | B8 | 11 B7 | 12 B6 | 13 B5 | 14 B4 | 15 B3 | 16 B2 | 17 B1 | 18 OE 19
VCC 20 | U2
74LVC245 (5V->3.3V) | SW1 BOOTSEL

JP1 MCU

C1
10u

TP 1

# TP5 GND

C3

# 10n R5 100k

JP3 H (A11)

R8

# 47k SW2 RESET

R9

1k | R6 10k DNP

R4
4.7k R7

0

SLEEVE 1 | RING
2 | RING_SW
3 | TIP

4
TIP_SW

5

J2

LINE OUT 3.5mm

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
GND 1 | GPIO0 | 2 GPIO2 3 | GPIO1 | 4 GPIO4 5 | GPIO3 | 6 GPIO6 7 | GPIO5 | 8 GPIO8 9 | GPIO7 | 10 GPIO10 11 | GPIO9 | 12 GPIO12 13 | GPIO11 | 14 GPIO14 15 | GPIO13 | 16 P1 Core2350B P1

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
# J5 Debug 2x8

JP2
V (A10)

1

1 W
2
| 3

3

VR1 KVSF637AC104 R10

47k

VBUS

1 | D-
2 | D+
3 | GND
4

J6 USB spare land

C4

10u (+ to SOUND_OUT) | 1:GND

1

31:+5V 2
2:CPU_A11

3
32:M2

4
3:CPU_A10

5
33:CPU_A12

6
4:CPU_A9

7
34:CPU_A13

8
5:CPU_A8

9
35:CPU_A14

10
6:CPU_A7

11
36:CPU_D7

12
7:CPU_A6

13
37:CPU_D6

14
8:CPU_A5

15
38:CPU_D5

16
9:CPU_A4

17
39:CPU_D4

18
10:CPU_A3

19
40:CPU_D3

20
11:CPU_A2

21
41:CPU_D2

22
12:CPU_A1

23
42:CPU_D1

24
13:CPU_A0

25
43:CPU_D0

26
14:CPU_RW

27

44:ROMSEL 28
15:IRQ

29
45:SOUND_IN

30
16:GND

31

46:SOUND_OUT 32
17:PPU_RD

33
47:PPU_WR

34
18:CIRAM_A10

35

48:CIRAM_CE 36
19:PPU_A6

37
49:PPU_A13

38
20:PPU_A5

39
50:PPU_A7

40
21:PPU_A4

41
51:PPU_A8

42
22:PPU_A3

43
52:PPU_A9

44
23:PPU_A2

45
53:PPU_A10

46
24:PPU_A1

47
54:PPU_A11

48
25:PPU_A0

49
55:PPU_A12

50
26:PPU_D0

51
56:PPU_A13

52
27:PPU_D1

53
57:PPU_D7

54
28:PPU_D2

55
58:PPU_D6

56
29:PPU_D3

57
59:PPU_D5

58
30:+5V 59
60:PPU_D4

60

J4 Cart breakout 2x30 R11

100 GND 1 | CPU_A11 2 | CPU_A10 3 | CPU_A9 4 | CPU_A8 5 | CPU_A7 6 | CPU_A6 7 | CPU_A5 8 | CPU_A4 9 | CPU_A3 10 | CPU_A2 11 | CPU_A1 12 | CPU_A0 13 | CPU_RW

14

IRQ 15 | GND 16 | PPU_RD 17 | CIRAM_A10 18 | PPU_A6 19 | PPU_A5 20 | PPU_A4 21 | PPU_A3 22 | PPU_A2 23 | PPU_A1 24 | PPU_A0 25 | PPU_D0 26 | PPU_D1 27 | PPU_D2 28 | PPU_D3 29 | +5V 30 | +5V | 31 M2 | 32 CPU_A12 | 33 CPU_A13 | 34 CPU_A14 | 35 CPU_D7 | 36 CPU_D6 | 37 CPU_D5 | 38 CPU_D4 | 39 CPU_D3 | 40 CPU_D2 | 41 CPU_D1 | 42 CPU_D0 | 43 ROMSEL | 44
SOUND_IN | | | | | | | | | | | | | | | 45
SOUND_OUT | 46 PPU_WR | 47 CIRAM_CE | 48 PPU_A13 | 49 PPU_A7 | 50 PPU_A8 | 51 PPU_A9 | 52 PPU_A10 | 53 PPU_A11 | 54 PPU_A12 | 55 PPU_A13 | 56 PPU_D7 | 57 PPU_D6 | 58 PPU_D5 | 59 PPU_D4 | 60

J1

Famicom cart edge 60p | R1

0

TP 1

TP2 PPU_D0 GND 1 | GPIO30 | 2 GPIO32 3 | GPIO31 | 4 GPIO34 5 | GPIO33 | 6 GPIO36 7 | GPIO35 | 8 GPIO38 9 | GPIO37 | 10 GPIO40 11 | GPIO39 | 12 GPIO42 13 | GPIO41 | 14 GPIO44 15 | GPIO43 | 16 P4 Core2350B P4
GND 1 | GPIO15 | 2 GPIO17 3 | GPIO16 | 4 GPIO19 5 | GPIO18 | 6 GPIO21 7 | GPIO20 | 8 GPIO23 9 | GPIO22 | 10 GPIO25 11 | GPIO24 | 12 GPIO27 13 | GPIO26 | 14 GPIO29 15 | GPIO28 | 16 P3 Core2350B P3

TP 1

# TP3 M2 D1

1N4001

TP 1

TP1 PPU_/RD
PPU_RD | VBUS_MOD +5V | SWD

# GNDFC_5V_SENSE GND

SWCLK

PPU_A1 PPU_A0 PPU_D0 PPU_D1 PPU_D2

LINE | PPU_D3 +5V PPU_A10 | PPU_A11 | CPU_A8 CPU_A7 CPU_A6 CPU_RW

PPU_RD

GND

IRQ

CIRAM_A10 PPU_A5 PPU_A4 PPU_A3 PPU_A2 | +5V M2 CPU_A12 CPU_A13 CPU_A14 CPU_D7 CPU_D6 CPU_D5 CPU_D4 CPU_D3 CPU_D2 CPU_D1 CPU_D0 ROMSEL SOUND_IN

SOUND_OUT PPU_WR

CIRAM_CE PPU_A13 PPU_A7 PPU_A8 PPU_A9 PPU_A10 PPU_A11 CPU_A11 CPU_A10 CPU_A9 CPU_A5 CPU_A4 GND SOUND_OUT | LOUT BOOTSEL USBD_N

USBD_P
RUN
VBUS_MOD | EXP_AUDIO_VR GND | SOUND_OUT EXP_AUDIO_RC SOUND_IN | EXP_AUDIO_PWM | EXP_AUDIO_RC

GND

EXP_AUDIO_RC
EXP_AUDIO_VR SOUND_OUT +3V3 GND | GND BOOTSEL | RUN
CPU_A3 CPU_A2 CPU_A1 CPU_A0 PPU_A6 CIRAM_A10 | CIRAM_A10 | CIRAM_A10 CIRAM_A10_MCU
PPU_RD_3V3 PPU_WR_3V3 PPU_A13_3V3 | IRQ_DRV LOUT | GND | LOUT | LINE LINE | GND

PPU_A12 PPU_A13 PPU_D7 PPU_D6 PPU_D5 PPU_D4

# GND+3V3 CIRAM_A10 GND

VBUS_MOD USBD_N

USBD_P

PPU_RD_3V3 PPU_A13_3V3

EXP_AUDIO_PWM
IRQ_DRV GND

PPU_WR_3V3 CIRAM_A10_MCU

EXP_AUDIO_RC
FC_5V_SENSE
VBUS_MOD

GND

GND
GND
IRQ | Q1_B GND Q1_B

GND

SWD
GND

IRQ_DRV
FC_5V_SENSE SWCLK
GND +3V3 | Q1_B | IRQ +5V GND

IRQ +5V M2 CPU_A12 CPU_A13 CPU_A14 CPU_D7 CPU_D6 CPU_D5 CPU_D4 CPU_D3 CPU_D2 CPU_D1 CPU_D0 ROMSEL GND

PPU_A6

SOUND_IN
SOUND_OUT PPU_WR

CIRAM_CE PPU_A13 PPU_A7 PPU_A8 GND

# CPU_A11 CPU_A10 CPU_A9 CPU_A8 CPU_A7 CPU_A6 CPU_A5 CPU_A4 CPU_A3 CPU_RW

CIRAM_A10 +5V CPU_A2 CPU_A1 CPU_A0 | GND

PPU_RD

PPU_A5 PPU_A4 PPU_A3 PPU_A2 PPU_A1 PPU_A0 PPU_D0 PPU_D1 PPU_D2 PPU_D3 | +5V FC_5V_SENSE CIRAM_CE PPU_D7 PPU_D6 PPU_D5 PPU_D4 | PPU_A13 PPU_A9 PPU_A10 PPU_A11 PPU_A12 PPU_A13 | PPU_D4 PPU_D5 PPU_D7 PPU_A9 PPU_A11 PPU_WR_3V3 CIRAM_A10_MCU

CPU_A12 CPU_A7 CPU_A8 CPU_A10 ROMSEL M2 PPU_D1 PPU_D3 PPU_A10 PPU_A12 PPU_RD_3V3 PPU_A13_3V3

EXP_AUDIO_PWM

PPU_A8 GND
PPU_D6
CPU_D4 CPU_D6 CPU_A2 CPU_A4 CPU_A6 | CPU_A5 GND
CPU_D2 | CPU_D0 CPU_A3 CPU_D1 CPU_D3 CPU_D5 CPU_D7 CPU_A1 CPU_A0 GND
CPU_A9 CPU_A11 CPU_A13 | GND

GND
GND
GND

CPU_A14 CPU_RW
PPU_D0 PPU_D2 | VBUS_MOD GND +3V3 GND

PPU_RD
PPU_WR

# PPU_A13 GND +3V3 GND

PPU_D0 | M2 | ROMSEL | GND PPU A0-A7 (cart 19-25, 50) are NOT used: low address is sampled on PPU_D0-7 (=PPU AD0-7) just before /RD falls.

Cart pins 1,16,30,31,15,18,45,46,47,48,49: nesdev docs, cross-checked with fc-rom-vomitter (51 signal pins verified on real carts).

Q1 2SC1815 pin order E-C-B (flat face). R6 is DNP unless the console has no /IRQ pull-up.

R8 (mix level) and R7 (pass-through) values are to be tuned on real hardware.

Core2350B header pinout: Waveshare schematic, checked against module silk on 2026-09-26. Module USB uses its own FPC adapter.

FC-MAGICON: Waveshare Core2350B (RP2350B) Famicom cartridge - PRG/CHR emulation, NSF, screen streaming

GPIO39 has the on-board LED (470R) - keep it off the bus. GPIO47 = on-board PSRAM CS.

RP2350 erratum E9: do not enable internal pull-downs on bus pins.

Close exactly one of JP1/JP2/JP3 (CIRAM A10 source).

GPIO0-38 are 5V tolerant (IOVDD must be powered). GPIO40-47 are ADC pins: NOT 5V tolerant -> via U2 or output only.

Firmware must keep all bus pins as inputs until FC_5V_SENSE is high (USB-only power must not back-power the console).

R10

47k C4
10u (+ to SOUND_OUT)

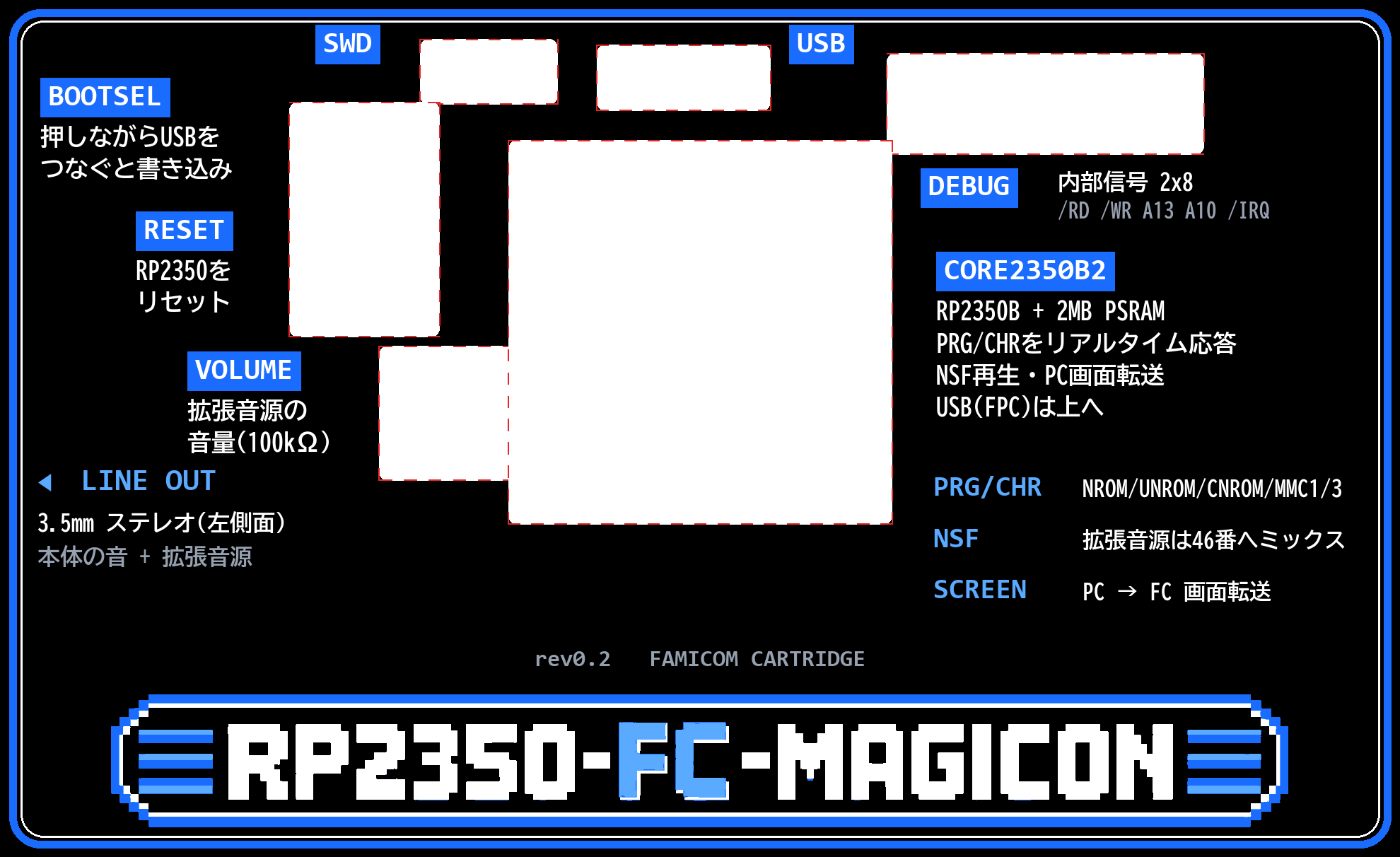
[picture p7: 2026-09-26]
case/label/label.png

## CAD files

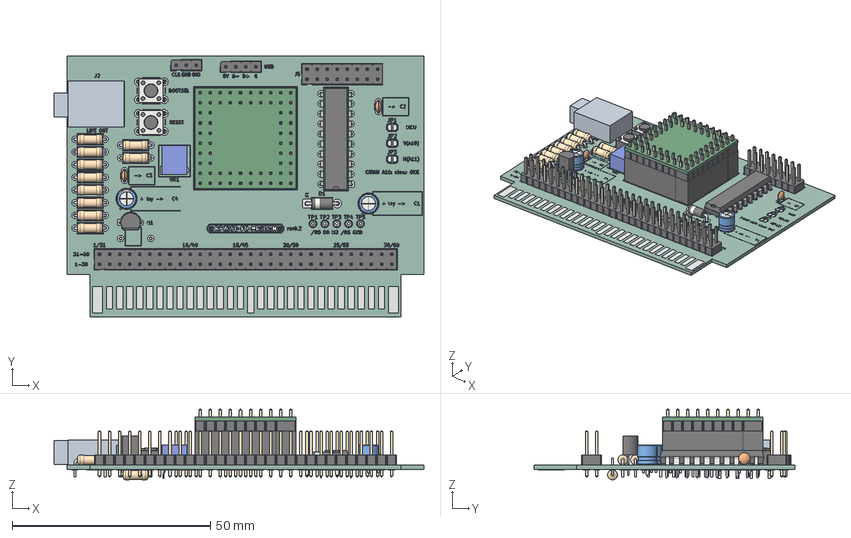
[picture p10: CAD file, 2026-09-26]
3d/FC-MAGICON_r0.2_parts.step
93.3 x 65.8 x 17.8 mm
pj-324m
SW_PUSH_6mm x 2
DIP-20_W7.62mm
CP_Radial_D50mm_P200mm x 2
R_Axial_DIN0207_L63mm_D25mm_P762mm_Horizontal x 11
PinSocket_2x08_P2.54mm_Vertical x 4
PinHeader_2x08_P254mm_Vertical x 5
C_Disc_D30mm_W16mm_P250mm x 2
koa_sf6
PinHeader_2x30_P254mm_Vertical
core2350b
TO-92_Inline_Wide
PinHeader_1x03_P254mm_Vertical
PinHeader_1x04_P254mm_Vertical
D_DO-41_SOD81_P7.62mm_Horizontal
_step_tmp_pad
_step_tmp_silkscreen x 2
_step_tmp_PCB

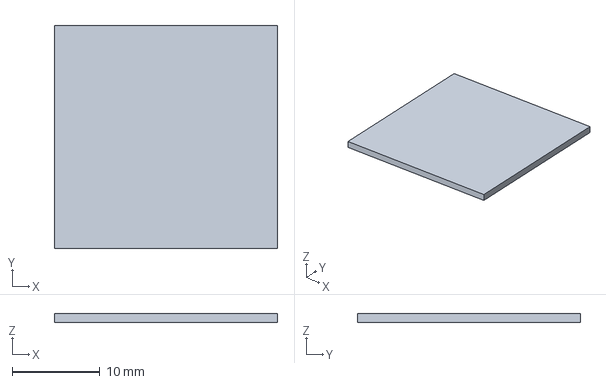
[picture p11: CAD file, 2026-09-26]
kicad/3d/core2350b_board.step
25.4 x 25.4 x 1.00 mm

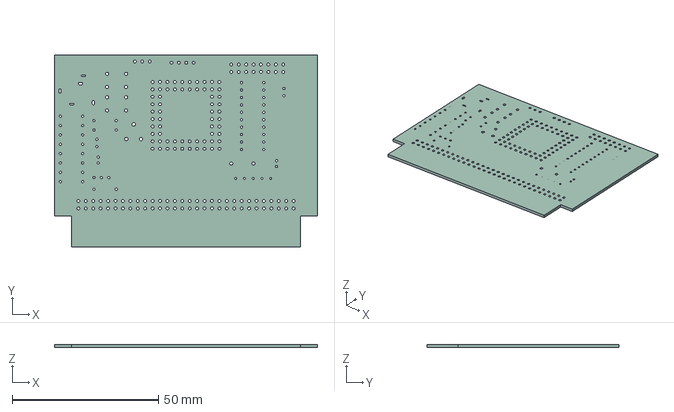
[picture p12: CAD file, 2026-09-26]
3d/FC-MAGICON_r0.2_board.step
90.0 x 65.8 x 1.11 mm

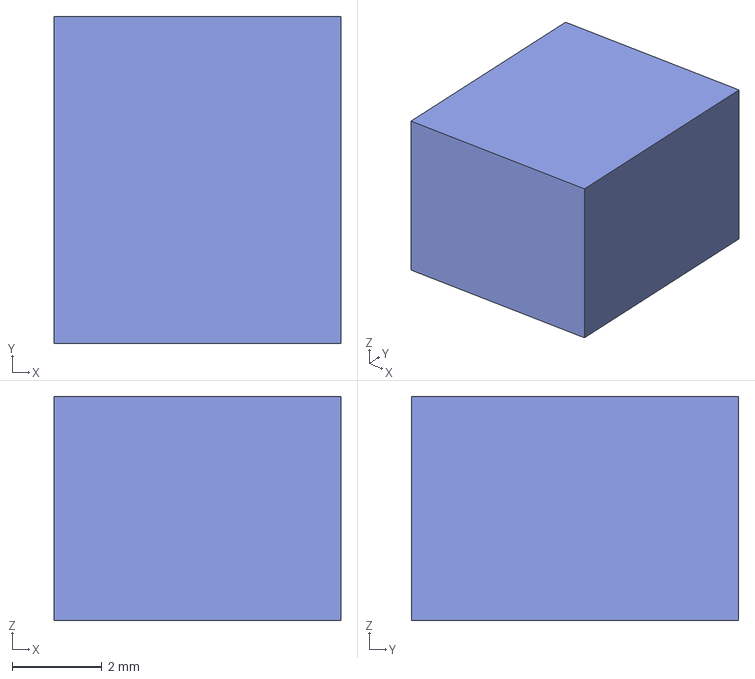
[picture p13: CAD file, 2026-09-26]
kicad/3d/koa_sf6.step
6.40 x 7.30 x 5.00 mm

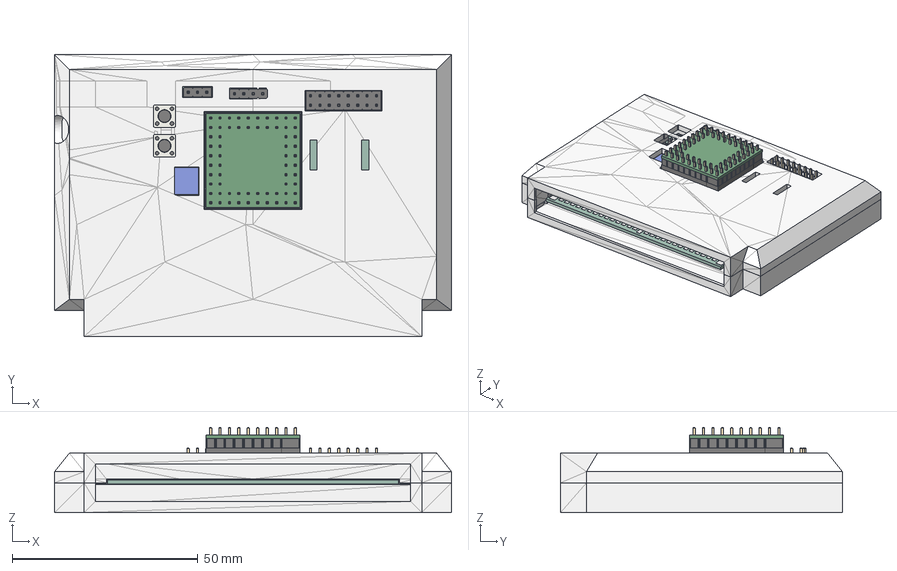
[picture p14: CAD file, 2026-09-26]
3d/FC-MAGICON.step
107.0 x 76.0 x 22.9 mm
pj-324m_1
SW_PUSH_6mm_1 x 2
DIP-20_W7.62mm_1
R_Axial_DIN0207_L63mm_D25mm_P762mm_Horizontal x 11
CP_Radial_D50mm_P200mm x 2
PinSocket_2x08_P2.54mm_Vertical_1 x 4
PinHeader_2x08_P254mm_Vertical x 5
C_Disc_D30mm_W16mm_P250mm x 2
koa_sf6_1
TO-92_Inline_Wide_1
PinHeader_1x03_P254mm_Vertical
core2350b
PinHeader_1x04_P254mm_Vertical
D_DO-41_SOD81_P7.62mm_Horizontal_1
_step_tmp_pad
_step_tmp_silkscreen
_step_tmp_silkscreen_1
_step_tmp_PCB

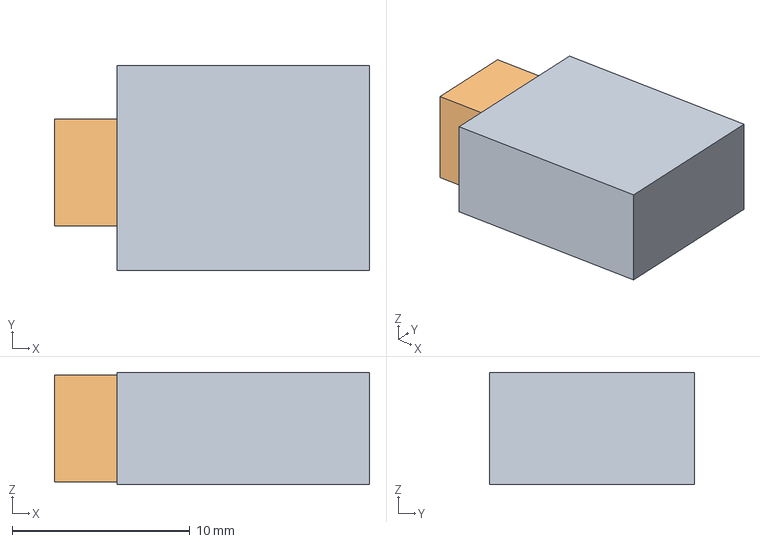
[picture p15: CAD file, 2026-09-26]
kicad/3d/pj-324m.step
17.7 x 11.5 x 6.30 mm

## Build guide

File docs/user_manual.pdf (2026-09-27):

# FC-MAGICON 使い方(手順書)

FC-MAGICON(RP2350B のファミコン用カセット)を実際に使う時の手順。2026-09-27 時点。基板は未製作・実機では未検証(PC の試験 台 sim では確かめてある)。

## 必要なもの

もの | 内容
ファミコン本体 | HVC-CPU-07(動くもの)。拡張端子はキーボードを使う時だけ
FC-MAGICON 基板 rev0.2 | 部品を付けたもの。R1 は裏面、Q1 は下へ倒して付ける
Waveshare Core2350B2 | 基板のソケットに挿す。付属の FPC-USB アダプターと FPC ケーブル
PC | Windows 11、Python 3(Pillow・numpy)、picotool(C:\Users\Yugo\pico)
1コン | 本体付属。リモートデスクトップではマウスの代わり
ファミリーベーシックのキーボード | HVC-007。リモートデスクトップで文字を打つ時だけ(無くても動く)

## 安全のための決まり

ファミコンの電源を切ってから カセットを抜き差しする。
USB だけつないで本体の電源が切れている時、カセットはバスに何も出さない(本体の 5V を GPIO46 で見て、来るまで待つ)。USB をつないだまま本体の電源を入れてよい。
ミラーリングのジャンパー JP1・JP2・JP3 は1つだけ 閉じる。2つ以上閉じると信号どうしがぶつかる。
Core2350B2 はソケットの向きを確かめてから挿す(基板のシルク「Core2350B」と FPC の位置に合わせる)。

## はじめて使う前の準備

### ミラーリングのジャンパー

JP1(MCU)を推奨。ゲームごとのミラーリングをファームウェアが切り替える(MMC1・MMC3・AxROM で必要)。 未検証: CIRAM A10 を RP2350 の 3.3V で動かして問題ないか。画面の上下左右がつながっておかしい時は、JP1 をはがして JP2 か JP3 にする(その場合ミラーリング は固定)。

閉じる所 | ミラーリング | 向いているもの
JP1(MCU) | ファームウェアが切り替える | すべて(推奨)
JP2(V = A10) | 垂直に固定 | 横スクロールのゲーム(マリオなど)
JP3(H = A11) | 水平に固定 | 縦スクロールのゲーム

### ファームウェアを書く

1. Core2350B2 を FPC-USB アダプター経由で PC につなぐ(ファミコンには挿さなくてよい)。
2. 基板の BOOTSEL を押したまま RESET を押して離す → PC に「RP2350」ドライブが出る。
3. FC-MAGICON\firmware\out\ の .uf2 をそのドライブにコピーする。自動で再起動する。
ファイル | 使う時
usb_test.uf2 | USB の速さを測る(ファミコン無しで。tools/usb_bench.py と使う)
bus_test.uf2 | 最初の動作確認 1(CPU バス)
chr_test.uf2 | 最初の動作確認 2(PPU の読み取り)
magicon.uf2 | ふだん使う(ゲーム・NSF・リモートデスクトップ)

ファイル | 使う時
magicon_wifi.uf2 | リモートデスクトップを Wi-Fi(J6 の ESP32-C6)で使う時

### 最初の動作確認(基板を作って最初の 1 回)

1. モジュールを載せる前に、テスターで +5V(J4 の 30/60 列)と GND の間がショートしていないか確かめる。
2. bus_test.uf2 を書き、USB だけつなぐ → LED が速く点滅し、USB シリアルに waiting for Famicom 5V と出れば正常。
3. 電源を切ったファミコンに挿して電源を入れる → ピーという音が鳴り、LED が約 0.5 秒ごとに点滅すれば、CPU バスの読み書きが動 いている。鳴らない時はリセットボタンを押す。
4. chr_test.uf2 を書いて同じように挿す → 4色の縦縞と、8 ドットごとの白い格子が出れば、PPU の読み取り(アドレス下位を AD0-7 から読む方式)が成り立っている。模様が崩れる時は、TP1(/RD)と TP2(PPU D0)をオシロで見る。
5. magicon.uf2 を書く。以後はこれを使う。

## ゲームを遊ぶ

1. Core2350B2 を USB で PC につないだまま(本体の電源は切っても入れてもよい)、PowerShell で実行する: pwsh -File
C:\Users\Yugo\OneDrive\ドキュメント\Claude\FC-MAGICON\firmware\load_rom.ps1 ゲーム.nes 。 マッパー・大きさを表
示し、動くものならフラッシュに書く(magicon が動いていれば、BOOTSEL を押さなくても自動で書き込みモードになる)。
2. ファミコンの電源を入れ直す(またはリセット)。書いた ROM で起動する。
3. ROM はファームウェアを書き直しても消えない。別の ROM を書くまで同じものが起動する。

対応しているマッパー(PRG + CHR の合計 384KB まで):

番号 | マッパー | 特徴
0 | NROM | バンク切り替え無し
1 | MMC1 | CHR-RAM も可。ミラーリング切り替え(JP1)
2 | UxROM | CHR-RAM
3 | CNROM | CHR 8KB 切り替え
4 | MMC3 | スキャンライン割り込み(/IRQ)。ミラーリング切り替え(JP1)
7 | AxROM | 1 画面ミラー(JP1)
87 | Jaleco J87 | $6000-$7FFF の書き込みで CHR 切り替え
184 | Sunsoft-1 | $6000-$7FFF の書き込みで CHR 4KB × 2

バッテリーバックアップのセーブ(WRAM)は、電源を切ると消える(フラッシュへの保存はまだ)。 対応していない ROM を書こうとすると、load_rom.ps1 がその場で止まる(フラッシュは書き換えない)。 ROM が入っていない・壊れている時は、chr_test と同じ試験画面になる。理由は USB シリアルに出る。

## ゲーム選択メニュー(何本も入れておく)

1. ROM をまとめて書く(フォルダーなら中の .nes / .nsf を全部。動かないものは理由を出して飛ばす): pwsh -File
C:\Users\Yugo\OneDrive\ドキュメント\Claude\FC-MAGICON\firmware\load_rom.ps1 -Library フォルダー
2. ファミコンの電源を入れると、メニューが出る。
1コン | 動作
↑ / ↓ | 選ぶ(押し続けると続けて動く)
← / → | 20 項目ずつ前 / 次へ
A / START | 始める(1.5 秒後にゲームが始まる)

メニューに戻る時は、ファミコンの電源を入れ直す。リセットボタンは、今のゲームの最初に戻るだけ。

題名はファイル名を大文字にしたもの。変えたい時は、ROM と同じフォルダーに titles.txt を作り mario3.nes=SUPER MARIO BROS 3 のように書く(英数字と記号、28 文字まで表示)。
-Remote を付けると、画面転送(リモートデスクトップ)も項目に入る。NSF も入れられる。
入るのは 8MB・127 本まで。1 本だけ書く今までのやり方(load_rom.ps1 game.nes)も使える。

## NSF(音楽)を聴く

1. ゲームと同じく load_rom.ps1 曲.nsf で書き、ファミコンの電源を入れ直す。
2. 曲名・作者・「SONG 01 / 12」の画面が出て、最初の曲が鳴る。
1コン | 動作
← / → | 前の曲 / 次の曲
A | 今の曲を最初から
START | 一時停止 / 再開

拡張音源(VRC6・FDS・N163 など)はまだ鳴らない。本体の音源(2A03)の分だけ鳴る。 再生の間隔が標準(約 60Hz)と違う NSF は、テンポが変わる。

## リモートデスクトップ(PC の画面をファミコンに映す)

### 始め方

1. カセットを画面転送モードにする(1 回だけ。別の ROM を書くまで続く): pwsh -File C:\Users\Yugo\OneDrive\ドキュメント
\Claude\FC-MAGICON\firmware\load_rom.ps1 -Remote
2. キーボードを使うなら、ファミコンの電源を切った状態で 拡張端子にファミリーベーシックのキーボードを挿す。
3. ファミコンの電源を入れる → 「FC-MAGICON REMOTE / WAITING FOR PC...」と出る。
4. Core2350B2 を USB で PC につないだまま、PC 側のアプリを起動する: python C:\Users\Yugo\OneDrive\ドキュメント
\Claude\FC-MAGICON\firmware\tools\remote_pc.py 。 PC の画面がファミコンに映る。止める時は、アプリを動かしている画面
で Ctrl+C(押しっぱなしのキーとボタンは離してから止まる)。
オプション | 内容
(なし) | 灰色 4 階調。文字がいちばん読みやすい
--color | カラー(16 x 16 ドットごとに 4 色、ディザあり)
--port COM5 | COM ポートを指定する(自動で見つからない時)
--fps 30 | 送る速さの上限(既定 30)
--dry-run 30 | カセット無しで、画面の取り込みと変換の速さだけ測る
--no-audio | PC の音を送らない(既定では送る)
--audio pcm16 | 音の形式。既定は USB 直結 pcm16、Wi-Fi pcm8(画面の枚数を優先)。adpcm は軽いが雑音が多い
--volume 0.5 | 送る音の大きさ(1.0 = そのまま)
--tcp | Wi-Fi ブリッジ(ESP32-C6)経由でつなぐ(既定 25 枚/秒)。カセットは magicon_wifi.uf2 にする(下の「Wi-Fi で送る」)

### PC の音

PC で鳴っている音(既定の再生デバイス)が、ファミコンの音(テレビ)に混ざって鳴る。基板の 3.5mm ジャック(J2)からも出る。

音量は PC の音量と、基板の VR1 で合わせる。大き過ぎる時は --volume 0.5 など。
画面より 0.1 秒くらい遅れて聞こえる(途切れないように溜めてから鳴らすため)。 ファミコンにつないでの確認はまだ(Core2350B2 単体で、GPIO44 にイヤホンをつないで鳴ることは確認済み)。

### 操作(1コン)

1コン | PC 側
十字キー | マウスを動かす(押し続けると速くなる)
A / B | 左クリック / 右クリック
SELECT | 表示の切り替え: 画面全体を縮小 ⇔ カーソルのまわりを等倍(等倍は文字が読める)
START | 等倍の時、表示がカーソルを追うか・止めるか

### 操作(ファミリーベーシックのキーボード)

前に作った拡張端子 ⇔ USB 変換器(Famicom-Expand-USB-Adapter)と同じ割り当て。

SHIFT・GRPH(Alt)・CTR はトグル: 1 回押すと ON、もう 1 回で OFF。RETURN を押すと SHIFT は自動で OFF になる。 記号は日本語(JIS)配列の位置で送る。Windows のキーボード設定が日本語配列であること。
カナキーは IME の切り替え(半角/全角)。

英字・数字(A〜Z、0〜9)は刻印どおり。それ以外:

ファミコンのキー | PC で押されるキー | ファミコンのキー | PC で押されるキー
F1 | F1 | ↓ | ↓
F2 | F2 | ESC | Esc
F3 | F3 | GRPH | Alt(トグル)
F4 | F4 | INS | Insert
F5 | F5 | カナ | 半角/全角
F6 | F6 | ← | ←
F7 | F7 | SHIFT(左) | Shift(トグル)
F8 | F8 | RETURN | Enter
, | , | → | →
- | - | SHIFT(右) | Shift(トグル)
. | . | SPACE | Space
/ | / | STOP | BackSpace
: | : | ↑ | ↑
; | ; | ¥ | ¥
@ | @ | [ | [
CLR HOME | Home | ] | ]
CTR | Ctrl(トグル) | ^ | ^
DEL | BackSpace | _ | ろ(バックスラッシュ)

### 速さの目安(この PC、2026-09-27)

表示 | 灰色 | カラー
カーソルのまわりを等倍 | 約 60 枚/秒 | 約 60 枚/秒
画面全体を縮小 | 約 30 枚/秒 | 約 23 枚/秒

PC 側の取り込みと変換だけの値。USB 直結は 614KB/秒(最大 40.6 枚/秒)出るので、画面を作る PC 側の速さで決まる (Core2350B2 単体で測定。remote_pc.py を流して 灰色 29.8 枚/秒、カラー 20.0 枚/秒)。

### Wi-Fi で送る(ESP32-C6)

カセットのファームウェアを magicon_wifi.uf2 にすると、USB がホストになり、J6 につないだ C6 から画面を受け取る。ファミコンにつないでの 確認はまだ(基板が届いてから)。

1. C6 に Wi-Fi の設定を書く: firmware\wifi_bridge\wifi_secrets.example.h を写して wifi_secrets.h にし、SSID とパスワー
ドを書く(2.4GHz)。
2. C6 を PC につないで書き込む: pwsh -File C:\Users\Yugo\OneDrive\ドキュメント\Claude\FC-MAGICON\firmware\wifi_bridge\build_bridge.ps1
3. カセットを画面転送モードにしておく(load_rom.ps1 -Remote。magicon.uf2 の時に)。
4. カセットに magicon_wifi.uf2 を書く(BOOTSEL を押したまま RESET を押して離し、出てきたドライブに
firmware\out\magicon_wifi.uf2 をコピー)。
5. FPC-USB アダプターを外し、C6 と J6 を 3 本でつなぐ: J6 の 2 番(D-)→ C6 の GPIO12、3 番(D+)→ GPIO13、4 番 → GND。C6 の電源は別の USB(C6 の UART の USB-C を AC アダプターなど)から取る。
6. ファミコンの電源を入れ、PC で python C:\Users\Yugo\OneDrive\ドキュメント\Claude\FC-MAGICON\firmware\tools\remote_pc.py --tcp
magicon_wifi の時は、load_rom.ps1 の自動書き込みモードも USB シリアルの表示も無い。ROM を書き換える・PC 直結に戻す 時は、BOOTSEL + RESET で書き込みモードにしてから(PC 直結に戻すなら magicon.uf2 を書く)。
C6 が動かない・Wi-Fi につながらない時は、C6 の USB を挿し直す(電源が弱いボードで、ブラウンアウトでリセットを繰り返すことがあ る)。
項目 | 値(2026-09-27)
Wi-Fi → C6 → RP2350(USB ホスト、host_test) | 420KB/秒 = 最大 27.8 枚/秒、500 枚すべて届く
Wi-Fi → C6 → PC(C6 だけ) | 462KB/秒 = 30.6 枚/秒。25 枚/秒で送ると遅れ 中央 37ms・最大 81ms
magicon_wifi | Wi-Fi から送った 1 枚が裏画面にそのまま入る(Core2350B2 単体、ファミコン無し)

## 困ったとき

症状 | 見る所・やること
画面が出ない・音が鳴らない | 本体のリセットを押す(カセットの起動が本体に間に合わなかった可能性)。USB シリアルに理由が出ていないか 見る
waiting for Famicom 5V のまま | 本体の電源が入っていない、またはカセットが奥まで挿さっていない
画面の上下・左右のつながりがおかし い | ジャンパー(JP1〜3)を見直す。JP1 で駄目なら JP2 / JP3
load_rom.ps1 が書き込めない | BOOTSEL を押したまま RESET を押して離してから、もう一度実行する
COM ポートが見つからない | USB ケーブル・FPC の向きを確認。--port COMx で指定する
キーが押しっぱなしになった | アプリを Ctrl+C で止める(全部離す)。USB が 0.5 秒途切れた時も自動で離す
記号キーがずれる | Windows のキーボードが日本語配列になっているか確認する
キーボードの文字が抜ける・二重になる | 拡張端子の挿し込みを確認。読み取りの待ち時間は 500us(gen_remote_driver.py の KB_WAIT_US)

## 確認状況

項目 | 状況
マッパーの動作(0/1/2/3/4/7/87/184) | PC の試験台で確認済み(手元の ROM 12 本。0/1/2/4 はエミュレーター純正と全フレーム一致)
NSF プレイヤー(バンク切り替え・操作) | PC の試験台と 6502 エミュレーターで確認済み
画面転送(絵・カーソル・パッド・キーボード) | PC の試験台で確認済み(送った絵とドット単位で一致)
キーボードの割り当て・トグル・チャタリング対策 | test_keyboard_bridge.py で確認済み。割り当ては変換器で実機確認済みのもの
PIO の応答タイミング(CPU・PPU) | 未検証(基板が届いてから bus_test / chr_test で)

項目 | 状況
CIRAM A10 を 3.3V で動かす(JP1) | 未検証。駄目なら JP2 / JP3
USB の転送速度(画面転送の枚数/秒) | Core2350B2 単体で確認済み(614KB/秒 = 最大 40.6 枚/秒、usb_test + usb_bench.py)
ROM の書き込み(load_rom.ps1、自動で書き込み モード) | Core2350B2 単体で確認済み(mario3 384KB、-Remote)
Wi-Fi(ESP32-C6)→ USB の転送 | PC 相手・RP2350(USB ホスト)相手で確認済み(27.8 枚/秒、500 枚すべて届く)
magicon_wifi(Wi-Fi の画面転送) | Core2350B2 単体で 1 枚目が裏画面に入るまで確認。ファミコンでは未検証
ゲーム選択メニュー | PC の試験台で確認済み(37 項目、ページ送り、選んでゲーム・NSF・画面転送が始まる)。実機 では未検証
PC の音(画面転送モード) | Core2350B2 単体 + Wi-Fi で、GPIO44 のイヤホンで鳴ることを確認。ファミコンの音声に混ぜ ては未検証
バッテリーバックアップ、NSF の拡張音源 | 未実装

## 関係するファイル

ファイル | 内容
firmware/out/*.uf2 | ファームウェア(bus_test・chr_test・magicon)
firmware/load_rom.ps1 | ROM / NSF / 画面転送モードをカセットに書く
firmware/tools/remote_pc.py | リモートデスクトップの PC 側アプリ
firmware/wifi_bridge/ | Wi-Fi ブリッジ(ESP32-C6)のファームウェアと書き込みスクリプト
firmware/tools/wifi_bench.py | Wi-Fi ブリッジの速さを測る
firmware/README.md | ファームウェアの詳しい説明
docs/hardware_spec.pdf | 基板の仕様書(ピン・部品・ジャンパー)
docs/build_manual.py | この手順書を作るスクリプト(表は nes_pack.py・remote_pc.py から作る)

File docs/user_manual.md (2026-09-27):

# FC-MAGICON 使い方(手順書)

FC-MAGICON(RP2350B のファミコン用カセット)を実際に使う時の手順。2026-09-27 時点。**基板は未製作・実機では未検証**(PC の試験台 sim では確かめてある)。

## 必要なもの

| もの | 内容 |
|---|---|
| ファミコン本体 | HVC-CPU-07(動くもの)。拡張端子はキーボードを使う時だけ |
| FC-MAGICON 基板 rev0.2 | 部品を付けたもの。R1 は裏面、Q1 は下へ倒して付ける |
| Waveshare Core2350B2 | 基板のソケットに挿す。付属の FPC-USB アダプターと FPC ケーブル |
| PC | Windows 11、Python 3(Pillow・numpy)、picotool(`C:\Users\Yugo\pico`) |
| 1コン | 本体付属。リモートデスクトップではマウスの代わり |
| ファミリーベーシックのキーボード | HVC-007。リモートデスクトップで文字を打つ時だけ(無くても動く) |

## 安全のための決まり

- **ファミコンの電源を切ってから** カセットを抜き差しする。
- USB だけつないで本体の電源が切れている時、カセットはバスに何も出さない(本体の 5V を GPIO46 で見て、来るまで待つ)。USB をつないだまま本体の電源を入れてよい。
- ミラーリングのジャンパー **JP1・JP2・JP3 は1つだけ** 閉じる。2つ以上閉じると信号どうしがぶつかる。
- Core2350B2 はソケットの向きを確かめてから挿す(基板のシルク「Core2350B」と FPC の位置に合わせる)。

## はじめて使う前の準備

### ミラーリングのジャンパー

**JP1(MCU)を推奨**。ゲームごとのミラーリングをファームウェアが切り替える(MMC1・MMC3・AxROM で必要)。
**未検証**: CIRAM A10 を RP2350 の 3.3V で動かして問題ないか。画面の上下左右がつながっておかしい時は、JP1 をはがして JP2 か JP3 にする(その場合ミラーリングは固定)。

| 閉じる所 | ミラーリング | 向いているもの |
|---|---|---|
| JP1(MCU) | ファームウェアが切り替える | すべて(推奨) |
| JP2(V = A10) | 垂直に固定 | 横スクロールのゲーム(マリオなど) |
| JP3(H = A11) | 水平に固定 | 縦スクロールのゲーム |

### ファームウェアを書く

1. Core2350B2 を FPC-USB アダプター経由で PC につなぐ(ファミコンには挿さなくてよい)。
2. 基板の **BOOTSEL を押したまま RESET を押して離す** → PC に「RP2350」ドライブが出る。
3. `FC-MAGICON\firmware\out\` の `.uf2` をそのドライブにコピーする。自動で再起動する。

| ファイル | 使う時 |
|---|---|
| `usb_test.uf2` | USB の速さを測る(ファミコン無しで。`tools/usb_bench.py` と使う) |
| `bus_test.uf2` | 最初の動作確認 1(CPU バス) |
| `chr_test.uf2` | 最初の動作確認 2(PPU の読み取り) |
| `magicon.uf2` | ふだん使う(ゲーム・NSF・リモートデスクトップ) |
| `magicon_wifi.uf2` | リモートデスクトップを Wi-Fi(J6 の ESP32-C6)で使う時 |

### 最初の動作確認(基板を作って最初の 1 回)

1. **モジュールを載せる前に**、テスターで +5V(J4 の 30/60 列)と GND の間がショートしていないか確かめる。
2. `bus_test.uf2` を書き、USB だけつなぐ → LED が速く点滅し、USB シリアルに `waiting for Famicom 5V` と出れば正常。
3. 電源を切ったファミコンに挿して電源を入れる → **ピーという音**が鳴り、LED が約 0.5 秒ごとに点滅すれば、CPU バスの読み書きが動いている。鳴らない時はリセットボタンを押す。
4. `chr_test.uf2` を書いて同じように挿す → **4色の縦縞と、8 ドットごとの白い格子**が出れば、PPU の読み取り(アドレス下位を AD0-7 から読む方式)が成り立っている。模様が崩れる時は、TP1(/RD)と TP2(PPU D0)をオシロで見る。
5. `magicon.uf2` を書く。以後はこれを使う。

## ゲームを遊ぶ

1. Core2350B2 を USB で PC につないだまま(本体の電源は切っても入れてもよい)、PowerShell で実行する:
   `pwsh -File C:\Users\Yugo\OneDrive\ドキュメント\Claude\FC-MAGICON\firmware\load_rom.ps1 ゲーム.nes` 。
   マッパー・大きさを表示し、動くものならフラッシュに書く(magicon が動いていれば、BOOTSEL を押さなくても自動で書き込みモードになる)。
2. ファミコンの電源を入れ直す(またはリセット)。書いた ROM で起動する。
3. ROM はファームウェアを書き直しても消えない。別の ROM を書くまで同じものが起動する。

対応しているマッパー(PRG + CHR の合計 384KB まで):

| 番号 | マッパー | 特徴 |
|---|---|---|
| 0 | NROM | バンク切り替え無し |
| 1 | MMC1 | CHR-RAM も可。ミラーリング切り替え(JP1) |
| 2 | UxROM | CHR-RAM |
| 3 | CNROM | CHR 8KB 切り替え |
| 4 | MMC3 | スキャンライン割り込み(/IRQ)。ミラーリング切り替え(JP1) |
| 7 | AxROM | 1 画面ミラー(JP1) |
| 87 | Jaleco J87 | $6000-$7FFF の書き込みで CHR 切り替え |
| 184 | Sunsoft-1 | $6000-$7FFF の書き込みで CHR 4KB × 2 |

- バッテリーバックアップのセーブ(WRAM)は、**電源を切ると消える**(フラッシュへの保存はまだ)。
- 対応していない ROM を書こうとすると、`load_rom.ps1` がその場で止まる(フラッシュは書き換えない)。
- ROM が入っていない・壊れている時は、chr_test と同じ試験画面になる。理由は USB シリアルに出る。

## ゲーム選択メニュー(何本も入れておく)

1. ROM をまとめて書く(フォルダーなら中の .nes / .nsf を全部。動かないものは理由を出して飛ばす):
   `pwsh -File C:\Users\Yugo\OneDrive\ドキュメント\Claude\FC-MAGICON\firmware\load_rom.ps1 -Library フォルダー`
2. ファミコンの電源を入れると、メニューが出る。

| 1コン | 動作 |
|---|---|
| ↑ / ↓ | 選ぶ(押し続けると続けて動く) |
| ← / → | 20 項目ずつ前 / 次へ |
| A / START | 始める(1.5 秒後にゲームが始まる) |

- **メニューに戻る時は、ファミコンの電源を入れ直す**。リセットボタンは、今のゲームの最初に戻るだけ。
- 題名はファイル名を大文字にしたもの。変えたい時は、ROM と同じフォルダーに `titles.txt` を作り `mario3.nes=SUPER MARIO BROS 3` のように書く(英数字と記号、28 文字まで表示)。
- `-Remote` を付けると、画面転送(リモートデスクトップ)も項目に入る。NSF も入れられる。
- 入るのは 8MB・127 本まで。1 本だけ書く今までのやり方(`load_rom.ps1 game.nes`)も使える。

## NSF(音楽)を聴く

1. ゲームと同じく `load_rom.ps1 曲.nsf` で書き、ファミコンの電源を入れ直す。
2. 曲名・作者・「SONG 01 / 12」の画面が出て、最初の曲が鳴る。

| 1コン | 動作 |
|---|---|
| ← / → | 前の曲 / 次の曲 |
| A | 今の曲を最初から |
| START | 一時停止 / 再開 |

- **拡張音源(VRC6・FDS・N163 など)はまだ鳴らない**。本体の音源(2A03)の分だけ鳴る。
- 再生の間隔が標準(約 60Hz)と違う NSF は、テンポが変わる。

## リモートデスクトップ(PC の画面をファミコンに映す)

### 始め方

1. カセットを画面転送モードにする(1 回だけ。別の ROM を書くまで続く):
   `pwsh -File C:\Users\Yugo\OneDrive\ドキュメント\Claude\FC-MAGICON\firmware\load_rom.ps1 -Remote`
2. キーボードを使うなら、**ファミコンの電源を切った状態で** 拡張端子にファミリーベーシックのキーボードを挿す。
3. ファミコンの電源を入れる → 「FC-MAGICON REMOTE / WAITING FOR PC...」と出る。
4. Core2350B2 を USB で PC につないだまま、PC 側のアプリを起動する:
   `python C:\Users\Yugo\OneDrive\ドキュメント\Claude\FC-MAGICON\firmware\tools\remote_pc.py` 。
   PC の画面がファミコンに映る。止める時は、アプリを動かしている画面で **Ctrl+C**(押しっぱなしのキーとボタンは離してから止まる)。

| オプション | 内容 |
|---|---|
| (なし) | 灰色 4 階調。文字がいちばん読みやすい |
| `--color` | カラー(16 x 16 ドットごとに 4 色、ディザあり) |
| `--port COM5` | COM ポートを指定する(自動で見つからない時) |
| `--fps 30` | 送る速さの上限(既定 30) |
| `--dry-run 30` | カセット無しで、画面の取り込みと変換の速さだけ測る |
| `--no-audio` | PC の音を送らない(既定では送る) |
| `--audio pcm16` | 音の形式。既定は USB 直結 `pcm16`、Wi-Fi `pcm8`(画面の枚数を優先)。`adpcm` は軽いが雑音が多い |
| `--volume 0.5` | 送る音の大きさ(1.0 = そのまま) |
| `--tcp` | Wi-Fi ブリッジ(ESP32-C6)経由でつなぐ(既定 25 枚/秒)。カセットは `magicon_wifi.uf2` にする(下の「Wi-Fi で送る」) |

### PC の音

PC で鳴っている音(既定の再生デバイス)が、ファミコンの音(テレビ)に混ざって鳴る。基板の 3.5mm ジャック(J2)からも出る。

- 音量は PC の音量と、基板の VR1 で合わせる。大き過ぎる時は `--volume 0.5` など。
- 画面より 0.1 秒くらい遅れて聞こえる(途切れないように溜めてから鳴らすため)。
- **ファミコンにつないでの確認はまだ**(Core2350B2 単体で、GPIO44 にイヤホンをつないで鳴ることは確認済み)。

### 操作(1コン)

| 1コン | PC 側 |
|---|---|
| 十字キー | マウスを動かす(押し続けると速くなる) |
| A / B | 左クリック / 右クリック |
| SELECT | 表示の切り替え: 画面全体を縮小 ⇔ カーソルのまわりを等倍(等倍は文字が読める) |
| START | 等倍の時、表示がカーソルを追うか・止めるか |

### 操作(ファミリーベーシックのキーボード)

前に作った拡張端子 ⇔ USB 変換器(Famicom-Expand-USB-Adapter)と同じ割り当て。

- **SHIFT・GRPH(Alt)・CTR はトグル**: 1 回押すと ON、もう 1 回で OFF。RETURN を押すと SHIFT は自動で OFF になる。
- 記号は日本語(JIS)配列の位置で送る。Windows のキーボード設定が日本語配列であること。
- カナキーは IME の切り替え(半角/全角)。

英字・数字(A〜Z、0〜9)は刻印どおり。それ以外:

| ファミコンのキー | PC で押されるキー | ファミコンのキー | PC で押されるキー |
|---|---|---|---|
| F1 | F1 | ↓ | ↓ |
| F2 | F2 | ESC | Esc |
| F3 | F3 | GRPH | Alt(トグル) |
| F4 | F4 | INS | Insert |
| F5 | F5 | カナ | 半角/全角 |
| F6 | F6 | ← | ← |
| F7 | F7 | SHIFT(左) | Shift(トグル) |
| F8 | F8 | RETURN | Enter |
| , | , | → | → |
| - | - | SHIFT(右) | Shift(トグル) |
| . | . | SPACE | Space |
| / | / | STOP | BackSpace |
| : | : | ↑ | ↑ |
| ; | ; | ¥ | ¥ |
| @ | @ | [ | [ |
| CLR HOME | Home | ] | ] |
| CTR | Ctrl(トグル) | ^ | ^ |
| DEL | BackSpace | _ | ろ(バックスラッシュ) |

### 速さの目安(この PC、2026-09-27)

| 表示 | 灰色 | カラー |
|---|---|---|
| カーソルのまわりを等倍 | 約 60 枚/秒 | 約 60 枚/秒 |
| 画面全体を縮小 | 約 30 枚/秒 | 約 23 枚/秒 |

PC 側の取り込みと変換だけの値。USB 直結は 614KB/秒(最大 40.6 枚/秒)出るので、画面を作る PC 側の速さで決まる
(Core2350B2 単体で測定。`remote_pc.py` を流して 灰色 29.8 枚/秒、カラー 20.0 枚/秒)。

### Wi-Fi で送る(ESP32-C6)

カセットのファームウェアを **`magicon_wifi.uf2`** にすると、USB がホストになり、J6 につないだ C6 から画面を受け取る。**ファミコンにつないでの確認はまだ**(基板が届いてから)。

1. C6 に Wi-Fi の設定を書く: `firmware\wifi_bridge\wifi_secrets.example.h` を写して `wifi_secrets.h` にし、SSID とパスワードを書く(2.4GHz)。
2. C6 を PC につないで書き込む: `pwsh -File C:\Users\Yugo\OneDrive\ドキュメント\Claude\FC-MAGICON\firmware\wifi_bridge\build_bridge.ps1`
3. カセットを画面転送モードにしておく(`load_rom.ps1 -Remote`。`magicon.uf2` の時に)。
4. カセットに `magicon_wifi.uf2` を書く(BOOTSEL を押したまま RESET を押して離し、出てきたドライブに `firmware\out\magicon_wifi.uf2` をコピー)。
5. FPC-USB アダプターを外し、C6 と J6 を 3 本でつなぐ: J6 の 2 番(D-)→ C6 の GPIO12、3 番(D+)→ GPIO13、4 番 → GND。C6 の電源は別の USB(C6 の UART の USB-C を AC アダプターなど)から取る。
6. ファミコンの電源を入れ、PC で `python C:\Users\Yugo\OneDrive\ドキュメント\Claude\FC-MAGICON\firmware\tools\remote_pc.py --tcp`

- `magicon_wifi` の時は、`load_rom.ps1` の自動書き込みモードも USB シリアルの表示も無い。ROM を書き換える・PC 直結に戻す時は、BOOTSEL + RESET で書き込みモードにしてから(PC 直結に戻すなら `magicon.uf2` を書く)。
- C6 が動かない・Wi-Fi につながらない時は、C6 の USB を挿し直す(電源が弱いボードで、ブラウンアウトでリセットを繰り返すことがある)。

| 項目 | 値(2026-09-27) |
|---|---|
| Wi-Fi → C6 → RP2350(USB ホスト、`host_test`) | 420KB/秒 = 最大 27.8 枚/秒、500 枚すべて届く |
| Wi-Fi → C6 → PC(C6 だけ) | 462KB/秒 = 30.6 枚/秒。25 枚/秒で送ると遅れ 中央 37ms・最大 81ms |
| `magicon_wifi` | Wi-Fi から送った 1 枚が裏画面にそのまま入る(Core2350B2 単体、ファミコン無し) |

## 困ったとき

| 症状 | 見る所・やること |
|---|---|
| 画面が出ない・音が鳴らない | 本体のリセットを押す(カセットの起動が本体に間に合わなかった可能性)。USB シリアルに理由が出ていないか見る |
| `waiting for Famicom 5V` のまま | 本体の電源が入っていない、またはカセットが奥まで挿さっていない |
| 画面の上下・左右のつながりがおかしい | ジャンパー(JP1〜3)を見直す。JP1 で駄目なら JP2 / JP3 |
| `load_rom.ps1` が書き込めない | BOOTSEL を押したまま RESET を押して離してから、もう一度実行する |
| `COM ポートが見つからない` | USB ケーブル・FPC の向きを確認。`--port COMx` で指定する |
| キーが押しっぱなしになった | アプリを Ctrl+C で止める(全部離す)。USB が 0.5 秒途切れた時も自動で離す |
| 記号キーがずれる | Windows のキーボードが日本語配列になっているか確認する |
| キーボードの文字が抜ける・二重になる | 拡張端子の挿し込みを確認。読み取りの待ち時間は 500us(`gen_remote_driver.py` の KB_WAIT_US) |

## 確認状況

| 項目 | 状況 |
|---|---|
| マッパーの動作(0/1/2/3/4/7/87/184) | PC の試験台で確認済み(手元の ROM 12 本。0/1/2/4 はエミュレーター純正と全フレーム一致) |
| NSF プレイヤー(バンク切り替え・操作) | PC の試験台と 6502 エミュレーターで確認済み |
| 画面転送(絵・カーソル・パッド・キーボード) | PC の試験台で確認済み(送った絵とドット単位で一致) |
| キーボードの割り当て・トグル・チャタリング対策 | `test_keyboard_bridge.py` で確認済み。割り当ては変換器で実機確認済みのもの |
| PIO の応答タイミング(CPU・PPU) | **未検証**(基板が届いてから bus_test / chr_test で) |
| CIRAM A10 を 3.3V で動かす(JP1) | **未検証**。駄目なら JP2 / JP3 |
| USB の転送速度(画面転送の枚数/秒) | Core2350B2 単体で確認済み(614KB/秒 = 最大 40.6 枚/秒、`usb_test` + `usb_bench.py`) |
| ROM の書き込み(`load_rom.ps1`、自動で書き込みモード) | Core2350B2 単体で確認済み(mario3 384KB、`-Remote`) |
| Wi-Fi(ESP32-C6)→ USB の転送 | PC 相手・RP2350(USB ホスト)相手で確認済み(27.8 枚/秒、500 枚すべて届く) |
| `magicon_wifi`(Wi-Fi の画面転送) | Core2350B2 単体で 1 枚目が裏画面に入るまで確認。**ファミコンでは未検証** |
| ゲーム選択メニュー | PC の試験台で確認済み(37 項目、ページ送り、選んでゲーム・NSF・画面転送が始まる)。**実機では未検証** |
| PC の音(画面転送モード) | Core2350B2 単体 + Wi-Fi で、GPIO44 のイヤホンで鳴ることを確認。**ファミコンの音声に混ぜては未検証** |
| バッテリーバックアップ、NSF の拡張音源 | 未実装 |

## 関係するファイル

| ファイル | 内容 |
|---|---|
| `firmware/out/*.uf2` | ファームウェア(bus_test・chr_test・magicon) |
| `firmware/load_rom.ps1` | ROM / NSF / 画面転送モードをカセットに書く |
| `firmware/tools/remote_pc.py` | リモートデスクトップの PC 側アプリ |
| `firmware/wifi_bridge/` | Wi-Fi ブリッジ(ESP32-C6)のファームウェアと書き込みスクリプト |
| `firmware/tools/wifi_bench.py` | Wi-Fi ブリッジの速さを測る |
| `firmware/README.md` | ファームウェアの詳しい説明 |
| `docs/hardware_spec.pdf` | 基板の仕様書(ピン・部品・ジャンパー) |
| `docs/build_manual.py` | この手順書を作るスクリプト(表は `nes_pack.py`・`remote_pc.py` から作る) |

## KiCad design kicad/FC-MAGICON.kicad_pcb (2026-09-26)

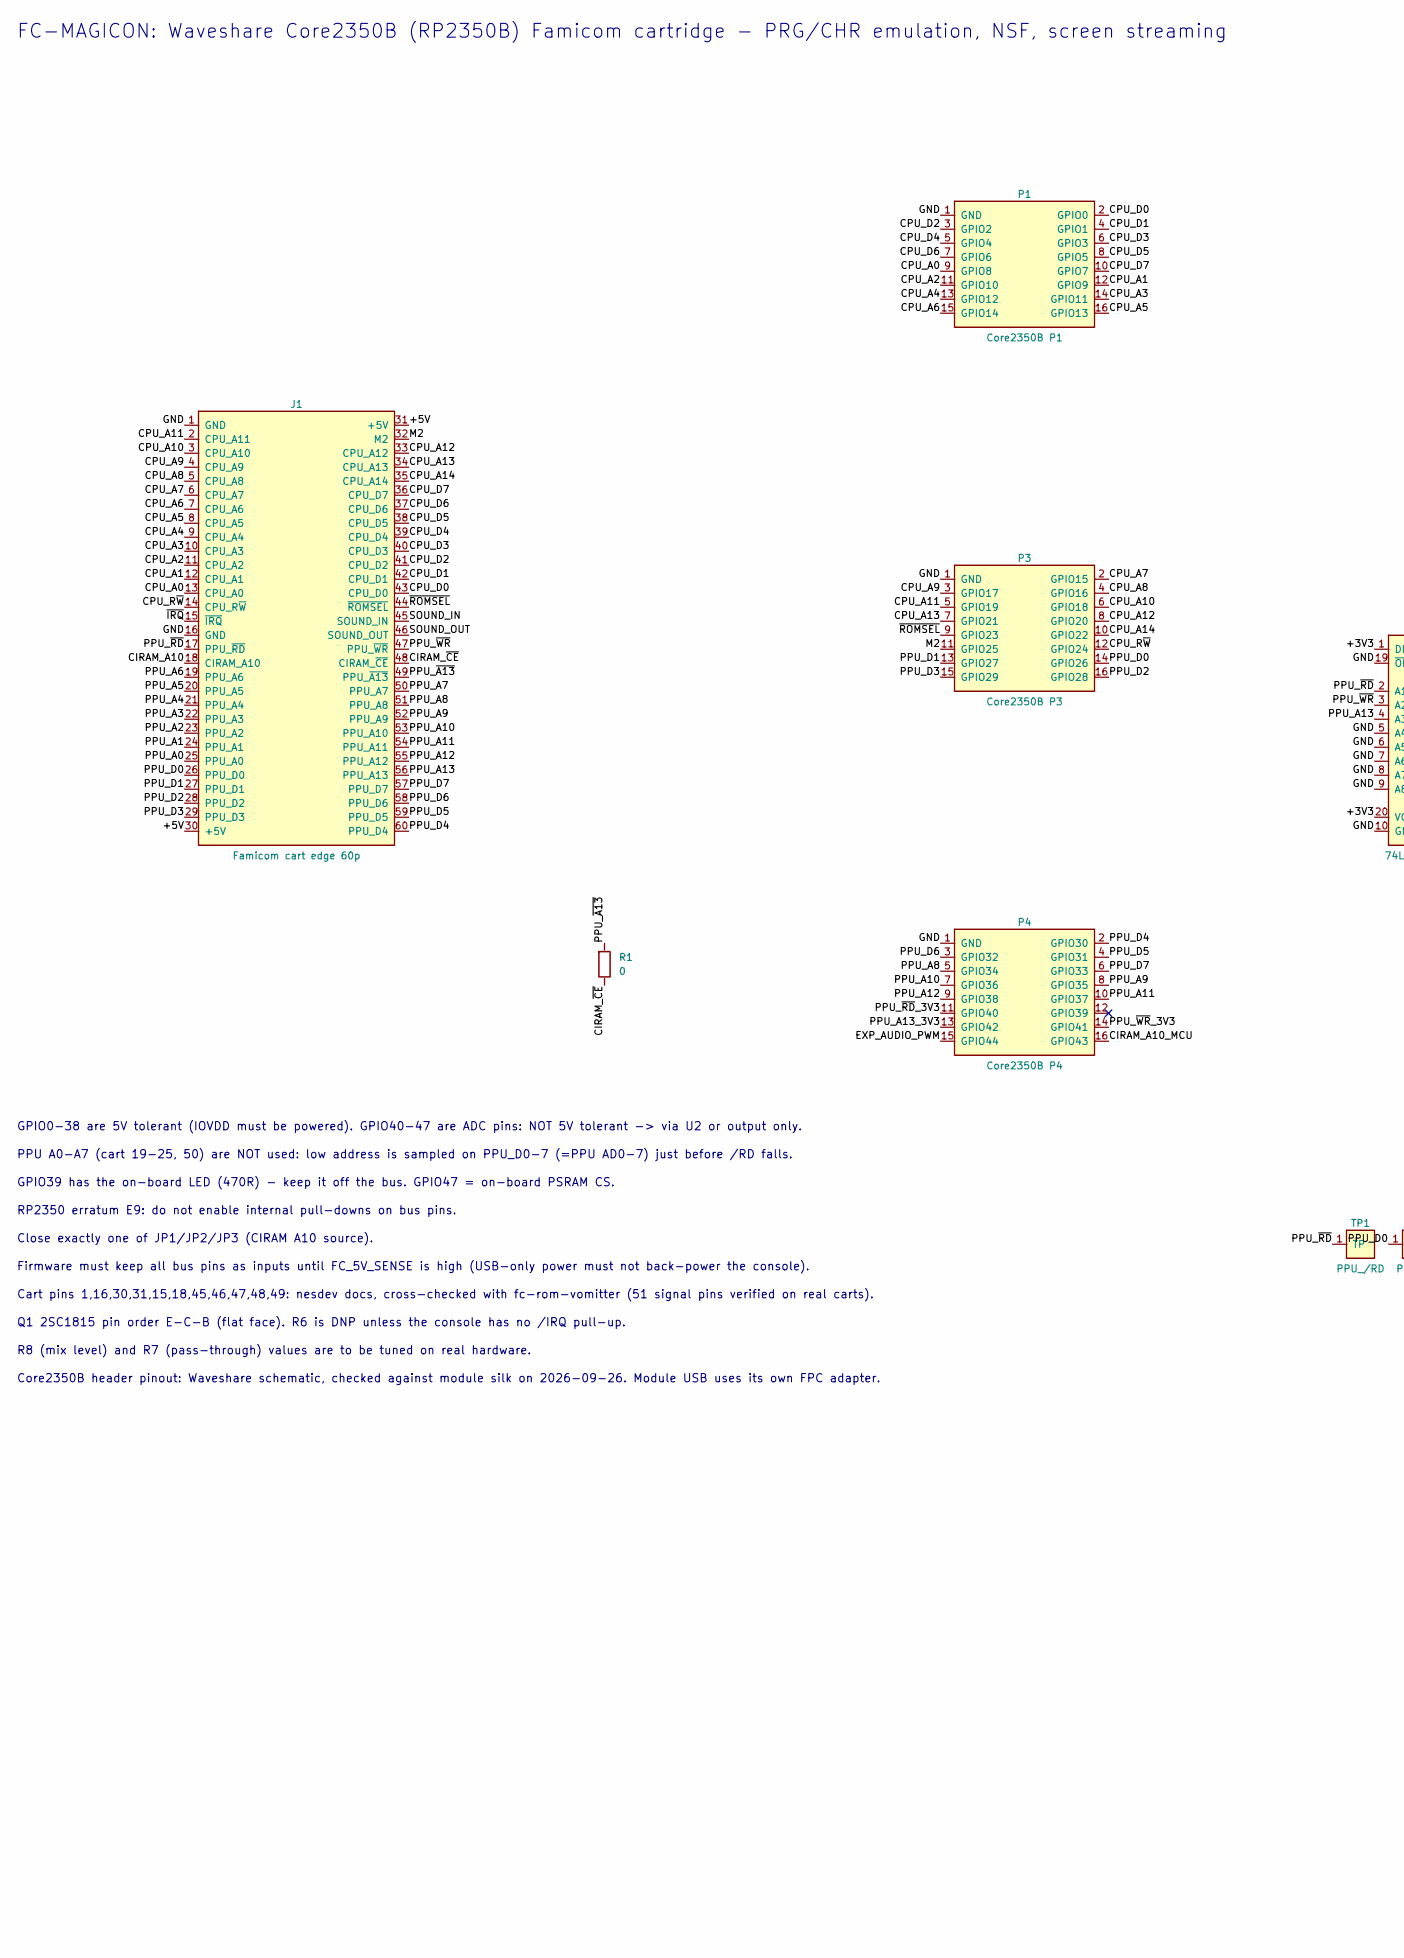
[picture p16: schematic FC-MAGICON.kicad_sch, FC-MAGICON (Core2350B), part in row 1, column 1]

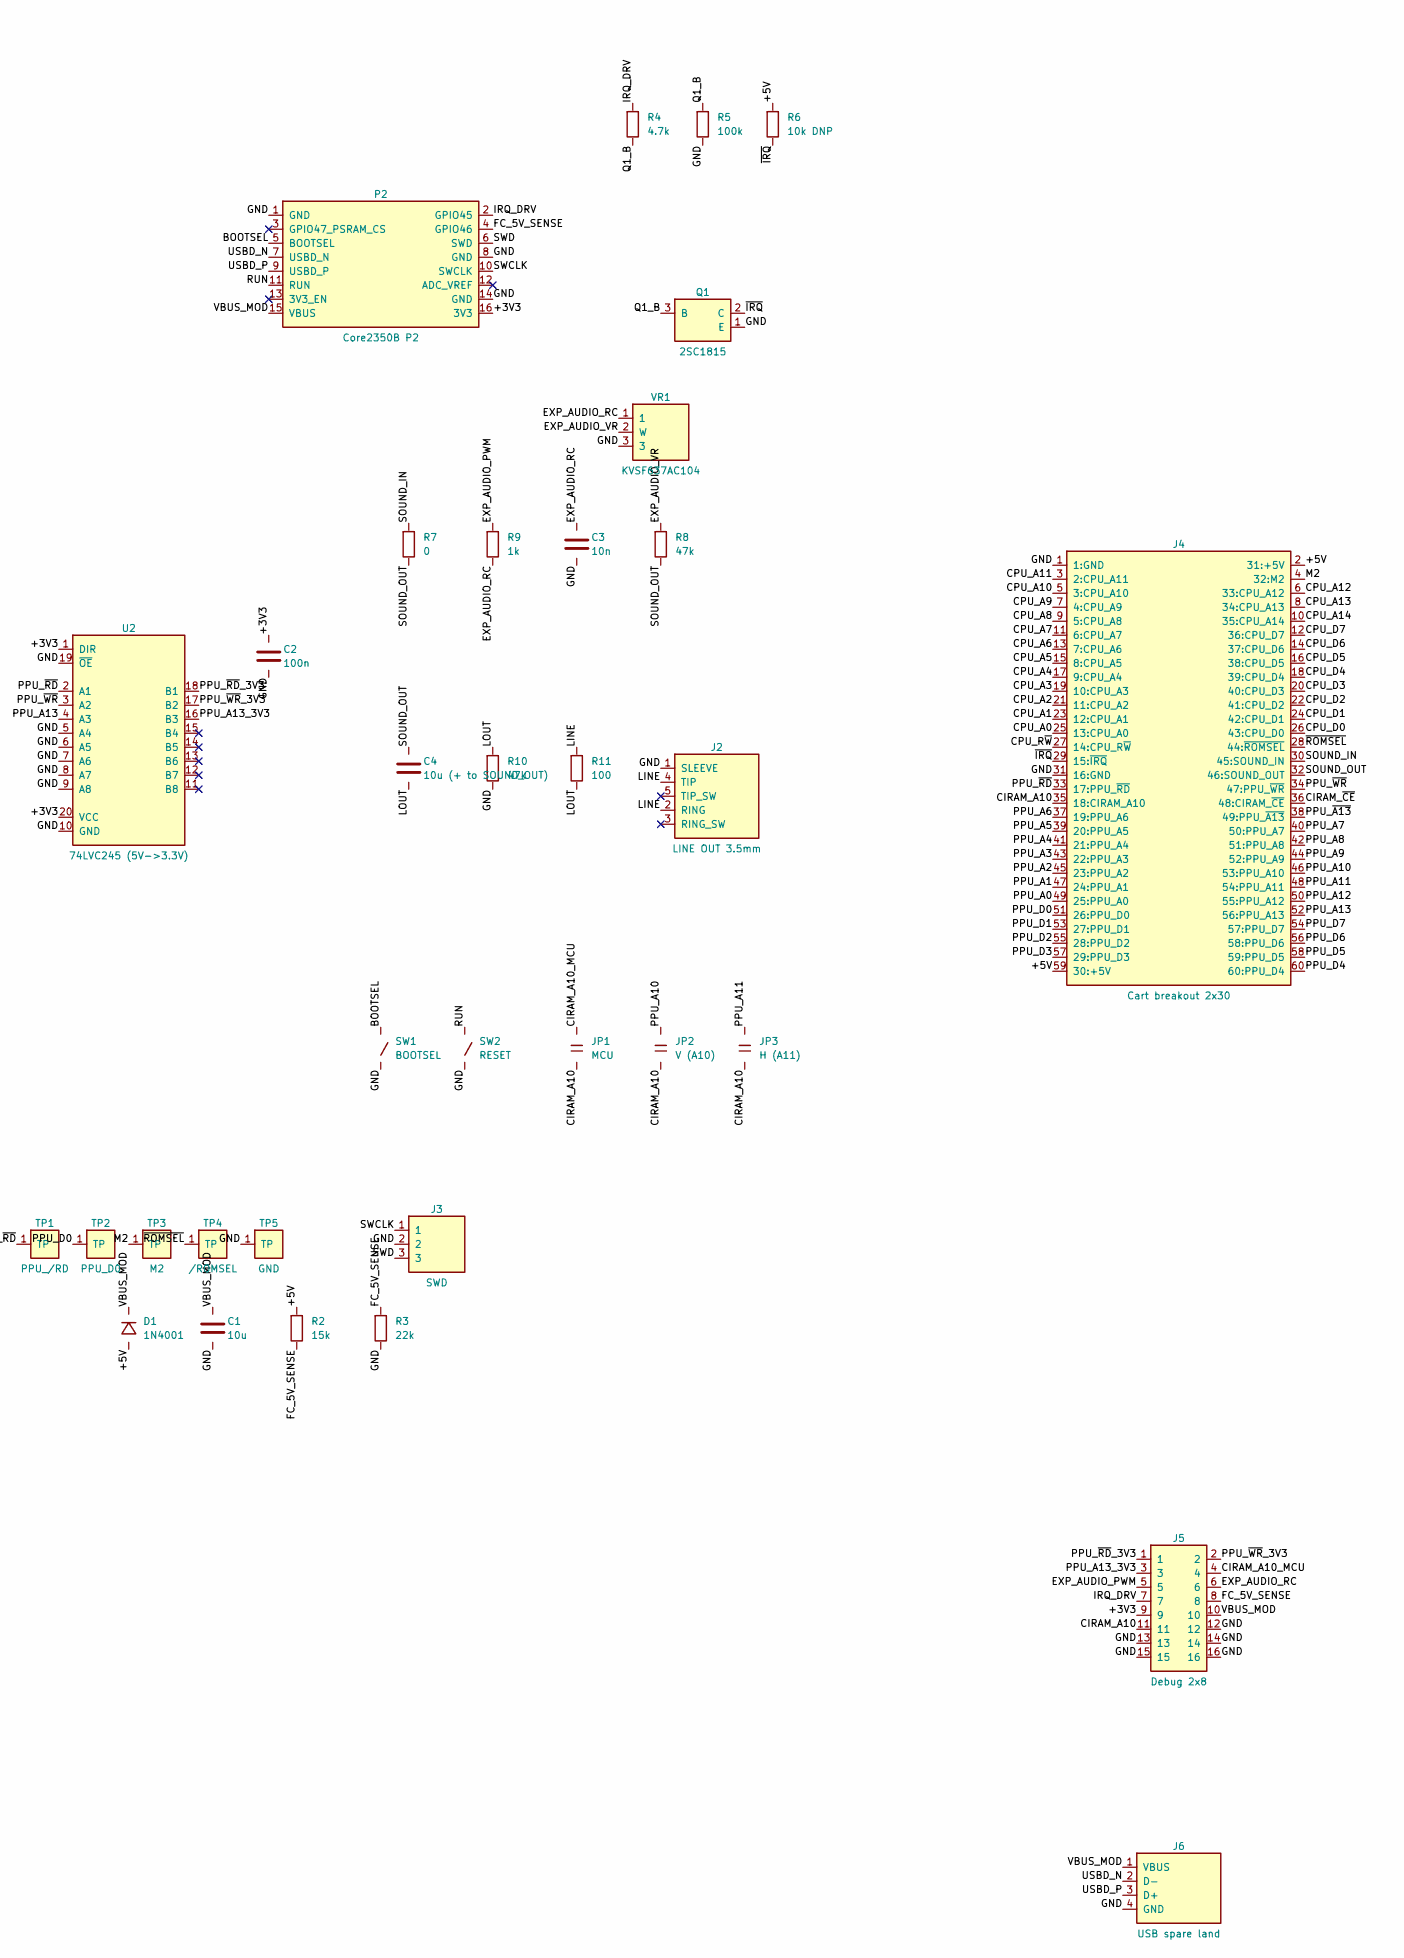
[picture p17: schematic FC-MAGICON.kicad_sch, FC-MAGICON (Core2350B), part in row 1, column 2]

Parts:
C1: 10u; CP_Radial_D5.0mm_P2.00mm
C2: 100n; C_Disc_D3.0mm_W1.6mm_P2.50mm
C3: 10n; C_Disc_D3.0mm_W1.6mm_P2.50mm
C4: 10u (+ to SOUND_OUT); CP_Radial_D5.0mm_P2.00mm
D1: 1N4001; D_DO-41_SOD81_P7.62mm_Horizontal
J1: Famicom cart edge 60p; FC_Cart_Edge_60
J2: LINE OUT 3.5mm; PJ-324M
J3: SWD; PinHeader_1x03_P2.54mm_Vertical
J4: Cart breakout 2x30; PinHeader_2x30_P2.54mm_Vertical
J5: Debug 2x8; PinHeader_2x08_P2.54mm_Vertical
J6: USB spare land; PinHeader_1x04_P2.54mm_Vertical
JP1: MCU; SolderJumper-2_P1.3mm_Open_RoundedPad1.0x1.5mm
JP2: V (A10); SolderJumper-2_P1.3mm_Open_RoundedPad1.0x1.5mm
JP3: H (A11); SolderJumper-2_P1.3mm_Open_RoundedPad1.0x1.5mm
P1: Core2350B P1; PinHeader_2x08_P2.54mm_Vertical
P2: Core2350B P2; PinHeader_2x08_P2.54mm_Vertical
P3: Core2350B P3; PinHeader_2x08_P2.54mm_Vertical
P4: Core2350B P4; PinHeader_2x08_P2.54mm_Vertical
Q1: 2SC1815; TO-92_Inline_Wide
R1, R7: 0; R_Axial_DIN0207_L6.3mm_D2.5mm_P7.62mm_Horizontal
R2: 15k; R_Axial_DIN0207_L6.3mm_D2.5mm_P7.62mm_Horizontal
R3: 22k; R_Axial_DIN0207_L6.3mm_D2.5mm_P7.62mm_Horizontal
R4: 4.7k; R_Axial_DIN0207_L6.3mm_D2.5mm_P7.62mm_Horizontal
R5: 100k; R_Axial_DIN0207_L6.3mm_D2.5mm_P7.62mm_Horizontal
R6: 10k DNP; R_Axial_DIN0207_L6.3mm_D2.5mm_P7.62mm_Horizontal
R8, R10: 47k; R_Axial_DIN0207_L6.3mm_D2.5mm_P7.62mm_Horizontal
R9: 1k; R_Axial_DIN0207_L6.3mm_D2.5mm_P7.62mm_Horizontal
R11: 100; R_Axial_DIN0207_L6.3mm_D2.5mm_P7.62mm_Horizontal
SW1: BOOTSEL; SW_PUSH_6mm
SW2: RESET; SW_PUSH_6mm
TP1: PPU_/RD; TestPoint_THTPad_D1.5mm_Drill0.7mm
TP2: PPU_D0; TestPoint_THTPad_D1.5mm_Drill0.7mm
TP3: M2; TestPoint_THTPad_D1.5mm_Drill0.7mm
TP4: /ROMSEL; TestPoint_THTPad_D1.5mm_Drill0.7mm
TP5: GND; TestPoint_THTPad_D1.5mm_Drill0.7mm
U2: 74LVC245 (5V->3.3V); DIP-20_W7.62mm
VR1: KVSF637AC104; KOA_SF6_637A

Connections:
/+3V3: C2.1, J5.9, P2.16 (3V3), U2.1 (DIR), U2.20 (VCC)
/+5V: D1.2, J1.30 (+5V), J1.31 (+5V), J4.2 (31:+5V), J4.59 (30:+5V), R2.1, R6.1
/BOOTSEL: P2.5 (BOOTSEL), SW1.1
/CIRAM_A10: J1.18 (CIRAM_A10), J4.35 (18:CIRAM_A10), J5.11, JP1.2, JP2.2, JP3.2
/CIRAM_A10_MCU: J5.4, JP1.1, P4.16 (GPIO43)
/CIRAM_~CE: J1.48 (CIRAM_~CE), J4.36 (48:CIRAM_~CE), R1.2
/CPU_A0: J1.13 (CPU_A0), J4.25 (13:CPU_A0), P1.9 (GPIO8)
/CPU_A1: J1.12 (CPU_A1), J4.23 (12:CPU_A1), P1.12 (GPIO9)
/CPU_A2: J1.11 (CPU_A2), J4.21 (11:CPU_A2), P1.11 (GPIO10)
/CPU_A3: J1.10 (CPU_A3), J4.19 (10:CPU_A3), P1.14 (GPIO11)
/CPU_A4: J1.9 (CPU_A4), J4.17 (9:CPU_A4), P1.13 (GPIO12)
/CPU_A5: J1.8 (CPU_A5), J4.15 (8:CPU_A5), P1.16 (GPIO13)
/CPU_A6: J1.7 (CPU_A6), J4.13 (7:CPU_A6), P1.15 (GPIO14)
/CPU_A7: J1.6 (CPU_A7), J4.11 (6:CPU_A7), P3.2 (GPIO15)
/CPU_A8: J1.5 (CPU_A8), J4.9 (5:CPU_A8), P3.4 (GPIO16)
/CPU_A9: J1.4 (CPU_A9), J4.7 (4:CPU_A9), P3.3 (GPIO17)
/CPU_A10: J1.3 (CPU_A10), J4.5 (3:CPU_A10), P3.6 (GPIO18)
/CPU_A11: J1.2 (CPU_A11), J4.3 (2:CPU_A11), P3.5 (GPIO19)
/CPU_A12: J1.33 (CPU_A12), J4.6 (33:CPU_A12), P3.8 (GPIO20)
/CPU_A13: J1.34 (CPU_A13), J4.8 (34:CPU_A13), P3.7 (GPIO21)
/CPU_A14: J1.35 (CPU_A14), J4.10 (35:CPU_A14), P3.10 (GPIO22)
/CPU_D0: J1.43 (CPU_D0), J4.26 (43:CPU_D0), P1.2 (GPIO0)
/CPU_D1: J1.42 (CPU_D1), J4.24 (42:CPU_D1), P1.4 (GPIO1)
/CPU_D2: J1.41 (CPU_D2), J4.22 (41:CPU_D2), P1.3 (GPIO2)
/CPU_D3: J1.40 (CPU_D3), J4.20 (40:CPU_D3), P1.6 (GPIO3)
/CPU_D4: J1.39 (CPU_D4), J4.18 (39:CPU_D4), P1.5 (GPIO4)
/CPU_D5: J1.38 (CPU_D5), J4.16 (38:CPU_D5), P1.8 (GPIO5)
/CPU_D6: J1.37 (CPU_D6), J4.14 (37:CPU_D6), P1.7 (GPIO6)
/CPU_D7: J1.36 (CPU_D7), J4.12 (36:CPU_D7), P1.10 (GPIO7)
/CPU_R~W: J1.14 (CPU_R~W), J4.27 (14:CPU_R~W), P3.12 (GPIO24)
/EXP_AUDIO_PWM: J5.5, P4.15 (GPIO44), R9.1
/EXP_AUDIO_RC: C3.1, J5.6, R9.2, VR1.1
/EXP_AUDIO_VR: R8.1, VR1.2 (W)
/FC_5V_SENSE: J5.8, P2.4 (GPIO46), R2.2, R3.1
/GND: C1.2, C2.2, C3.2, J1.1 (GND), J1.16 (GND), J2.1 (SLEEVE), J3.2, J4.1 (1:GND), J4.31 (16:GND), J5.12, J5.13, J5.14, J5.15, J5.16, J6.4 (GND), P1.1 (GND), P2.1 (GND), P2.8 (GND), P2.14 (GND), P3.1 (GND), P4.1 (GND), Q1.1 (E), R3.2, R5.2, R10.2, SW1.2, SW2.2, TP5.1, U2.5 (A4), U2.6 (A5), U2.7 (A6), U2.8 (A7), U2.9 (A8), U2.10 (GND), U2.19 (~OE), VR1.3
/IRQ_DRV: J5.7, P2.2 (GPIO45), R4.1
/LINE: J2.2 (RING), J2.4 (TIP), R11.1
/LOUT: C4.2, R10.1, R11.2
/M2: J1.32 (M2), J4.4 (32:M2), P3.11 (GPIO25), TP3.1
/PPU_A0: J1.25 (PPU_A0), J4.49 (25:PPU_A0)
/PPU_A1: J1.24 (PPU_A1), J4.47 (24:PPU_A1)
/PPU_A2: J1.23 (PPU_A2), J4.45 (23:PPU_A2)
/PPU_A3: J1.22 (PPU_A3), J4.43 (22:PPU_A3)
/PPU_A4: J1.21 (PPU_A4), J4.41 (21:PPU_A4)
/PPU_A5: J1.20 (PPU_A5), J4.39 (20:PPU_A5)
/PPU_A6: J1.19 (PPU_A6), J4.37 (19:PPU_A6)
/PPU_A7: J1.50 (PPU_A7), J4.40 (50:PPU_A7)
/PPU_A8: J1.51 (PPU_A8), J4.42 (51:PPU_A8), P4.5 (GPIO34)
/PPU_A9: J1.52 (PPU_A9), J4.44 (52:PPU_A9), P4.8 (GPIO35)
/PPU_A10: J1.53 (PPU_A10), J4.46 (53:PPU_A10), JP2.1, P4.7 (GPIO36)
/PPU_A11: J1.54 (PPU_A11), J4.48 (54:PPU_A11), JP3.1, P4.10 (GPIO37)
/PPU_A12: J1.55 (PPU_A12), J4.50 (55:PPU_A12), P4.9 (GPIO38)
/PPU_A13: J1.56 (PPU_A13), J4.52 (56:PPU_A13), U2.4 (A3)
/PPU_A13_3V3: J5.3, P4.13 (GPIO42), U2.16 (B3)
/PPU_D0: J1.26 (PPU_D0), J4.51 (26:PPU_D0), P3.14 (GPIO26), TP2.1
/PPU_D1: J1.27 (PPU_D1), J4.53 (27:PPU_D1), P3.13 (GPIO27)
/PPU_D2: J1.28 (PPU_D2), J4.55 (28:PPU_D2), P3.16 (GPIO28)
/PPU_D3: J1.29 (PPU_D3), J4.57 (29:PPU_D3), P3.15 (GPIO29)
/PPU_D4: J1.60 (PPU_D4), J4.60 (60:PPU_D4), P4.2 (GPIO30)
/PPU_D5: J1.59 (PPU_D5), J4.58 (59:PPU_D5), P4.4 (GPIO31)
/PPU_D6: J1.58 (PPU_D6), J4.56 (58:PPU_D6), P4.3 (GPIO32)
/PPU_D7: J1.57 (PPU_D7), J4.54 (57:PPU_D7), P4.6 (GPIO33)
/PPU_~A13: J1.49 (PPU_~A13), J4.38 (49:PPU_~A13), R1.1
/PPU_~RD: J1.17 (PPU_~RD), J4.33 (17:PPU_~RD), TP1.1, U2.2 (A1)
/PPU_~RD_3V3: J5.1, P4.11 (GPIO40), U2.18 (B1)
/PPU_~WR: J1.47 (PPU_~WR), J4.34 (47:PPU_~WR), U2.3 (A2)
/PPU_~WR_3V3: J5.2, P4.14 (GPIO41), U2.17 (B2)
/Q1_B: Q1.3 (B), R4.2, R5.1
/RUN: P2.11 (RUN), SW2.1
/SOUND_IN: J1.45 (SOUND_IN), J4.30 (45:SOUND_IN), R7.1
/SOUND_OUT: C4.1, J1.46 (SOUND_OUT), J4.32 (46:SOUND_OUT), R7.2, R8.2
/SWCLK: J3.1, P2.10 (SWCLK)
/SWD: J3.3, P2.6 (SWD)
/USBD_N: J6.2 (D-), P2.7 (USBD_N)
/USBD_P: J6.3 (D+), P2.9 (USBD_P)
/VBUS_MOD: C1.1, D1.1, J5.10, J6.1 (VBUS), P2.15 (VBUS)
/~IRQ: J1.15 (~IRQ), J4.29 (15:~IRQ), Q1.2 (C), R6.2
/~ROMSEL: J1.44 (~ROMSEL), J4.28 (44:~ROMSEL), P3.9 (GPIO23), TP4.1

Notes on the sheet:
FC-MAGICON: Waveshare Core2350B (RP2350B) Famicom cartridge - PRG/CHR emulation, NSF, screen streaming
GPIO0-38 are 5V tolerant (IOVDD must be powered). GPIO40-47 are ADC pins: NOT 5V tolerant -> via U2 or output only.
PPU A0-A7 (cart 19-25, 50) are NOT used: low address is sampled on PPU_D0-7 (=PPU AD0-7) just before /RD falls.
GPIO39 has the on-board LED (470R) - keep it off the bus. GPIO47 = on-board PSRAM CS.
RP2350 erratum E9: do not enable internal pull-downs on bus pins.
Close exactly one of JP1/JP2/JP3 (CIRAM A10 source).
Firmware must keep all bus pins as inputs until FC_5V_SENSE is high (USB-only power must not back-power the console).
Cart pins 1,16,30,31,15,18,45,46,47,48,49: nesdev docs, cross-checked with fc-rom-vomitter (51 signal pins verified on real carts).
Q1 2SC1815 pin order E-C-B (flat face). R6 is DNP unless the console has no /IRQ pull-up.
R8 (mix level) and R7 (pass-through) values are to be tuned on real hardware.
Core2350B header pinout: Waveshare schematic, checked against module silk on 2026-09-26. Module USB uses its own FPC adapter.

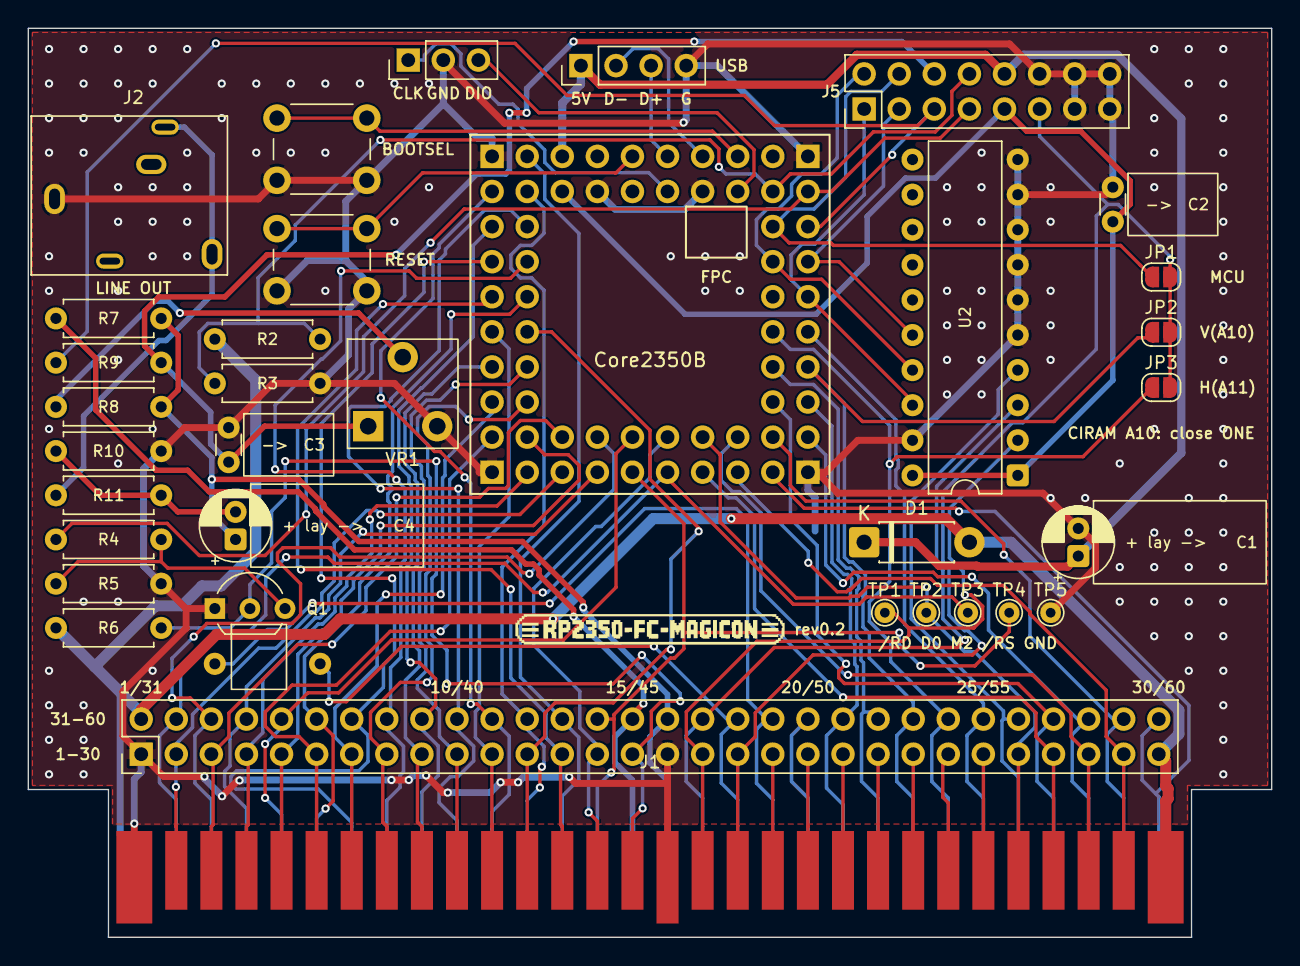
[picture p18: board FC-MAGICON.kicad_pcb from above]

Board: 2 copper layers, 90.0 x 65.8 mm, 39 parts (1 on the bottom side), 78 nets.

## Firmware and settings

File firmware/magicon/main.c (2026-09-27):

// FC-MAGICON magicon — フラッシュに書いた .nes / .nsf をファミコンで動かす(マジコン本体 + NSF プレイヤー)
//
//   ・ROM はフラッシュの 8MB 目(ROM_SLOT)に load_rom.ps1 で書く。形式は tools/nes_pack.py の
//     「"FCMG" + 長さ + 合計 + 予備(各4バイト)」の後ろに .nes をそのまま
//   ・起動したら ROM を SRAM へ写し(PRG + CHR 384KB まで)、本体の 5V を待ってからバスに出る
//   ・ROM が無い・壊れている・対応していない時は、chr_test と同じ試験画面(4色の縦縞 + 格子、音)を出す
//   ・USB シリアルに、読み込んだ ROM の情報と、1 秒ごとの CPU サイクル・PPU 読み出し・書き込みの回数を出す
//   ・MAGICON_USB_HOST = 1 でビルドすると magicon_wifi になる: 画面転送モードの USB を「ホスト」にして、
//     J6 につないだ ESP32-C6(firmware/wifi_bridge、USB Serial/JTAG = CDC)とやりとりする(PC とは Wi-Fi 越し)。
//     この時は USB シリアル(printf)も picotool の自動書き込みモードも無い。TinyUSB 0.21 が要る(build.ps1)
#include <stdio.h>
#include <string.h>
#include "pico/stdlib.h"
#include "hardware/clocks.h"
#include "hardware/vreg.h"
#include "hardware/structs/sio.h"
#include "hardware/watchdog.h"
#include "cart.h"
#include "audio.h"
#if MAGICON_USB_HOST
#include "tusb.h"
#endif

#define PIN_LED        39
// LED は SIO のレジスターを直接たたく(RP2350 の gpio_xor_mask64 / gpio_put は GPIO コプロセッサー命令になり、
// host_test ではそれで NOCP の HardFault が起きた。magicon では起きていないが、同じ書き方にそろえておく)
#define LED_TOGGLE()   (sio_hw->gpio_hi_togl = 1u << (PIN_LED - 32))
#define LED_ON()       (sio_hw->gpio_hi_set = 1u << (PIN_LED - 32))
#define PIN_CIRAM_A10  43
#define PIN_AUDIO      44               // PWM → RC → VR1 → R8 → カセット端子 46 番(本体の音声に混ぜる)
#define PIN_FC_5V      46
#define BUS_PIN_LAST   42
#define ROM_SLOT       0x00800000u      // フラッシュ先頭から 8MB(ファームウェアとは重ならない)

typedef struct {
    char magic[4];                      // "FCMG"
    uint32_t len;                       // .nes の長さ
    uint32_t sum;                       // .nes のバイトの合計
    uint32_t reserved;
} slot_header_t;

static void bus_pins_input(void) {
    for (uint p = 0; p <= 46; p++) {    // GPIO47 は PSRAM の CS なので触らない
        if (p == PIN_LED)
            continue;
        gpio_init(p);
        gpio_set_dir(p, GPIO_IN);
        gpio_disable_pulls(p);          // RP2350 エラッタ E9: バスのピンでプルダウンを使わない
    }
}

// ---- ゲーム選択メニュー ----
// メニューで選ぶと、番号をウォッチドッグのメモ(scratch[0]、再起動しても消えない。電源が切れると消える)に残して
// 再起動し、次の起動でその ROM を読み込む。本体側はその間、本体 RAM のプログラムで 1.5 秒待っている(gen_menu_driver.py)
#define PICK_MAGIC     0xFC010000u
#define LIB_SPACE      0x00800000u      // ライブラリに使える大きさ(8MB 目からフラッシュの終わりまで)

static void reboot_with_pick(uint32_t pick) {
    watchdog_hw->scratch[0] = pick;
    watchdog_reboot(0, 0, 0);
    for (;;) tight_loop_contents();
}

// 本体の電源が切れたら(5V が 50ms 続けて無い)再起動する: 次に電源を入れた時はメニューから
static void check_power(void) {
    static bool low;
    static absolute_time_t since;
    if (gpio_get(PIN_FC_5V)) {
        low = false;
        return;
    }
    if (!low) {
        low = true;
        since = get_absolute_time();
    } else if (absolute_time_diff_us(since, get_absolute_time()) > 50000) {
        reboot_with_pick(0);
    }
}

static const char *load_entry(const lib_entry_t *e, cart_info_t *info) {
    if (e->offset > LIB_SPACE || e->len > LIB_SPACE - e->offset || e->len < 4)
        return "bad library entry";
    const uint8_t *p = (const uint8_t *)(XIP_BASE + ROM_SLOT + e->offset);
    uint32_t sum = 0;
    for (uint32_t i = 0; i < e->len; i++)
        sum += p[i];
    if (sum != e->sum)
        return "checksum mismatch in library (write it again)";
    return cart_load(p, e->len, info);
}

static const char *load_library(cart_info_t *info) {
    const lib_header_t *lh = (const lib_header_t *)(XIP_BASE + ROM_SLOT);
    const lib_entry_t *e = (const lib_entry_t *)(lh + 1);
    if (lh->count == 0 || lh->count > LIB_MAX_ITEMS)
        return "bad library header";
    uint32_t pick = watchdog_hw->scratch[0];
    watchdog_hw->scratch[0] = 0;
    if ((pick & 0xFFFF0000u) == PICK_MAGIC && (pick & 0xFFFF) < lh->count)
        return load_entry(&e[pick & 0xFFFF], info);
    if (lh->count == 1)
        return load_entry(&e[0], info);
    cart_load_menu(e, (int)lh->count, info);
    return NULL;
}

static const char *load_from_flash(cart_info_t *info) {
    const slot_header_t *h = (const slot_header_t *)(XIP_BASE + ROM_SLOT);
    const uint8_t *nes = (const uint8_t *)(h + 1);
    if (memcmp(h->magic, "FCLB", 4) == 0)
        return load_library(info);
    if (memcmp(h->magic, "FCMG", 4) != 0)
        return "no ROM in flash (write one with load_rom.ps1)";
    if (h->len < 4 || h->len > 4u * 1024 * 1024)        // 4 = 画面転送モードの印 "FCRD"
        return "bad length in flash header";
    uint32_t sum = 0;
    for (uint32_t i = 0; i < h->len; i++)
        sum += nes[i];
    if (sum != h->sum)
        return "checksum mismatch (write the ROM again)";
    return cart_load(nes, h->len, info);
}

// ---- 画面転送モードの USB のやりとり(コア0) ----
//   PC → カセット: "FCFR" + 絵 15360 + パレット 32 + 属性 64 + カーソル x, y, visible(3)
//                  絵は裏の画面へ直接読み込む。表示待ちの 1 枚がある間は読まない(PC 側がそこで待たされる)
//                  "FCAU" + 形式 1(0 = 16 ビット PCM、1 = IMA ADPCM)+ サンプル数 2(LE)+ 中身 = PC の音(32kHz モノラル)
//   カセット → PC: "FCIN" + パッド 1 + キーボード 9 行 + 予備 5 + 6502 のフレームの数 1(= 16)
//                  6502 のフレームの数が変わるたびに(約 60 回/秒)
//   通り道は USB シリアル(magicon、PC 直結)か、USB ホストで開いた C6 の CDC(magicon_wifi)
#if MAGICON_USB_HOST
static uint8_t cdc = 0xFF;              // 開いている C6 の CDC の番号(0xFF = まだ)

void tuh_cdc_mount_cb(uint8_t idx) { cdc = idx; }
void tuh_cdc_umount_cb(uint8_t idx) { if (idx == cdc) cdc = 0xFF; }
uint32_t tusb_time_millis_api(void) { return to_ms_since_boot(get_absolute_time()); }   // OS 無しの TinyUSB の時計

static void usb_poll(void) { tuh_task(); }

static int read_exact(uint8_t *buf, int len, uint32_t timeout_ms) {
    int got = 0;
    absolute_time_t until = make_timeout_time_ms(timeout_ms);
    while (got < len) {
        tuh_task();
        if (cdc != 0xFF) {
            uint32_t n = tuh_cdc_read(cdc, buf + got, (uint32_t)(len - got));
            got += (int)n;
            if (n) continue;
        }
        if (time_reached(until)) break;
    }
    return got;
}

static void write_packet(const uint8_t *p, int len) {
    // 入り切らない時は捨てる(次のフレームでまた送る)
    if (cdc == 0xFF || tuh_cdc_write_available(cdc) < (uint32_t)len) return;
    tuh_cdc_write(cdc, p, (uint32_t)len);
    tuh_cdc_write_flush(cdc);
}
#else
static void usb_poll(void) {}

static int read_exact(uint8_t *buf, int len, uint32_t timeout_ms) {
    int got = 0;
    absolute_time_t until = make_timeout_time_ms(timeout_ms);
    while (got < len) {
        int n = stdio_get_until((char *)buf + got, len - got, until);
        if (n <= 0) return got;         // PICO_ERROR_TIMEOUT
        got += n;
    }
    return got;
}

static void write_packet(const uint8_t *p, int len) {
    stdio_put_string((const char *)p, len, false, false);
}
#endif

static void send_input(uint8_t *last_frame) {
    uint8_t io[16];
    cart_remote_io(io);
    if (io[15] == *last_frame) return;
    *last_frame = io[15];
    uint8_t pkt[20] = {'F', 'C', 'I', 'N'};
    memcpy(pkt + 4, io, 16);
    write_packet(pkt, sizeof pkt);
}

static void __attribute__((noreturn)) remote_loop(void) {
    static uint8_t meta[32 + 64 + 3];
    static uint8_t au[2 * AUDIO_MAX_SAMPLES];
    uint8_t last_frame = 0, c;
    uint32_t match = 0;
    for (;;) {
        send_input(&last_frame);
        audio_poll();
        check_power();
        // "FCFR" / "FCAU" を探す(途中から読み始めても合うように 1 バイトずつ)
        if (read_exact(&c, 1, 1) != 1) continue;
        match = (match << 8) | c;
        if (match == ('F' << 24 | 'C' << 16 | 'A' << 8 | 'U')) {
            match = 0;
            uint8_t h[3];
            if (read_exact(h, 3, 100) != 3) continue;
            uint16_t n = (uint16_t)(h[1] | h[2] << 8);
            int len = audio_payload_len(h[0], n);
            if (len < 0 || read_exact(au, len, 100) != len) continue;
            audio_push(h[0], n, au);
            continue;
        }
        if (match != ('F' << 24 | 'C' << 16 | 'F' << 8 | 'R')) continue;
        match = 0;
        uint8_t *back;
        while (!(back = cart_remote_back())) {           // 前の 1 枚がまだ表示されていない
            send_input(&last_frame);
            audio_poll();
            usb_poll();
            sleep_us(200);
        }
        if (read_exact(back, 15360, 500) != 15360) continue;
        if (read_exact(meta, sizeof meta, 500) != (int)sizeof meta) continue;
        cart_remote_commit(meta, meta + 32, meta[96], meta[97], meta[98]);
        LED_TOGGLE();                                     // 1 枚ごとに LED を反転
    }
}

int main(void) {
    bus_pins_input();
    gpio_init(PIN_LED);
    gpio_set_dir(PIN_LED, GPIO_OUT);

    vreg_set_voltage(VREG_VOLTAGE_1_20);
    sleep_ms(10);
    set_sys_clock_khz(250000, true);
#if MAGICON_USB_HOST
    const tusb_rhport_init_t rh = {.role = TUSB_ROLE_HOST, .speed = TUSB_SPEED_AUTO};
    tusb_rhport_init(0, &rh);           // J6 の C6 を待つ(つながるまでの手続きは usb_poll = tuh_task で進む)
#else
    stdio_init_all();
#endif

    // 本体がリセットを解く前にバスへ出られるよう、ROM の読み込みは 5V を待つ前に済ませる
    cart_info_t info;
    const char *err = load_from_flash(&info);
    if (err)
        cart_load_fallback(&info);

    while (!gpio_get(PIN_FC_5V)) {      // 本体の電源が入るまでバスへ出さない(USB だけの時に逆流させない)
        LED_TOGGLE();
        for (int i = 0; i < 100; i++) {
            usb_poll();
            sleep_ms(1);
        }
        printf("waiting for Famicom 5V (GPIO46)...  ROM: %s\n", err ? err : "ok");
    }
    LED_ON();
    cart_start();
    if (!err && info.is_remote) {
        audio_init(PIN_AUDIO);          // PC の音(無音から鳴らし始める)
        remote_loop();                  // 戻らない
    }

    uint32_t lc = 0, lp = 0, lw = 0;
    for (;;) {
        for (int i = 0; i < 1000; i++) {
            usb_poll();
            check_power();
            if (info.is_menu && cart_menu_choice() >= 0)
                reboot_with_pick(PICK_MAGIC | (uint32_t)cart_menu_choice());   // 選ばれた ROM で起動し直す
            sleep_ms(1);
        }
        uint32_t c = stat_cpu, p = stat_ppu, w = stat_wr;
        if (err)
            printf("[test screen] %s | ", err);
        else if (info.is_menu)
            printf("[game select menu] ");
        else if (info.is_nsf)
            printf("[NSF \"%s\" / %s  %d songs  load $%04X init $%04X play $%04X%s%s] ", info.nsf_title, info.nsf_artist,
                   info.nsf_songs, info.nsf_load, info.nsf_init, info.nsf_play, info.nsf_banked ? "  banked" : "",
                   info.nsf_exp ? "  (expansion audio not played yet)" : "");
        else
            printf("[mapper %d %s  PRG %luK  CHR %s%luK  %s%s] ", info.mapper, cart_mapper_name(info.mapper),
                   (unsigned long)(info.prg_size / 1024), info.chr_size ? "" : "RAM ",
                   (unsigned long)((info.chr_size ? info.chr_size : 0x2000) / 1024),
                   info.vertical ? "V" : "H", info.battery ? " battery" : "");
        printf("cpu %lu/s  ppu %lu/s  writes %lu/s\n", (unsigned long)(c - lc), (unsigned long)(p - lp),
               (unsigned long)(w - lw));
        lc = c; lp = p; lw = w;
    }
}

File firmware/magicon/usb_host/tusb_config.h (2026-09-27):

// magicon_wifi の TinyUSB 設定(RP2350 の USB をホストにして、J6 の ESP32-C6 の USB Serial/JTAG = CDC ACM を開く)
// host_test/tusb_config.h と同じ中身(ログだけ無し)。TinyUSB 0.21.0 で使う
#pragma once

// OS 無しで使う(pico-sdk は CFG_TUSB_OS=OPT_OS_PICO を渡してくるが、TinyUSB 0.21 と pico-sdk 2.3.1 の組み合わせでは
// CDC の受信 FIFO の mutex が初期化されないまま tuh_cdc_read が待ち続けた)。USB はコア 0 のループ 1 本で回す
#undef CFG_TUSB_OS
#define CFG_TUSB_OS                OPT_OS_NONE
#include "pico.h"                  // __not_in_flash など(OS 無しだと osal_pico.h 経由で読み込まれなくなる)

#define CFG_TUH_ENABLED            1
#define CFG_TUSB_RHPORT0_MODE      OPT_MODE_HOST
#define BOARD_TUH_RHPORT           0
#define CFG_TUH_MAX_SPEED          OPT_MODE_FULL_SPEED
#define CFG_TUH_ENUMERATION_BUFSIZE 256
#define CFG_TUH_HUB                0
#define CFG_TUH_DEVICE_MAX         1
#define CFG_TUH_CDC                1

// 開いた時に DTR だけ立てる(C6 の USB Serial/JTAG は RTS でリセットがかかる)
#define CFG_TUH_CDC_LINE_CONTROL_ON_ENUM  CDC_CONTROL_LINE_STATE_DTR
#define CFG_TUH_CDC_LINE_CODING_ON_ENUM   { 115200, CDC_LINE_CODING_STOP_BITS_1, CDC_LINE_CODING_PARITY_NONE, 8 }

#define CFG_TUH_CDC_RX_BUFSIZE     4096
#define CFG_TUH_CDC_TX_BUFSIZE     256

#define CFG_TUSB_MEM_ALIGN         __attribute__((aligned(4)))

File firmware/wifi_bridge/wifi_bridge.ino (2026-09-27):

// FC-MAGICON 画面転送の Wi-Fi ブリッジ(ESP32-C6)。
//   PC ──Wi-Fi(TCP 5000番)── ESP32-C6 ──USB(C6 の USB Serial/JTAG)── RP2350(USB ホスト)
// 中身は見ずに、TCP で来たバイトを USB へ、USB で来たバイトを TCP へそのまま流すだけ。
// TCP がつながっていない間は、USB に 2 秒ごとに "fc-magicon wifi_bridge ip=..." を出す
// (カセットは "FCFR" を探して読むので邪魔にならない。PC の wifi_bench.py はこれで IP を知る)。
//
// ビルド: build_bridge.ps1(Arduino-ESP32 3.3、FQBN esp32:esp32:esp32c6:CDCOnBoot=cdc)
// Wi-Fi の SSID とパスワードは wifi_secrets.h に書く(wifi_secrets.example.h を写して。GitHub には上げない)。
#include <WiFi.h>
#include <ESPmDNS.h>
#include "esp_flash.h"
#include "hal/spi_flash_hal.h"
#include "hal/spimem_flash_ll.h"
#include "wifi_secrets.h"

// 手持ちの C6 N4 ボードはフラッシュを 80MHz で読むと化ける(パーティションテーブル 0x50AA が 0x500A / 0x502A になる、
// Wi-Fi の初期化が ESP_ERR_NOT_FOUND で失敗する)。Arduino の C6 用ライブラリは 80MHz 固定なので、
// フラッシュのドライバーが初期化された後・Arduino が NVS を読む前(グローバルのコンストラクター)に 40MHz(80MHz ÷ 2)に落とす。
// ブートローダーの方は FQBN の FlashFreq=40 で 40MHz になる(build_bridge.ps1)。
__attribute__((constructor)) static void flash_40mhz() {
  spi_flash_hal_context_t *h = (spi_flash_hal_context_t *)esp_flash_default_chip->host;
  h->clock_conf.spimem = spimem_flash_ll_calculate_clock_reg(2);
}

static const uint16_t TCP_PORT = 5000;
static WiFiServer server(TCP_PORT);
static WiFiClient client;
static uint8_t buf[4096];
static volatile int last_reason;        // 最後に切れた理由(Wi-Fi の reason コード。つながらない時の手がかり)

// つながらない時に、その SSID が見えているか・電波の強さ・暗号方式を USB に出す
static void report_scan() {
  int n = WiFi.scanNetworks();
  bool found = false;
  for (int i = 0; i < n; i++) {
    if (WiFi.SSID(i) == WIFI_SSID) {
      Serial.printf("  scan: %s ch=%d rssi=%d auth=%d\r\n", WiFi.SSID(i).c_str(), WiFi.channel(i), WiFi.RSSI(i), (int)WiFi.encryptionType(i));
      found = true;
    }
  }
  if (!found) Serial.printf("  scan: %s is not visible (%d networks)\r\n", WIFI_SSID, n);
  WiFi.scanDelete();
}

// 様子を UART0(ボードの UART の USB-C = USB-UART 変換チップ)へ 1 秒ごとに出す。USB(Serial)はデータ専用なので使えない
static uint32_t n_tcp_in, n_usb_out, n_usb_zero, n_usb_in;
static void debug_report() {
  static uint32_t last;
  if (millis() - last < 1000) return;
  last = millis();
  Serial0.printf("[%lus] wifi=%d ip=%s tcp=%d usb_conn=%d | tcp_in=%lu usb_out=%lu usb_write0=%lu usb_in=%lu\r\n",
                 (unsigned long)(millis() / 1000), (int)WiFi.status(), WiFi.localIP().toString().c_str(),
                 (int)(client && client.connected()), (int)(bool)Serial,
                 (unsigned long)n_tcp_in, (unsigned long)n_usb_out, (unsigned long)n_usb_zero, (unsigned long)n_usb_in);
}

// USB へ全部書く。RP2350 が読まない間は待つ(その間 TCP から読まないので、PC 側の送信が止まる)
static bool usb_write_all(const uint8_t *p, size_t n) {
  while (n) {
    size_t w = Serial.write(p, n);
    p += w;
    n -= w;
    n_usb_out += w;
    if (!w) {
      n_usb_zero++;
      debug_report();
      if (!client.connected()) return false;
      delay(1);
    }
  }
  return true;
}

void setup() {
  Serial0.begin(115200);                // 様子の表示(debug_report)
  Serial.setRxBufferSize(8192);
  Serial.setTxBufferSize(16384);
  Serial.begin(115200);                 // USB Serial/JTAG(速度の指定は意味を持たない)
  Serial.setTxTimeoutMs(20);
  WiFi.mode(WIFI_STA);
  WiFi.setSleep(false);                 // 省電力を切る(切らないと受信が遅れる)
  WiFi.onEvent([](WiFiEvent_t, WiFiEventInfo_t info) { last_reason = info.wifi_sta_disconnected.reason; },
               ARDUINO_EVENT_WIFI_STA_DISCONNECTED);
  WiFi.begin(WIFI_SSID, WIFI_PASS);
  MDNS.begin("fc-magicon");             // fc-magicon.local で見つかるように
  MDNS.addService("fcbridge", "tcp", TCP_PORT);
  server.begin();
  server.setNoDelay(true);
}

void loop() {
  static uint32_t last_hello;
  debug_report();
  if (!client || !client.connected()) {
    client = server.accept();
    if (client) {
      client.setNoDelay(true);
      while (Serial.available()) Serial.read();   // つながる前に来ていた分は捨てる
    } else {
      if (millis() - last_hello > 2000) {
        last_hello = millis();
        if (WiFi.status() == WL_CONNECTED)
          Serial.printf("fc-magicon wifi_bridge ip=%s port=%u\r\n", WiFi.localIP().toString().c_str(), TCP_PORT);
        else {
          static int tries;
          Serial.printf("fc-magicon wifi_bridge connecting to %s (status=%d reason=%d)\r\n", WIFI_SSID, (int)WiFi.status(), last_reason);
          if (++tries % 5 == 0) report_scan();          // 10 秒ごとに周りを探す
        }
      }
      while (Serial.available()) {
        Serial.read();
        n_usb_in++;
      }
      delay(5);
      return;
    }
  }
  // PC → カセット
  int n = client.available();
  if (n > 0) {
    n = client.read(buf, n < (int)sizeof buf ? n : sizeof buf);
    if (n > 0) {
      n_tcp_in += n;
      usb_write_all(buf, n);
    }
  }
  // カセット → PC
  int m = Serial.available();
  if (m > 0) {
    m = Serial.read(buf, m < (int)sizeof buf ? m : sizeof buf);
    if (m > 0) {
      n_usb_in += m;
      client.write(buf, m);
    }
  }
  if (n <= 0 && m <= 0) delay(0);
}

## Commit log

2026-09-26 Add FC-MAGICON hardware (rev0.2 in progress): schematic, PCB placement, footprints, scripts, spec
    [FC-MAGICON.kicad_pcb, FC-MAGICON.kicad_sch, bom.csv]
2026-09-26 rev0.2: routed 2-layer board (DRC clean), USB spare land J6, trimmer VR1 for expansion audio, wider power/audio traces, gerbers, 3D images, updated spec
    [FC-MAGICON.kicad_pcb, FC-MAGICON.kicad_sch, bom.csv]
2026-09-26 Add bus_test firmware (pico-sdk 2.3.1): serves a 440Hz test ROM on the CPU bus, counts writes, bring-up guide
2026-09-26 Add chr_test firmware (PPU CHR response via AD0-7 capture before /RD), tiny 6502 assembler, docs
2026-09-26 Add STEP models, part guide sheet, cartridge label
    [FC-MAGICON_r0.2_board.step, FC-MAGICON_r0.2_parts.step, core2350b_board.step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]
2026-09-26 Back silkscreen: logo, MADE BY SHIMA-R7, spec table; regenerate gerbers/STEP
    [FC-MAGICON.kicad_pcb, FC-MAGICON.step, FC-MAGICON_r0.2_board.step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]
2026-09-26 Mount R1 on the back so Q1 can lie down; front silk logo
    [FC-MAGICON.kicad_pcb, FC-MAGICON.step, FC-MAGICON_r0.2_board.step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]
2026-09-26 Label: sharper print (1200dpi, crisp logo), glossy/photo-quality L-size printing
2026-09-26 Remote desktop mode: firmware (PPU position tracking), 6502 driver (pad + Family BASIC keyboard), nesframe encoder, PC app, sim test
2026-10-15 Checkpoint standalone video, PIO audio, hardware diagnostics and power research
2026-10-31 Add native APU video playback and fix cartridge reply deadlines
    Compile user-provided MIDI into a three-voice native APU stream, generate the 6502 playback driver during the build, and accept the score header outside the repository.
    Precompute control-register replies so frame handshakes and RMW counters meet the CPU read deadline. Discard expired PPU DMA replies and distinguish valid zero-direction entries. Include ADPCM compatibility, regression tests, build instructions, and the new-board hardware validation record.
    Validated: APU and PCM build profiles; MIDI, 6502 NMI timing, real C control paths, PPU deadline model, and C/Python ADPCM tests. The tested hardware snapshot completed 1,93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
2026-11-03 Add ESP32-C6 Wi-Fi transport to remote desktop firmware
2026-11-08 Add C6 wireless firmware and media updates with native DAC playback
    Publish full-frame video and RAM-resident DAC playback sources, C6 SWD/USB update tools, and OLED power-decoupling hardware validation. Preserve the initial Wi-Fi startup failure in the report and keep media and credentials out of the source snapshot.
